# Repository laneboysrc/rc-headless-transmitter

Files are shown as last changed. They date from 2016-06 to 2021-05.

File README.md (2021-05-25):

# Smartphone / Web browser configurable RC transmitter

This project implements a 2.4 GHz RC transmitter using the NRF24L01+ wireless module and the STM32F103C8T6 micro-controller.

The term *headless* comes from the IT industry, where a headless system is one that does not provide a user interface itself, but is rather configured remotely. Within this project, *headless* means that the transmitter does not have a display or buttons for configuration. It relies on remote configuration through a web-browser running on a Smartphone, Tablet or computer.

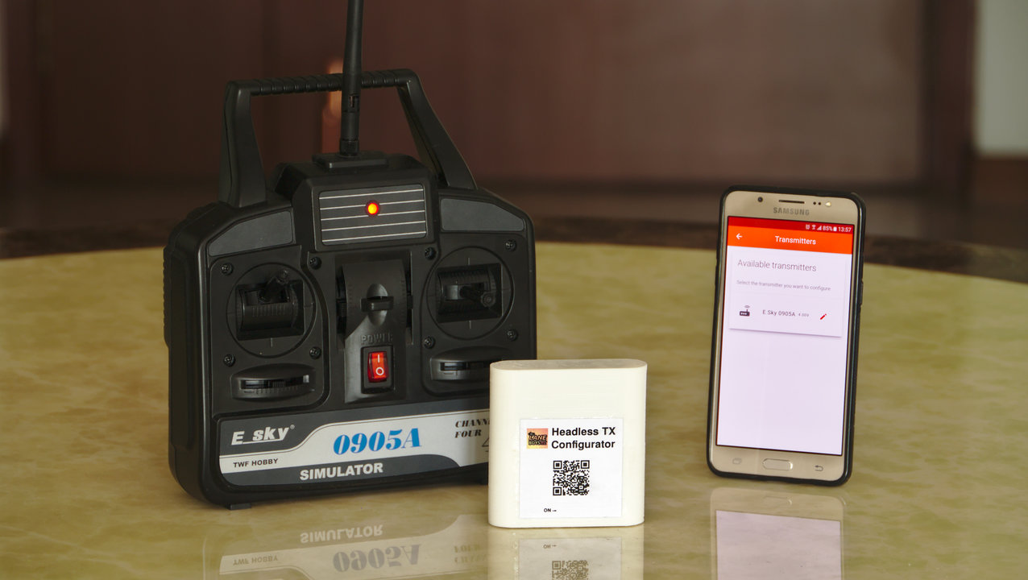
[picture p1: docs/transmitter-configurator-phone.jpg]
transmitter, configurator and web-app


The motivation for this project was to upgrade old AM/FM RC transmitter hardware, and to turn a cheap RC simulator into a fully operational transmitter that supports multiple models.

By keeping the user interface for configuration out of the transmitter, we don't need to perform complicated mechanical modifications to add a display and buttons. We only replace the old electronics with a modern 32 bit ARM micro-controller and a reliable 2.4 GHz transceiver wired on a prototyping board.

The transmitter is currently compatible with HobbyKing HKR3000 and HKR3100 receivers, as well as the [LANE Boys RC nrf24le01-rc](https://github.com/laneboysrc/nrf24l01-rc) DIY receivers. It runs off a 1S Li-Ion battery.

## How it works

The *headless transmitter* works like any low-end 2.4 GHz RC system on the market: power it on, and use it with the model you have it setup for.

However, unlike low-end transmitters, the *headless transmitter* supports advanced features like expo, mixing, failsafe and more.

In order to configure those features, you need to use a web-browser on your Smartphone, Tablet or computer.

To be able to connect your Smartphone to the transmitter, we need to translate between different radio protocols: The transmitter uses a proprietary RF protocol, while the Smartphone supports Wi-Fi. This translation takes place in a small, external box called *configurator*.

When you want to configure your *headless transmitter*, you turn the *configurator* on, connect your phone to the Wi-Fi access-point the *configurator* provides, and launch the configuration web-app to perform the configuration. When you are done, the changes are automatically saved in the transmitter and persist over power cycles.

The *configurator* is built from an **Orange Pi Zero**, with an extra RF module for the connection to the *headless transmitter*.

The Smartphone has a large amount of persistent memory. This allows us to store configurations for multiple models. When we want to reconfigure the transmitter for another model, we simply download the model configuration configuration into the *headless transmitter*. This only takes a few seconds.

The power consumption of the transmitter is low: A single 800 mAh Li-Ion battery keeps the transmitter running for approximately 15 hours. The *configurator* is only used rarely and can be powered from a suitable power bank.

## Cost

When sourcing the modules from China, a transmitter can be built for less than USD 10. The *configurator* hardware cost is less than USD 20. You only need one *configurator*, regardless of how many *headless transmitters* you have.

## Getting started

Please consult the [INSTALL.md](INSTALL.md) file for instructions.

The [docs/](docs) folder contains various documents explaining details for the architecture.

The *headless transmitters* hardware is described in the [transmitter/](transmitter/) folder.

The *configurator* is based on the Orange Pi Zero. Its hardware documentation resides in
[configurator/orangepizero/HARDWARE.md](configurator/orangepizero/HARDWARE.md).

The *web-app* can be accessed from [https://laneboysrc.github.io/rc-headless-transmitter](https://laneboysrc.github.io/rc-headless-transmitter)

## WORK IN PROGRESS

This project is not finished yet. Refer to the [TODO](TODO.md) list for items that we plan to implement in the future.

At the moment the project has only been tested on Android using Chrome and Firefox, and on PCs running Chrome or Firefox.

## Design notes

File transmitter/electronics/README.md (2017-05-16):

This folder contains the schematics and layout of the *headless transmitter* hardware.

[BOM.txt](BOM.txt) contains a list of all components.

The project is made using [KiCad](http://kicad-pcb.org/). For convenience the schematics are also available in [PDF format](stm32f1-nrf24l01-transmitter.pdf).

Note that the PCB designs are not actual circuit board designs, but rather meant to be built on a [Perfboard](https://en.wikipedia.org/wiki/Perfboard).

There are different variants that we adapted to suit different transmitters we modified.

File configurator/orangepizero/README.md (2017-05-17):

This folder contains files related to the Orange Pi Zero-based configurator bridge that allows to configure the headless transmitter via a Wi-Fi connected computer or Smartphone.

Refer to [INSTALL.md](INSTALL.md) of how to configure the Orange Pi Zero.

The [etc/](etc/) and [var/](var/) folders contains sample configuations as described in [INSTALL.md](INSTALL.md).

The [mechanics/](mechanics/) folder contains mechanical files to 3D-print a case for the Orange Pi Zero.

The [openocd/](openocd/) folder contains script and configuration files to flash the nRF51822 and STM32F103 from the Orange Pi Zero. Refer tp [openocd/README.md](openocd/README.md) for details.

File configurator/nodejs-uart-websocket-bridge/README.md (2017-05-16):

# UART to Websocket bridge protocol

This tool can be connected to a *headless transmitter* via the UART. It exposes the *headless transmitter* to a *configurator* using the WebSocket protocol.

This program is used on the Orange Pi Zero to bridge the nRF51822, which in turn bridges the UART to the *headless transmitter*, to the web-app.

Please refer to the [configurator](../../docs/configurator.md) documentation for more information.

## Build instructions

Install NodeJS [http://nodejs.org/](http://nodejs.org/)

Run `npm install` to fetch the required modules.

You can then run `npm start /dev/ttyS1`.

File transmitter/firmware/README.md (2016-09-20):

This directory contains the firmware that goes into the [*headless transmitter*](https://github.com/laneboysrc/rc-headless-transmitter).

It runs on the STM32F103C8T6 micro-controller.

The software makes used of [libopencm3](http://libopencm3.org/).

The firmware is built using a [GNU Make](https://www.gnu.org/software/make/) makefile. The compiler is [ARM GCC toolchain](https://launchpad.net/gcc-arm-embedded), version 5.2.1. [OpenOCD](http://openocd.org/) is used to program the firmware into the micro-controller.

In the [Makefile](Makefile), adjust the variable `GNU_INSTALL_ROOT` and `OPENOCD` to match your installation.

Run

    make

to build the firmware. When done, run

    make program

to flash the firmware into the micro-controller.

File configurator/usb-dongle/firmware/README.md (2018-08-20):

This directory contains the firmware that implements a WebUSB compatible dongle. The dongle can be used by the web-app when using a browser with WebUSB support (currently Chrome/Chromium only).

It runs on the STM32F103C8T6 micro-controller that controls the nrf51-nrf-uart-bridge.

The software makes used of [libopencm3](http://libopencm3.org/).

The firmware is built using a [GNU Make](https://www.gnu.org/software/make/) makefile. The compiler is [ARM GCC toolchain](https://launchpad.net/gcc-arm-embedded), version 5.2.1. [OpenOCD](http://openocd.org/) is used to program the firmware into the micro-controller.

In the [Makefile](Makefile), adjust the variable `GNU_INSTALL_ROOT` and `OPENOCD` to match your installation.

Run

    make

to build the firmware. When done, run

    make program

to flash the firmware into the micro-controller.

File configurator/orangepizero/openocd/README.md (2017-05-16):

If you don't have a SWD programmer to flash the nRF51822 or the STM32F103, you can use the Orange Pi Zero in conjuction with the Open OCD.

    git clone https://github.com/ntfreak/openocd
    sudo apt-get install libtool texinfo pkg-config

    cd openocd
    ./bootstrap
    ./configure --enable-sysfsgpio
    make
    sudo make install

This folder contains two configuration scripts and shell scripts to flash the nRF51822 or STM32F103C8T6. They use different GPIO ports on the Orange Pi Zero, which means the nRF51822 can stay connected when flashing the STM32F103.

The nRF51822 uses pins

    3 GPIO12        SWCLK
    5 GPIO11        SWDIO

the STM32F103 uses pins

    16 GPIO19       SWCLK
    18 GPIO18       SWDIO

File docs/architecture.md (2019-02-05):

# Headless TX  |  STM32F1 NRF24L01+ Headless Transmitter Architecture

## Model vs Transmitter hardware configuration

* Ideally we are able to drive the same car (airplane, boat ...) with different transmitter hardware, with the system automatically adapting to the transmitter hardware
* This implies that inputs are tagged (e.g. Aileron, Rudder, Elevator, Steering, Throttle, Gear, ST-Trim, ST-DR, TH-Hold ...) so that the mixer can read from the right values
* An input may have multiple tags (Steering, Rudder) but each tag must only be assigned once
* Inputs may have 0..100 on one transmitter, and -100..0..100 on another one, i.e. they may be with or without center point!
* If a mixer can not find its input, the input is considered value "0" (center position)
* The direction is normalized:
  - forward, more, right: positive values
  - backward, less, left: negative values

    Note: this is in line with the HobbyKing HK310. However, in the old 27MHz
    AM car transmitters the behavior is different
      - backward, right: positive values
      - forward, left: negative values

* So the "mixer" describes the vehicle, but the input section describes the transmitter
* The *configurator* can change mixer configuration as well as hardware configuration

* Trims have to be assignable to a specific input. Trims may be either a pair of push-buttons or a potentiometer, or be mechanical (i.e. not existent from a software point-of-view).

## Overall transmitter architecture

    +----------------+    +-----------------------------------+    +------------+   +--------+
    |                |    |                                   |    |            |   |        |
    |     INPUTS     |    |              MIXER                |    |  CHANNELS  |   |   RF   |
    |                |    |                                   |    |            |   | module |
    |                |    |   +---------------------------+   |    |  +-------+ |   |        |
    |  sticks,       |    |   |        Mixer unit         |   |    |  |  RF   | |   |        |
    |  pots,         |    |   +---------------------------+   |    |  |      +------->       |
    |  push-buttons  |    |   +---------------------------+   |    |  |       | |   |        |
    |  switches    +------->  |        Mixer unit         |  +------> +-------+ |   |        |
    |                |    |   +---------------------------+   |    |  +-------+ |   |        |
    |                |    |   +---------------------------+   |    |  |Virtual| |   |        |
    |                |    |   |                           |   |    |  |       | |   |        |
    |                |    |   +---------------------------+   |    |  |       | |   +--------+
    |                |    |                                   |    |  +-------+ |
    |                |    |                                   |    |            |
    +----------------+    |                                   |    +-----+------+
                          |                ...                |          |
                          |                                   |          |
                          |                                   |          |
                    +------>  +---------------------------+   |          |
                    |     |   |        Mixer unit         |   |          |
                    |     |   +---------------------------+   |          |
                    |     |                                   |          |
                    |     +-----------------------------------+          |
                    |                                                    |
                    |                                                    |
                    +----------------------------------------------------+

    (Diagram made with the awesome asciiflow.com)

## Inputs
To achieve maximum flexibility, the inputs (sticks, switches, pots etc) of the transmitter have been abstracted in three levels.

### PCB inputs
*PCB inputs* describe all available input ports on the circuit board of the transmitter, and their potential function. Since *PCB inputs* are determined by the hardware, they are a compile-time only configuration.

In software we reference them as *pcb_inputs*.

The STM32F103C8T6 based hardware using the AliExpress board has the following *PCB inputs*:
* 9 analog/digital inputs
    * Can be configured as analog or digital inputs
* 8 digital inputs

### Hardware inputs

Some, or all, *PCB inputs* are connected to control devices such as sticks, pots or switches in a particular transmitter. We refer to those as *Hardware inputs*. There is a 1:1 relationship between a *Hardware inputs* and a *PCB inputs*. A *Hardware input* narrows down the *PCB input* type to one of the following:

* Analog with center detent, spring-loaded auto-return to center: -100..0..100
* Analog with center detent: -100..0..100
* Analog without center detent: -100..100
* Analog without center detent, positive only: 0..100
* Switch on/off: Open / Vcc (pull-down)
* Switch 3-position:  GND / Open / Vcc
* Momentary: Open / Vcc (pull-down)

The analog type *Hardware inputs* can only be assigned to *PCB inputs* of type analog/digital.

For the analog inputs the *Hardware input* data structure holds the endpoint- (and where applicable center-point) calibration values.
*Hardware inputs* are usually setup once when configuring a newly built transmitter.

In software, we reference *Hardware input* as *config.tx.hardware_inputs*.

### Logical inputs
One or more *Hardware input* can be combined to form a *Logical input*, which can be referenced as user input for the mixer.

Like *Hardware inputs*, *Logical inputs* are configured once for each physical transmitter hardware and do not need to be changed when configuring models.

Every logical input can have up to 5 *labels* that indicate the potential function of the input. This way one transmitter can have a "Dual Rate" switch, while another one can have a "Dual Rate" potentiometer. The mixers in the model configuration use the *label* "Dual Rate" to retrieve the input values regardless of the type.

In software, we reference the *Logical inputs* as *config.tx.logical_inputs*.

There are several types of *logical inputs* available

* Analog
    * Can only have a single Analog type *Hardware input* assigned
* Momentary
    * Can only have a single Momentary type *Hardware input* assigned
* Switches
    * n-position switch
        * Can have a single Momentary type *Hardware input* assigned
            * Each press toggles to the next position
            * Can be configured to:
                * increment, loop
                * decrement, loop
                * saw-tooth
                * single-click increment, double-click decrement
            * Transmitter beeps the current number?
        * Can have a two Momentary type *Hardware input* assigned
            * up/down
        * n=2: can have a single on/off switch *Hardware input* assigned
        * n=3: can have a single 3-position switch *Hardware input* assigned
        * n=4..12 can have n on/off switches *Hardware input* assigned
            * In theory we could do with n-1 digital inputs, using the state when all inputs are open as first position. However, this may cause issues that the first position is triggered when switching between the other positions, as contacts may temporarily open.
            * Therefore it is better to use n inputs and treat "all inputs open" as well as "more than one input closed" as error condition.
    * BCD switch n=2..4
        * Must have n on/off switches *Hardware input* assigned
        * Output values are 0..(2^n-1)
* Trims
    * Can have two Momentary type *Hardware inputs* assigned (up/down)
    * Can have a single Analog type *Hardware input* assigned (with or without detent, but must not be *Analog without center detent, positive only* or *Analog with auto return to center*)

**Every *Switch* or *Trim* that uses a Momentary type *Hardware input* must remember their state across power cycles**

### Input API
The mixer can access the inputs by passing a *label* to one of the following input functions.
If no input with the label is configured, the value returned by any of the functions is '0'.

`INPUTS_get_value(label_t l)`
Returns the value for the input with the label *l* in the range of

    CHANNEL_100_PERCENT .. CHANNEL_CENTER .. CHANNEL_N100_PERCENT

`INPUTS_get_switch_value(label_t l)`
The  *switch value* for Momentary and Switch functions is 0..n, where n is the number of positions the switch has. The  *switch value* for analog inputs is 0 or 1, depending whether the analog input is -100..0 or 0..100.
The switch value is retrieved in mixer-units to check whether a mixer-unit is enabled or disabled.

`INPUTS_get_trim(label_t l)`
Returns the trim value for the input corresponding to the label.

## Mixer
The mixer is derived from the DeviationTx project, but modified. The mixer calculates signed values where 100% corresponds to the value 10000. Internally the mixer calculates with signed 32 bit resolution.

### Mixer unit
The mixer unit is derived from the DeviationTx project. Each mixer-unit performs a simple function:

    if (Switch) then
        Destination  op  f(Curve, OptionalInvert(Source)) * Scalar + Offset + OptionalInvert(Trim)
    endif

where:
  - Switch: a switch state that, if true, enables the mixer unit. If Switch is <None> then the mixer unit is always enabled.
  - Destination: The destination channel that receives the output of the mixer unit.
  - op: The operation to perform. Can be
    * = replace destination channel value with output of the mixer unit),
    * += add mixer unit output to current destination channel value
    * *= multiply mixer unit output, with `CHANNEL_100_PERCENT` being treated as 100%, with the current destination channel value
    * MAX (whichever is greater, the current output channel value or the output of the mixer)
    * MIN (whichever is smaller)
  - f(): One of the curve functions applied to the input source
  - OptionalInvert: Switch to invert the incoming Source
  - Source: The input source for the mixer unit. Can be
    - Phyiscal transmitter inputs (sticks, pots, switches, push-buttons)
    - Channels (output channels as sent to the receiver)
    - Virtual channels (10 available for intermediate results in chained mixer units)
  - Scaler: A scaling factor
  - Offset: An offset value to move the result up or down
  - Trim: If enabled then the trim value (range +/-100) is added to the mixer unit output, taking source channel inversion into account

Multiple mixer units can be configured to operate on the same destination. The order of which the mixer units are configured plays an important role of the final resulting channel value.

The mixer unit also receives a *tag* that is not used by the transmitter but provides information to the mixer UI in the *configurator*. Since high-level mixers in the UI may require more than one mixer-unit to implement, the UI can use the tags to identify the mixer-units that belong together and the corresponding high-level mixer function. This is currently not implemented.

### Output channel configuration
After all mixers have been processed, each output channel has a value that needs to be sent to the receiver over the air. Before passing the channel value to the radio protocol, a final set of operations are performed to tweak the corresponding servo outputs:

- Normal/Reverse
- End points -/+
- Sub-trim (applied after scale/endpoints; We want this independent of scale)
- Fail-safe value
- Limit +/ (just hard limits, checked last)
- Speed (0..250, speed of output change in *degrees per 100 ms*)

## Battery indication:

* LED lights up when powered
* LED blinks when battery is low
* Regular beep when battery is low, changing to a more alarming sound when the battery is nearly depleted
* PWM output to drive an analog meter, configurable to adjust full-scale value

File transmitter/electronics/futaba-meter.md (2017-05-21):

# Futaba FP-2F analog meter

R = 400 Ohm
Full scale: 450 mV /
Red to orange: 225 mV /

The needle moves until 480mV (needle at far right), which should be our design maximum.

So we need a voltage divider from 3.3V to 0.48V, with the bottom resistor being 400 Ohm

      3.3       0.48            3.3 * 400
    ------- = -------   =>      --------- - 400 = x   =>   x = 2350 ohm  ~ 2200 Ohm
    x + 400     400                0.48

If we use 2k2, we get a maximum voltage of 508 mV, which is plenty.

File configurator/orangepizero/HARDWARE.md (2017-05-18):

# Hardware parts
Orange Pi Zero (256 MB):
[https://www.aliexpress.com/store/product/New-Orange-Pi-Zero-H2-Quad-Core-Open-source-development-board-beyond-Raspberry-Pi/1553371_32760774493.html](https://www.aliexpress.com/store/product/New-Orange-Pi-Zero-H2-Quad-Core-Open-source-development-board-beyond-Raspberry-Pi/1553371_32760774493.html)

The CPU on the Orange Pi Zero runs very hot, even when idling. It is recommended that you obtain a suitable heat sink.

CORE51822 (B):
[https://www.aliexpress.com/wholesale?catId=0&initiative_id=SB_20170515221607&SearchText=core51822+b](https://www.aliexpress.com/wholesale?catId=0&initiative_id=SB_20170515221607&SearchText=core51822+b)

NOTE: other nRF51822 based modules may work as well, but have different pin-outs. You must ensure to match the pin names instead of the module pin numbers!

You need a Micro SD card. 4 GB is plenty, but nowadays cards start at 16 GB anyway.
Do get a good, reliable card! We have good experience with Sandisk Ultra 16 GB (SDSQUNC model, red and silver color).

# Connections

The CORE51822B modules gets connected to the Orange Pi Zero 26-pin header as follows:

    Orange Pi Zero                    CORE51822B
    (26 pin connector)

    1  3V3                            12 VCC
    3  GPIO12 (SWCLK)                 32 SWCLK
    5  GPIO11 (SWDIO)                 31 SWDIO
    6  GND                            11 GND
    8  UART1_TX                       25 P11 (`UART0_CONFIG_PSEL_RXD`)
    10 UART1_RX                       23 P09 (`UART0_CONFIG_PSEL_TXD`)

# Optional shut-down button

Unless you are using a "frozen file system" on the Orange Pi Zero, one should always shut the operating system down before removing power to avoid accidental corruption of the file system.

For this purpose the configurator can monitor a push-button on GPIO6 of the Orange Pi Zero. When the button is held for more than 2 seconds the Orange Pi Zero shuts down.

    Orange Pi Zero
    (26 pin connector)

    7  GPIO6                          power-off button

The power-off button switch to GND (Orange Pi Zero pin 6) and must have a 1..100k Ohm pull-up resistor to 3V3 (Orange Pi Zero pin 1).

                               +
                               | 3V3
                               |
                               |
                               |
                             +---+
                             |   |
                             |   | 1..100kOhm
                             |   | value not critical
                             |   |
                             +---+
                               |
                               +----------------+  GPIO6
                               |
                               |
                           X   +
                       +   XXX
                       +----+XX     push-button
                       +      XX
                               X
                               |
                               |
                               |
                               |
                               |    GND
                              +-+

# Optional OpenOCD SWD programming pins for the STM32F103C8T6 in the transmitter

If you don't have an ST-Link or similar programmer for the STM32F103 used in the transmitter, you can program it with the Orange Pi Zero. The following pins need to be connected.

    14 GND    -> STM32F1 GND
    16 GPIO19 -> STM32F1 SWCLK
    18 GPIO18 -> STM32F1 SWDIO

The [openocd/](openocd/) folder contains a shell script and configuration file to use those pins.

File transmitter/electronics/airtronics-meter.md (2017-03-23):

# Airtronics analog meter

R = 670 Ohm
Full scale: 400mV / 600uA
Orange to full: 200mV / 300uA
Red to orange: 140mV / 200uA

The needle moves until 500mV (needle at far right), which should be our design maximum.

So we need a voltage divider from 3.3V to 0.5V, with the bottom resistor being 670 Ohm

      3.3       0.5             3.3 * 670
    ------- = -------   =>      --------- - 670 = x   =>   x = 3752 ohm  ~ 3900 Ohm
    x + 670     670                0.5

If we use 3k9, we get a maximum voltage of 483 mV, which is plenty.

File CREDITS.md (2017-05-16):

This project would not have been possible without the LANE Boys beinging able to stand on the shoulders of giants:

### Deviation

http://deviationtx.com/

A replacement firmware designed primarily for the Walkera Devo series RC Transmitters. Great project to study RC transmitter architecture.

### ER9X

https://github.com/MikeBland/mbtx

er9x/ersky9x radio firmware. This is how it all started. Thanks!

### libopencm3

http://libopencm3.org/

Open Source ARM Cortex M microcontroller library. Light-weight, easy to use, not too much abstraction. Just works!

### KiCAD

http://kicad-pcb.org/

Make truely open Schematics and Circuit Boards with this easy to use software.

### Material Design Lite

https://getmdl.io/

MDL allowed us to get a reasonable modern UI with little skills required. No complicated tool chain, just JS and CSS required.

### Google fonts

https://fonts.google.com/specimen/Roboto
https://design.google.com/icons/

The icon font was especially helpful to get consistent looking icons. Super!

### sw-precache

https://github.com/GoogleChrome/sw-precache

Need to make your web-app work offline? Unbelievably easy with this brilliant project!

### spinkit

http://tobiasahlin.com/spinkit/

A nice and easy to use library of CSS spinners.

### Gnu GCC

https://launchpad.net/gcc-arm-embedded

Fantastic compiler. Any platform. Just works.

### OpenOCD

http://openocd.org/

Powerful debugger and programmer. Excellent out-of-the-box experience and soooo configurable.

### STM

http://www.st.com/

Excellent value for money micro-controllers. Their ST-Link debugger comes on inexpensive Nucleo boards and works great even for programming the Nordic MCU.

### Nordic

http://nordicsemi.com/

Great 2.4 GHz Radio, decent software stack, fair price. Thanks for opening up your SDK and documentation in the recent years!

### Armbian

https://www.armbian.com/

Makes cheap Orange Pi boards work!

### Node.js and npm

https://nodejs.org/en/
https://www.npmjs.com/

Normally we use Python for scripts and utilities. But since Node.js was needed for using Webpack anyway, we used it instead. Worked great thanks to the library support at npm.

### Webpack and "Developing with Webpack"

http://webpack.github.io/
http://survivejs.com/webpack/developing-with-webpack

Web front-end development has become surprisingly complicated -- tool-wise -- in the last years. Thanks due to the guide at survivejs we were able get Webpack do what we needed without having to spend a lot of time.

### JSHint, ESLint

http://jshint.com/
http://eslint.org/

Great to find mistakes in the editor before you see them in the console log of your browser.

### strftime for JavaScript

https://github.com/samsonjs/strftime

Pity that this functionality isn't in the Javascript Date library. Thanks for scratching an itch.

### Sortable

http://rubaxa.github.io/Sortable/

Brilliant library to enable interactive re-ordering of lists. Super-simple to use, yet powerful.

### PathJS

https://github.com/mtrpcic/pathjs/blob/master/path.js

Old-skool client-side routing library that allowed us to make a single page web-app. Surely considered outdated, but just right for our needs.

### Favicon Generator

http://realfavicongenerator.net/

Great on-line tool to make all the different flavors of icons needed to get a modern web-app integrated on various platforms.

### Mozilla Developer Network MDN

https://developer.mozilla.org/en-US/

The MDN was extremely helpful to brush up on the latest web technologies. The articles are concise and link to references.

### StackOverflow

http://stackoverflow.com/

Have a programming-related problem? This excellent community sure has it solved already.

### DuckDuckGo

https://duckduckgo.com/

Just like Google was in the beginning.

### Can I Use.com

http://caniuse.com/

Extremely useful website to decide which of the hot new web technologies can be actually used.

### OpenSCAD

http://www.openscad.org/

The Programmers Solid 3D CAD Modeller. What a pleasure to use!

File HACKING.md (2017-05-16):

This project uses different type of microcontrollers:
* [STM32F103](http://www.st.com/content/st_com/en/products/microcontrollers/stm32-32-bit-arm-cortex-mcus/stm32f1-series/stm32f103.html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)
* [Nordic nRF51822](https://www.nordicsemi.com/eng/Products/Bluetooth-low-energy/nRF51822)

On the software side, you need to be familiar with [Git](https://git-scm.com/), the [ARM GCC toolchain](https://launchpad.net/gcc-arm-embedded), [GNU Make](https://www.gnu.org/software/make/), [OpenOCD](http://openocd.org/) and the [ST-Link programmer](http://www.st.com/content/st_com/en/products/development-tools/hardware-development-tools/development-tool-hardware-for-mcus/debug-hardware-for-mcus/debug-hardware-f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).

If you are on Windows it may be easier to compile the software with [Git Bash](https://git-for-windows.github.io/) shell.

The web interface and associated dev tools are built in JavaScript using [Node.js](https://nodejs.org/), [Webpack](http://webpack.github.io/) and the [Material Design Lite framework](https://getmdl.io/).

**IMPORTANT**
This project makes use of Git submodules. Please clone it by running:

    git clone --recursive https://github.com/laneboysrc/rc-headless-transmitter.git

Alternatively, run the following commands in the project root:

    git submodule init
    git submodule update

---

# GH-PAGES

We can host the web-app via Github pages conveniently. Since it is served via HTTPS we can use ServiceWorker and other goodies.

## Setup

In the root of the project, execute

    git clone https://github.com/laneboysrc/rc-headless-transmitter.git --branch gh-pages --single-branch gh-pages

This creates a folder named `gh-pages` with the web-app source code, cloned from the current state of the rc-headless-transmitter's `gh-pages` branch. Note that the `gh-pages` is in `.gitignore` of the `master` branch, so it does not appear in the `master` branch.

When building the web-app (run `npm run build` in `configurator/web-app`), the files are automatically placed into the `gh-pages` folder.

To update the web-app on Github, go into the `gh-pages` folder, commit the changes, and run `git push`.

Source:
[http://stackoverflow.com/questions/1778088/how-to-clone-a-single-branch-in-git](http://stackoverflow.com/questions/1778088/how-to-clone-a-single-branch-in-git)

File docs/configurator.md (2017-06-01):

# Configurator

Since the *headless transmitter* does not have a user interface, we need an external device to configure it. We call this device or software *configurator*.

When connected to a *headless transmitter*, the *configurator* can provide the following functions:

* Live configuration of inputs, mixers, sub-trim values, end points, etc
* Live configuration of the transmitter hardware (inputs, their names and types, trims, invert)
* Live mixer configuration (expo, dual-rate, 4-wheel steering, elevons ...)
* Live output configuration (reversing, endpoints, sub-trim ...)
* Calibration function for analog inputs (sticks, pots)
* Live display of stick, pot, switch, push-button, trims and output channel data
* Show the battery state

The *configurator* can also provide other functionality:

* Maintain a database of models and transmitter configurations

The *configurator* functionality can be implemented in different ways:

* Custom device

    Dedicated embedded device with display and buttons. Similar to a programming box for an ESC.

* Web-app

    An application that runs in a Web browser

* Smartphone app

Using the a *web-app* as *configurator*, which works in any modern browser, is the most attractive option as it can be used on a wide range of devices: PC, Smartphone, Tablet.

Smartphones even allow web-apps to be installed as icon on the home screen and run full-screen. They can also pre-cache the whole web-app, so it can be even accessed when there is no Internet connection. This way we get an app-like user experience.

## Principle of operation

The *headless transmitter* performs its operation based on a configuration that is stored in its persistent memory (Flash memory of the micro-controller). The configuration determines which inputs provides what functions, and how the inputs are mixed to form output channels. Please refere to the [architecture documentation](architecture.md) for details.

The firmware is designed such that the configuration can be changed at run-time; the *headless transmitter* firmware applies the configuration dynamically.

The configuration comprises of settings that are *hardware specific*, and setting that are *model specific*. While the hardware and model specific settings are kept separate, they are stored in one area of consecutive memory.

The *headless transmitter* provides an API that allows an external device -- the *configurator* -- to change the configuration.

The API is very simple: Read parts of the configuration memory, write parts of the configuration memory, and copy from one memory area to another memory area within the configuration memory.

The advantage of this method is that the implementation in the *headless transmitter* is very simple. On the down-side, the *configurator* must know the precise memory layout of the all the elements within the configuration memory.

## Transports

The *configurator* must be able to connect to a *headless transmitter* in order to perform operations on the API provided by the *headless transmitter*.

The *headless transmitter* offers the following transports natively:

* nRF Enhanced Shockburst protocol

    The nRF protocol makes use of the nRF24L01 used to send data to the model. *configurator* data is sent in pauses when no model transmission is taking place.

* UART protocol

    The UART (serial port) protocol is available by connecting to the UART provided by the micro-controller. The UART protocol is currently not implemented on the *headless transmitter*, but used internally in the *nrF-to-WebSocket bridge* described below.

The design goal is to keep the protocol running over the different transports the same, so that the transports appear transparent to the *configurator*.

### Bridging

Unfortunately a *web-app* is not able to utilize any of the transports provided by the *headless transmitter* directly.

To be able to make a *Configurator web-app*, we need a bridging mechanism that goes between the *headless transmitter* and the *configurator* running in the web browser.

On the web browser side, we have **HTTP** and **WebSocket** protocols to our disposals.

Another potential transport would be **BLE**. The *Web Bluetooth* protocol allows web apps to connect to BLE devices. However, *Web Bluetooth* is relatively new and not mature yet.

From a physical implementation point-of-view, the bridge can be a separate box, or integrated into the *headless transmitter*.
We are currently using a separate box as bridge, which can be used for multiple *headless transmitter*. On the down-side, now we have to bring yet another (small) box along while playing with our RC toys.

### Bridge protocol considerations

Ideally the protocol that a *headless transmitter bridge* provides to the *configurator* is equivalent, or at least very similar, to the native transport protocols supported by the *headless transmitter*.

### WebSocket to nRF/UART bridge

The cheapest way to build a bridge with a HTTP/WebSocket interface is by using **ESP8266** modules. The older ESP8266 modules have only a UART interface and not a lot of memory, but newer versions provide access to an SPI port that would allow direct interfacing with a nRF24L01 module.

In order to relief the ESP8266 firmware from the real-time requirements of dealing with the nRF24L01 module, the current bridge implementation uses a nRF51822 module with integrated ARM micro-controller to perform the real-time nRF protocol, sending and receiving information over UART to the ESP8266.

Unfortunately the ESP8266 can not implement a HTTPS server using TLS encryption. TLS is required so that the web-app, which is required to be hosted via HTTPS to access off-line features like ServiceWorker, can access it via secure WebSocket.
We therefore abandoned the ESP8266 implementation. An old, HTTP-based, version can still be found in the project's commit history.

Luckily with the rise of single-board computers (SBC) like the Raspberry Pi, a more powerful alternative is at hand. We opted for the **Orange Pi Zero**. It costs only USD 7 plus shipping (256 MBytes RAM version, good enough for our purpose). It has built-in Wi-Fi that works just fine as Access Point.

On the **Orange Pi Zero** we can install **Armbian**, an **Ubuntu-based OS**, use **NGINX** as web-server serving HTTPS with a self-signed certificate, and run a **NodeJS** program to interface with the nRF51822 module over UART.

In order to minimize interference between Wi-Fi and the nRF protocol, we run Wi-Fi on Channel 11. the nRF protocol uses mostly the lower channels of the 2.4 GHz ISM band.

The *WebSocket bridge* can also be simulated using NodeJS. This allows development of the *web-app* without using actual hardware.

## Security considerations

While this device falls in the category of *Toy*, we still must consider potential security issues.

When the *configurator* connects via the UART directly, the *headless transmitter* can trust the *configurator* -- after all, physical access to the *headless transmitter* was obtained.

Things are different when the *configurator* connects via one of the wireless methods. In case of an open system, anyone with a wireless *configurator* could connect to our transmitter and ruin our day. This may not even be malicious: Other *headless transmitter* users may accidentally connect to our transmitter while trying to configure their own unit.

A simple 4-digit pass-phrase can prevent accidental configuration from happening.

Since the pass-phrase is stored as part of the transmitter configuration, our own *configurator* could automatically log into the transmitter as it can retrieve the pass-phrase from its local database. Others would not have the configuration of our transmitter in their database, so they would need to enter the pass-phrase.

Do note: a malicious user could sniff the pass-phrase while we connect to our transmitter, or obtain it from a sync'ed copy of our database. But then, a malicious user can also sniff our address and bind data and directly manipulate our model; or simply jam the 2.4 GHz band. We therefore consider the pass-phrase being sufficient.

Following tradition, the default pass-phrase of a virgin transmitter is the same as we use on our luggage: '1234'.

## Making the configurator an App-like experience

Web technology has come a long way in the recent years. Today we can make *web-apps* that have an almost native look-and-feel on Smartphones, yet work cross-platform because they are technically web pages. Web-apps can store data on the device persistently, they can be installed to -- and launched from -- the home screen just like a native app, and they can even operate off-line thanks to the awesome *service worker* technology.

*Note: the current configurator web-app has only be tested on Chrome and Firefox, on Android. It is likely that it requires debugging to run on other platforms. Furthermore, only Chrome currently supports off-line web-apps.*

This comes at a small price: in order to be able to utilize a *service worker*, a web-app has to be served from a secure (HTTPS) domain. This, in turn, implies that the *bridge* has to be running over HTTPS as well.

Serving the web-app over HTTPS is quite easy as [Github](https://github.com) kindly provides projects to serve web pages via HTTPS for free ([Github Pages](https://pages.github.com)).

Another compromise we have to make is the use of self-signed certificates on the *nRF-to-websocket* bridge, which trigger security warnings in all modern web browsers. The user will have to go through certain steps to allow this self-signed certificate before the *configurator web-app* can access it.

## nRF protocol details

The nRF protocol integrates with the RF protocol that is employed in the HobbyKing HK300, HK310 and 3XS transmitters. We refer to this protocol as *HK310 protocol* from now on.

### The *HK310 protocol*

The *HK310 protocol* has the following properties:

* The legacy nRF24 protocol (non Shockburst version) is used at 250 KBps
* The address is 5 bytes long and is unique for each model
* All packets sent by the transmitter have a payload length of 10 bytes
* One burst of transmission occurs every 5 ms
* A transmission burst comprises of:
    - Two identical stick (or failsafe) packets, with data for 3 channels
    - A bind packet, sent at low power with a fixed address on channel 81
* After each transmission burst, the the frequency is changed to the next in a list of 20 hop channels

One transmission burst takes about 1.2 ms.

    __MMMM_MMMM_BBBB________________________________MMMM_MMMM_BBBB_________

      <------------------- 5 ms ------------------->

    MMMM: Stick or Failsafe data, sent on the hop channel
    BBBB: Bind packet, sent on channel 81

One challenge in the *headless transmitter* was that, due the use of inexpensive nRF24+PA (power amplifier) module, we were unable to output at a really low RF power. Even at the lowest power setting the bind packets can be received from quite far away. In order to avoid interference with other RC transmitters, the *headless transmitter* therefore only outputs bind packets for the first 10 seconds after power on.

### Integrating with the *HK310 protocol*

We extend the transmission burst of the *HK310 protocol* with one more *configurator packet*. This implies that one *configurator packet* is sent every 5 ms.

    __MMMM_MMMM_BBBB_CCC____________________________MMMM_MMMM_BBBB_CCC_____

      <------------------- 5 ms ------------------->

    MMMM: Stick or Failsafe data, sent on the hop channel
    BBBB: Bind packet, sent on channel 81
    CCC: Configurator packet at 2 Mbps

The *configurator packet* use a different radio setup than the *HK310 protocol*:

* Enhanced Shockburst with auto-acknowledge (AA) enabled, with optional ACK payload
* 2 MBps data rate
* Variable payload length up to the maximum of 32 bytes
* 2-Byte CRC
* Lowest possible transmit power (at least on the *headless transmitter* side, which utilizes a RF amplifier)
* ARD is set to 500 us

The *headless transmitter* acts as the PTX (Primary role Transmitter, as defined in the nRF24 specification), the *configurator* acts as PRX (Primary role Receiver).

The *configurator* is able to send information to the headless transmitter as part of the Acknowledge procedure when receiving a packet from the *headless transmitter*.

From a protocol point-of-view, one could say that the *headless transmitter* is the master, and the *configurator* is the slave, with the master polling the slave in regular intervals.

### Overcoming reliability issues

Wireless protocols are inherent to interference and poor reception, resulting in lost packets.

To make it easier for users of the nRF protocol, the low-level implementation shall implement a two-byte packet buffer and inspect packet contents.

The nRF protocol is designed in such a way that every request by the *configurator* is answered by the *headless transmitter* in the next packet. For example, a `CFG_READ` packet is answered with `TX_REQUESTED_DATA`; `CFG_WRITE` is answered with `TX_WRITE_SUCCESSFUL`.

In case a transmission error occurs, the next successful packet received from the *headless transmitter* will not match the request sent, so the low-level implementation knows that something went wrong and can resend the packet.

A two packet buffer is required to achieve maximum throughput, as the nRF Shockburst protocol requires us to queue data before we can receive the answer to the previous request.

The above algorithm implies that packets may be executed out of order.

### nRF protocol states

The nRF Shockburst protocol is designed for one pair of PTX and PRX. Since there is a possibility that more than one *configurator* is in use at the same time, we must ensure that integrity is preserved. To achieve this, we only allow one *configurator* to connect to a *headless transmitter* at a given moment in time.

From a protocol view, we achieve this by differentiating between *NOT CONNECTED* and *CONNECTED* state.

### nRF protocol *NOT CONNECTED* state

This is the default state for both the *headless transmitter* and the *configurator*.

All communication in this state happens on the fixed nRF channel **79** with address **4C:42:72:63:78** (`LBrcx` in hex).

The *headless transmitter* sends a `TX_FREE_TO_CONNECT` packet whenever the transmission burst is transmitting on the first model hop channel. This means that `TX_FREE_TO_CONNECT` packets are sent every 100 ms (20 hop channels times 5 ms each).

Since there may be multiple *headless transmitter* on the air, the `TX_FREE_TO_CONNECT` packet contains the 8-byte UUID of the transmitter as well as a human-readable transmitter name so that we can differentiate between transmitters.

The *configurator* listens for `TX_FREE_TO_CONNECT` and shows the user a list of all transmitters in the neighborhood. When the user chooses a transmitter, the *configurator* replies with `CFG_REQUEST_TO_CONNECT` and changes its state to `CONNECTED`.
The `CFG_REQUEST_TO_CONNECT` packet contains the UUID of the transmitter to connect to, the pass-phrase, a unique 5-byte address and hop channel information.

When the *headless transmitter* receives a `CFG_REQUEST_TO_CONNECT` request with a matching UUID and pass-
phrase, it changes its state to `CONNECTED`.

The nRF24 PRX function itself does not provide a method to receive packets without acknowledging them. This would mean that if multiple *configurator* are present, each listening for `TX_FREE_TO_CONNECT` packets, every *configurator* will send ACK responses at the same time, causing issues.

To overcome this problem, the *headless transmitter* broadcasts the `TX_FREE_TO_CONNECT` packets with the `W_TX_PAYLOAD_NOACK` feature of the nRF24. This method transmits a packet without requesting the PRX to acknowledge it. All *configurator* can receive the `TX_FREE_TO_CONNECT` packet but no-one is acknowledging it.

In order to answer the `TX_FREE_TO_CONNECT` packet, immediately after the `TX_FREE_TO_CONNECT` was broadcast the *headless transmitter* sends yet another packet with a single byte payload, but using the lower 5 Bytes of the UUID as address. This packet requests an acknowledgement from a PRX and is unique for each transmitter.

This means that when a *configurator* sends a `CFG_REQUEST_TO_CONNECT` packet, it does so by configuring the address to the lower 5 Bytes of the UUID.

### nRF protocol *NOT CONNECTED* commands

Commands sent by the *headless transmitter* always start with `TX_`. Command sent by the *configurator* always start with `CFG_`.

All data is in little endian format, i.e. the least significant byte is transmitted first.

* `TX_FREE_TO_CONNECT`

    `0x30 uu uu uu uu uu uu uu uu uu tx tx tx tx tx tx tx tx tx tx tx tx tx tx tx tx b0 b1`

    uu:     Transmitter UUID 8 bytes
    tx:     Transmitter name 16 bytes (\0-terminated C-String [A-Z,a-z,0-9 ],
            padded with \0)
    b0, b1: Battery voltage in millivolts. Unsigned 16 bit integer.

    When sending this packet, the auto-acknowledge feature of the nRF24 is disabled. This is acheived by using the `W_TX_PAYLOAD_NOACK` nRF24 SPI command.

    Immediately after the packet was sent, another packet is sent, this time with the auto-acknowledge enabled (regular `W_TX_PAYLOAD` nRF SPI command). This command is sent on the address comprising of the lower 5 Bytes of the transmitter UUID. The payload is

    `0x30`

* `CFG_REQUEST_TO_CONNECT`

    `0x31 uu uu uu uu uu uu uu uu uu a0 a1 a2 a3 a4 p0 p1 oo sd`

    uu:     Transmitter UUID 8 bytes
    a0..4:  5 byte random nRF address to use during the connection
    p0..1:  unsigned 16-bit representation of the 4-digit pass-phrase
    oo, sd: offset and seed for a 7-bit Galois LFSR to calculate the hop channel sequence

    `oo` and `sd` are used to calculate the hop sequence for the configuration session.

    `sd` is the initial state of a [7-bit Galois LFSR](https://en.wikipedia.org/wiki/Linear-feedback_shift_register), `polynomial x^7 + x^6 + 1`. `sd` must be between 1 and 127.
    Offset `oo` is added after each LFSR round, with a modulo of 127.
    Values larger than 69 are skipped so that the resulting hop channels are between 1 and 69 only.

    The following pseudo-code shows how the 20 hop channels used during the *CONNECTED* state are calculated:

        oo = received_oo
        lfsr = received_sd

        function next
            do
                lsb = lfsr & 1;
                lfsr >>= 1;
                if (lsb) {
                    lfsr ^= 0x60;   // x^7 + x^6 + 1
                }
                channel = (lfsr + oo) % 127;
            while (channel > 69  &&  channel in hop_channels);
            // Note: this loop runs worst-case 7 times

            return channel
        end function next

        for i in 0..19
            hop_channel[i] = next()

### nRF protocol *CONNECTED* state

In *CONNECTED* state, the *headless transmitter* sends one packet every 5 ms on the address received in the `CFG_REQUEST_TO_CONNECT` packet, looping through the 20 hop channels derived as described in the previous section.

Note that the first packet after connection is sent on the first hop channel. The *configurator* knows when to expect the packet: ~5 ms after the `CFG_REQUEST_TO_CONNECT` was taken out of its TX buffer by the auto-acknowledge function.

Due to the use of the AA feature of the Shockburst protocol, every packet sent by the *headless transmitter* is acknowledged by the *configurator*, assuming the RF connection is stable and the hop sequence is synchronized.

If the *headless transmitter* does not receive any acknowledgment within a window of 600 ms, it enters the *NOT CONNECTED* state.

If the *configurator* does not receive any packet from from the *headless transmitter* within a window of 600 ms, it enters the *NOT CONNECTED* state. There may be two reasons why the *configurator* never received any packets:

- The `CFG_REQUEST_TO_CONNECT` message was lost or damaged during transmission.
- The pass-phrase was incorrect.

The *configurator* may want to prompt the user for a new pass-phrase in case it tried a pass-phrase automatically -- for example a pass-phrase stored in its database.

While connected, the *configurator* can issue requests to the *headless transmitter* by adding the appropriate command to the auto-acknowledge payload.

When the *headless transmitter* receives a packet acknowledgment without payload, or there was no acknowledgment for whatever reasons, the *headless transmitter* sends an `TX_INFO` command as next packet.

The protocol is designed in such a way that every request from the *configurator* (except `CFG_DISCONNECT`) causes the *headless transmitter* to send a packet that is **not** `TX_INFO` as the next packet. This way the *configurator* can know whether its request has been successfully received: if it is `TX_INFO`, something went wrong and the *configurator* must resend the request.

The *headless transmitter* does not resend packets. Info packets are repeated continuously, so no issue there. Missing responses to *configurator* requests are handled by the *configurator*.

When the *headless transmitter* receives a payload along with the packet acknowledgment, it processes the command and responds with an appropriate answer in the next packet (sent during the next transmission burst; i.e. approx 5 ms later).

### nRF protocol *CONNECTED* commands

Commands sent by the *headless transmitter* always start with `TX_`. Command sent by the *configurator* always start with `CFG_`.

All data is in little endian format, i.e. the least significant byte is transmitted first.

* `CFG_READ`

    `0x72 a0 a1 cn`

    Read a chunk of data from the configuration.

    a0, a1: Offset within the configuration to read, unsigned 16 bit integer
    cn:     Number of bytes to read. Must be between 1 and 29

    The *headless transmitter* provides the requested data in the next packet using the `TX_REQUESTED_DATA` command.

    In case the request lies outside of the configuration data, or count is invalid, the *headless transmitter* ignores the request.

* `CFG_WRITE`

    `0x77 a0 a1 dt ...`

    Write data to the configuration.

    a0, a1: Offset within the configuration to write, unsigned 16 bit integer
    dt:     1..29 bytes of data

    The *headless transmitter* responds with `TX_WRITE_SUCCESSFUL` in the next packet.

    In case the request lies outside of the configuration data, the *headless transmitter* ignores the request.

* `CFG_COPY`

    `0x63 s0 s1 d0 d1 c0 c1`

    Copy a block of data from offset `source` to offset `destination` within the configuration. This command is useful when rearranging, deleting or inserting mixer units. Note that source and destinations may overlap -- the implementation in the *headless transmitter* has to ensure correct behavior (hint: you can not use memcpy).

    s0, s1: Offset within the configuration to copy from, unsigned 16 bit integer
    d0, d1: Offset within the configuration to copy to, unsigned 16 bit integer
    c0, c1: Number of bytes to copy, unsigned 16 bit integer

    The *headless transmitter* responds with `TX_COPY_SUCCESSFUL` in the next packet.

    In case the request lies outside of the configuration data, the *headless transmitter* ignores the request.

* `CFG_DISCONNECT`

    `0x64`

    After receiving this request, the *headless transmitter* immediately enters *NOT CONNECTED* state.

    After this command has been taken out of the *configurator* TX buffer by the auto-acknowledge function, the *configurator* enters *NOT CONNECTED* state.
    Note that this implies that the *configurator* has to wait for the next successful packet received from the *headless transmitter*, which may take up to 600 ms (timeout) if the connection is poor. During this time the *configurator* is still assumed to be *CONNECTED* and must follow the hop sequence.

* `TX_INFO`

    `0x49 i0 i1 d0 d1 d2 d3 ...`

    Sent when there is no pending request from the *configurator*. Contains the current value of selected mixer inputs. See below for more information.

    i0, i1: Identifier for the mixer inputs. Corresponds to the enumeration called `live_t` in the firmware
    d0..3:  Current value of the input. Signed 32 bit integer.

    In total a single packet can contain info of up to 4 `live_t` values.

* `TX_REQUESTED_DATA`

    `0x52 a0 a1 dt ...`

    Sent in the next packet after receiving a `CFG_READ` request.

    a0, a1: Offset within the configuration as requested, unsigned 16 bit integer
    dt:     1..29 bytes of data starting at offset a0, a1

* `TX_WRITE_SUCCESSFUL`

    `0x57 a0 a1 cn`

    a0, a1: Offset within the configuration that was written, unsigned 16 bit integer
    cn:     Number of bytes written

    Sent in the next packet after receiving a `CFG_WRITE` request.

* `TX_COPY_SUCCESSFUL`

    `0x43 s0 s1 d0 d1 c0 c1`

    The parameters are identical to the values received in the `CFG_COPY` request.

    Sent in the next packet after receiving a `CFG_COPY` request.

## WebSocket protocol

The *WebSocket protocol* runs on **wss://192.168.4.1/ws** using TLS encryption.

The *WebSocket protocol* implements the same commands as described above.

One major difference is that the *WebSocket protocol* does not provide real-time transfer of data. As such, a *configurator* talking to a bridge using the *WebSocket protocol* can not rely that the next received packet is the answer to the previous sent command, as it is with the *nRF protocol*.

Since the command structure is designed in such a way that every command has a definite response, the *configurator* has to wait until the appropriate answer arrives before it can send the next command.

The down-side of this approach is that this significantly reduces the achievable through-put, as the *configurator* would have to wait for the answer to the previous request before it can send the next request. Especially on mobile devices this is an issue, as they seem to queue data and transmit infrequently to preserve power.

To overcome this issue, a bridge can implement a packet buffer. A bridge implementing such a buffer sends the following message to a *configurator* immediately upon a WebSocket connection is established:

* `WS_MAX_PACKETS_IN_TRANSIT`

    `0x42 nn`

    nn: maximum number of buffered requests

By default, the *configurator* assumes that the buffer has only a size of 1 packet. Only after receiving the above command it can send multiple packets to the bridge.

The WebSocket protocol is a reliable protocol, as it builds on TCP/IP. As such the implementer does not have to be concerned with wireless issues described in the *nRF protocol*.

WebSocket supports payloads in text format and binary format (BLOB). For the configurator we are using text format, where the binary data is Hex encoded (e.g. a value of 0xa2 is sent as string "A2").
This is done as it turned out that the FileReader object in the Chrome browser, which is required to obtain data from BLOBs in JavaScript, is very slow and caused performance issues.

## UART protocol

The UART runs at 115200 BAUD. Because the UART is a serial line without framing, we need to use a packet framing protocol.

We have chosen for the SLIP protocol, defined in
[RFC 1055](https://tools.ietf.org/html/rfc1055).

The commands are exactly the same as for the *nRF protocol*.

Like the *WebSocket protocol*, the *UART protocol* does not provide real-time transfer of data as underlying implementations usually have a buffer between the serial port and the application. As such the same algorithms as described for the *WebSocket protocol* apply.

The *UART protocol* is considered reliable and therefore does not require special handling for lost or corrupted information.

## APPENDIX: nRF protocol bandwidth estimation

The read/write payload is up to 29 bytes.

The size of the configuration in the *headless transmitter* is 4620 bytes. The model configuration uses 2892 bytes.
(Note: this may have changed after writing this document. Refer to the firmware for the actual number)

Reading the configuration:

    1 packet every 5 ms -> 200 packets per second
    1 read packet == 29 bytes
    4620 bytes to read

    => 160 packets to transfer the whole configuration
    => 800 ms under ideal conditions
    => 5800 bytes per second, 46400 kBps

Writing the configuration:

    1 packet every 5 ms -> 200 packets per second
    1 write packet == 28 bytes
    4620 bytes to write

    => 165 packets to transfer the whole configuration
    => 825 ms under ideal conditions
    => 5600 bytes per second, 44800 kBps

Loading a new model:

    1 packet every 5 ms -> 200 packets per second
    1 write packet == 28 bytes
    2892 bytes to write

    => 104 packets to transfer the whole configuration
    => 520 ms under ideal conditions
    => 5600 bytes per second, 44800 kBps

## APPENDIX: Discussion of *configurator* implementations

There is a multitude of available options of how we could implement the *configurator*:

* Custom device, UART protocol
    - PRO: Stand-alone device; Can be powered from the transmitter; Single device
    - CON: High development effort; Wired connection to the Tx; Potentially limited UI; Medium cost

* Custom device, nRF protocol
    - PRO: Stand-alone device; Wireless; Single device
    - CON: High development effort; Potentially limited UI; Medium cost

* Smartphone app, WebSocket to UART bridge
    - PRO: Great user experience; Low cost
    - CON: High development effort; Wired connection

* Smartphone app, WebSocket to nRF bridge
    - PRO: Great user experience; Wireless; Low cost
    - CON: High development effort

* Smartphone app, BLE to UART bridge
    - PRO: Great user experience; Low cost; Use existing BLE to UART bridge
    - CON: High development effort; Wired connection

* Smartphone app, BLE to nRF bridge
    - PRO: Great user experience; Wireless
    - CON: High development effort; Custom BLE to nRF bridge

* Smartphone app, Bluetooth SPP to UART bridge
    - PRO: Great user experience; Low cost; Use existing SPP module
    - CON: High development effort; Wired connection; High power consumption?

* Web-app, WebSocket to UART bridge
    - PRO: Good user experience; Reasonable development effort; Low cost
    - CON: Wired

* Web-app, WebSocket to nRF bridge
    - PRO: Good user experience; Reasonable development effort; Wireless; Low cost
    - CON:

* Web-app, BLE to UART bridge
    - PRO: Good user experience; Reasonable development effort; Low cost
    - CON: Web Bluetooth not mature yet; Wired

* Web-app, BLE to nRF bridge
    - PRO: Good user experience; Reasonable development effort; Wireless; Low cost
    - CON: Web Bluetooth not mature yet; Custom BLE to nRF bridge

* Chrome app, UART protocol
    - PRO: Good user experience; Reasonable development effort; Low cost
    - CON: Chrome browser on PC only; Wired;

In addition to the list above, we can also consider building any of the web-app options as *Chrome app*. This may be as simple as adding a manifest file.

Some options were not considered:

* Smartphone app, Bluetooth SPP to nRF bridge

    The advantage of Bluetooth SPP is that off-the-shelf modules can be used. By bridging SPP to nRF custom hardware must be built, and for that other options are more attractive.

* Chrome app, UART to nRF bridge

    The main advantage of the Chrome app would be that it offers native serial port support. However, the UART to nRF bridge is non-standard and requires users to build one. This effort would be better directed to one of the *web-app* options, which are more universal. As stated above, the *web-app* may also be packaged as *Chrome app*. Further more, recently Google announced that they will deprecate *Chrome apps*.

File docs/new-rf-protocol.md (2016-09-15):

## RF protocol for more than 3 channels

The HK310 protocol can only support up to 3 channels. Since we now have the
possibility to build our own transmitter and receiver, we can change the
protocol to support more channels. We still want to use the nRF based RF
solution, since it is robust, cheap and we know it well.

## HK300 / HK310 / X3S RF protocol

* 20 hop channels
* 5 byte address
* 3 servo channels
* Stick data sent every 5 ms
* Hop frequency changed every 5 ms
* Failsafe sent

## Requirements of the new protocol

* Based on HK300 protocol
* At least 8 channels
* signed 12 bit, corresponding to 476..1500..2523 us (500 ns resolution)
    - 8 channels, signed 12 bits (0 corresponds to 1500 us servo output == center)
        - So a packet would be 12 Bytes of data, plus one frame identifier
    - More channels can be added by introducing multiple frames. The higher channels could be sent at a
    slower update rate

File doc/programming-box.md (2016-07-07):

# Programming box UI

- *Not connected* (default)
    - *Main screen*:
        - Large connect button
        - Drawer:
            - Models
                - Show *Model list*
            - Transmitters
                - Show *Transmitter list*

    - *Model list*:
        - List of cards, one for each model
            - If card is selected: Show *Model details*
                - *Model details*:
                    - View where the user can edit the following elements:
                        - Name
                        - Mixers and limits; If selected: Show *Mixer*
                            - *Mixer*:
                                - Show mixer units in sequence, their input and output channels
                                    - Select mixer unit: Show *Mixer unit*:
                                        - *Mixer unit*:
                                            - Source (button -> *single selection page*)
                                            - Invert source (on/off switch)
                                            - Destination (button -> *single selection page*)
                                            - Curve (*custom element* -> *curve editing page*)
                                            - Switch (*custom element* -> *page to edit label, comparison, value*)
                                            - Operation (button -> *single selection page*)
                                            - Apply trim (on/off switch)
                                    - Select output channel: Show *Limits*:
                                        - *Limits*:
                                            - EP left (slider)
                                            - EP right (slider)
                                            - Subtrim (slider)
                                            - Limit left (slider)
                                            - Limit right (slider)
                                            - Failsafe (slider)
                                            - Speed (slider)
                                            - Invert (on/off switch)
                                - Back: Show *Model details*
                                - Context menu: Add mixer unit
                                - **FIXME need a way to delete mixer units**
                                    - Swipe out?
                                    - Swipe onto trashbin icon that appears while dragging?
                                    - Context menu while in *Mixer unit*?
                                - **FIXME need a way to re-arrange mixer units**
                                    - Drag-and-drop?
                        - RF Protocol; If selected: Show *RF protocol details*
                            - *RF protocol details*:
                                - RF protocol editing: depends on protocol! Adress, Hop channels
                                - Back: Show *Model details*
                    - Back: Show *Model list*
                    - Context menu: Delete model
        - Back: Show Main screen
        - Context menu: Add model

    - *Transmitter list*
        - List of cards, one for each transmitter
            - If card is selected: Show *Transmitter details*
                - *Transmitter details*:
                    - Tabs: *Hardware inputs*, *Logical inputs*, *Name*
                        - *Hardware inputs*:
                            - List of cards, one for each hardware input
                                - Unused hardware inputs are shown such
                                - Select pcb input (determines possible types!) (button -> *single selection page*)
                                - Select type (button -> *single selection page*)
                                - **FIXME**: how to do calibration?
                        - *Logical inputs*:
                            - List of cards, one for each logical input
                                - Unused logical inputs are hidden; last entry is "add new logical input"
                                - Select type (and subtype if type is momentary) (button -> *single selection page*)
                                - Select number of switch positions if type is switch (slider)
                                - Select or Add/Remove Hardware inputs, depending on type (button -> *multiple selection page*)
                                - Add/Remove labels (button -> *multiple selection page*)
                    - Back: Show *Transmitter list*
                    - Context menu: Delete transmitter
        - Back: Show *Main screen*

- *Connected*
    - Header:
        - Show transmitter name and colored dot with connection state
        - Back: Disconnect; need a prompt?
        - Context menu:
            - Change model
                * Show same view as *Model list* but different behaviour
            - Configure transmitter
                - Show *Transmitter details*
            - Disconnect?
    - Same view as *Model details*
        - Show live bars of the various channels/mixers/outputs

**FIXME: show TX battery state**
**FIXME: slider from MDL are not what we need: no 0 point marker, do not go dim when set to the left**

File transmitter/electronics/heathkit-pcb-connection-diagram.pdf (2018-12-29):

CSN
SCK

MISO

MOSI
IRQ

3V3
GND

nRF24L01+ PA

GND
Tx
Rx
DM
DP
5V
GND

UART USB

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
THR-trim
RUD-trim

SW1
AUX3
AUX2
AUX1
THR

Vsw

Buzzer

BAT-

BAT+

Vsw
Vbat

# POT2 POT1 STICK Trainer Switch Power Switch Battery Buzzer

GND

M+

Meter VIOL
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
VIOL

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
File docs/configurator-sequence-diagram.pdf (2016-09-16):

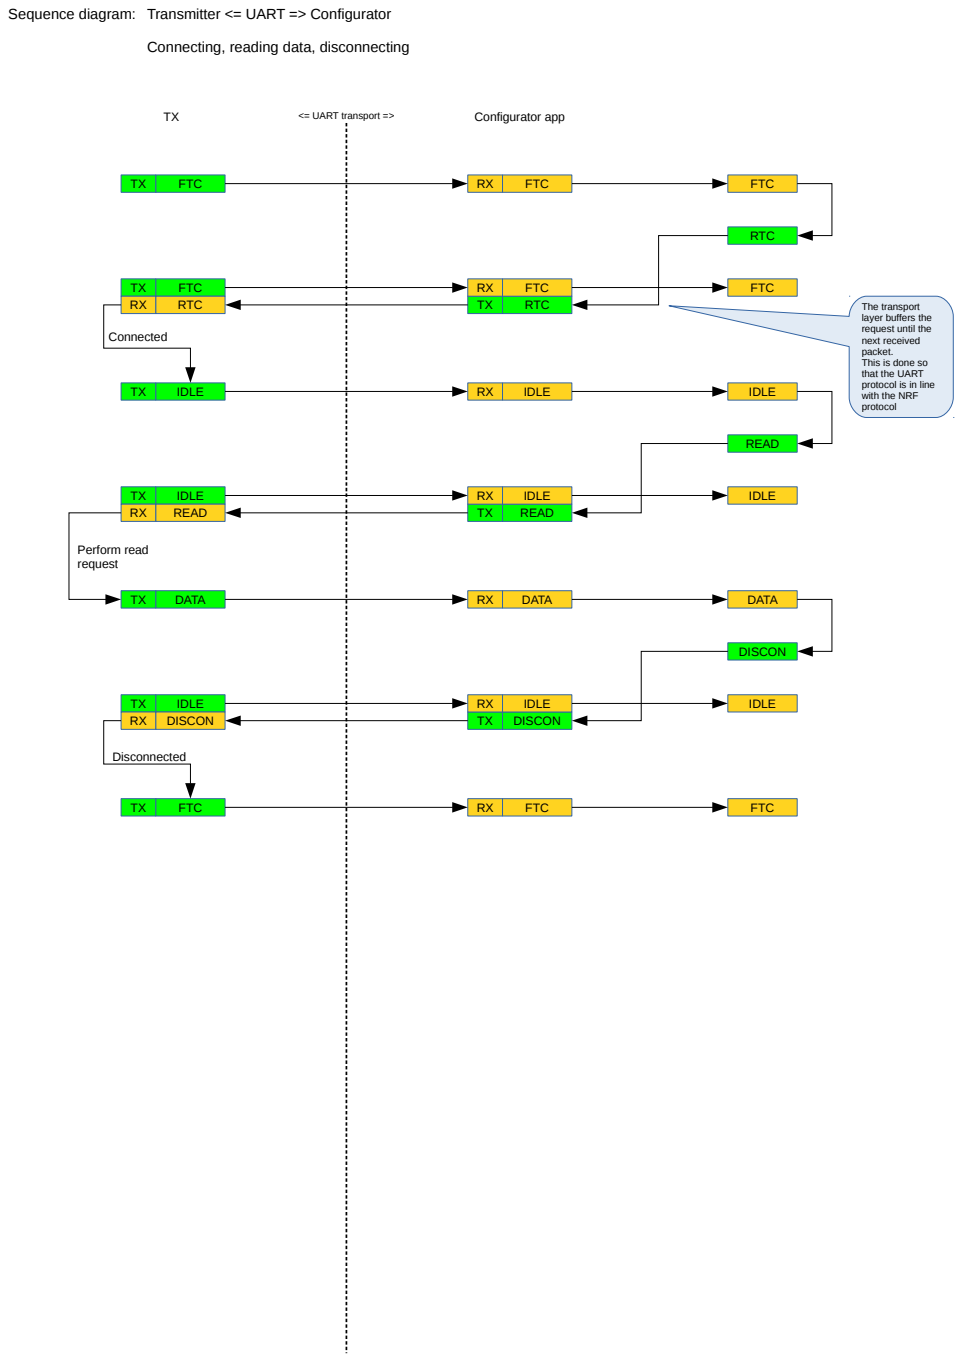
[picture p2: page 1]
FTC; Configurator app; <= UART transport =>; FTC RTC; RTC; IDLE; Connected; IDLE READ; READ; DATA; Perform read request; DISCON; IDLE DISCON; Disconnected

Sequence diagram: Transmitter <= UART => Configurator

Connecting, reading data, disconnecting

The transport
layer buffers the
request until the
next received
packet.
This is done so
that the UART
protocol is in line
with the NRF
protocol

### Sequence diagram: Transmitter <= NRF => Configurator

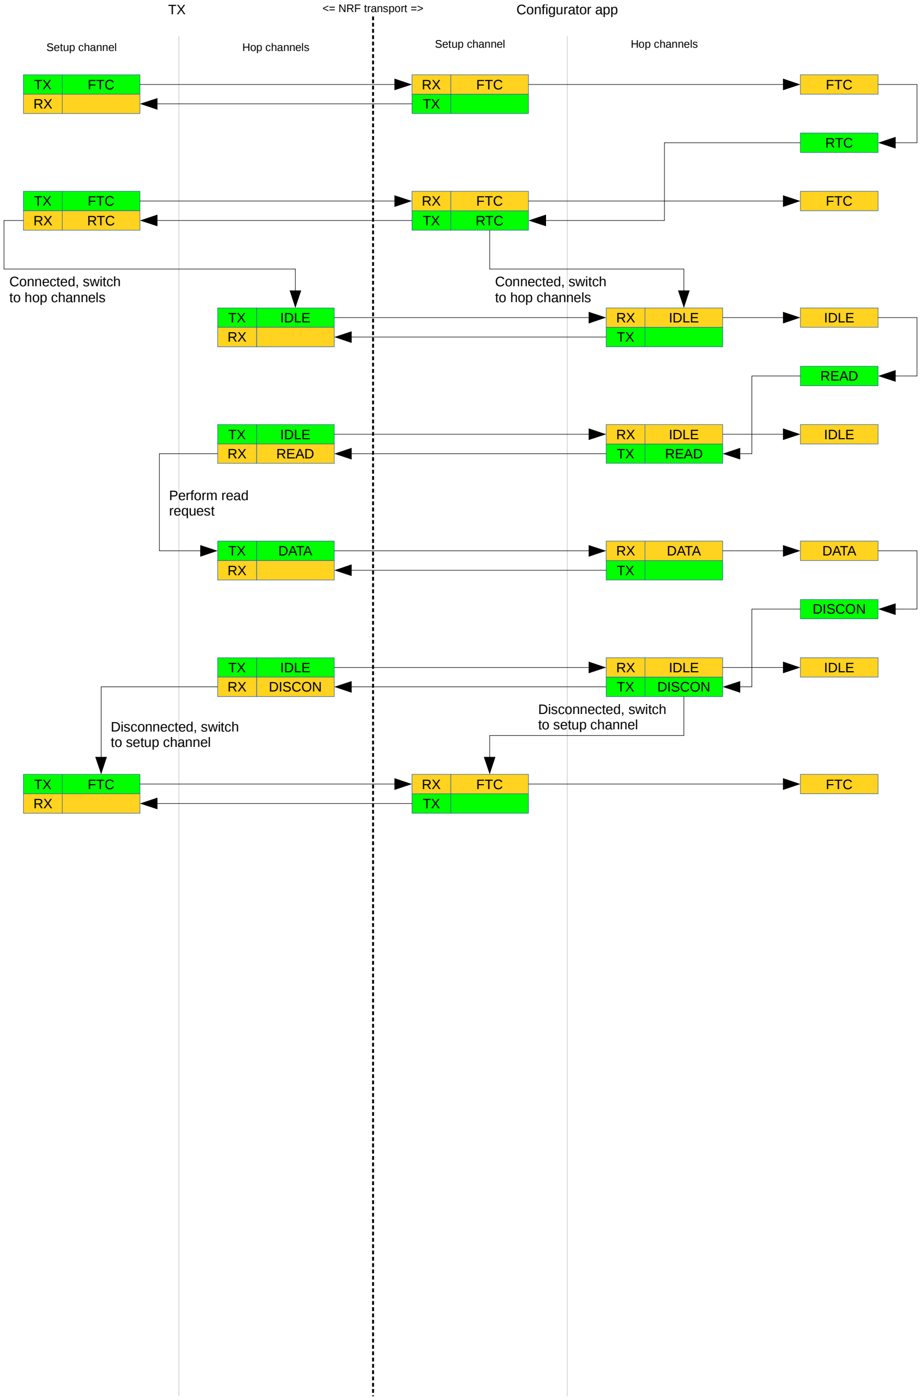
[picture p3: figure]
FTC; Configurator app; Hop channels; Setup channel; <= NRF transport =>; FTC RTC; RTC; IDLE; Connected, switch to hop channels; IDLE READ; READ; DATA; Perform read request; DISCON; IDLE DISCON; Disconnected, switch to setup channel
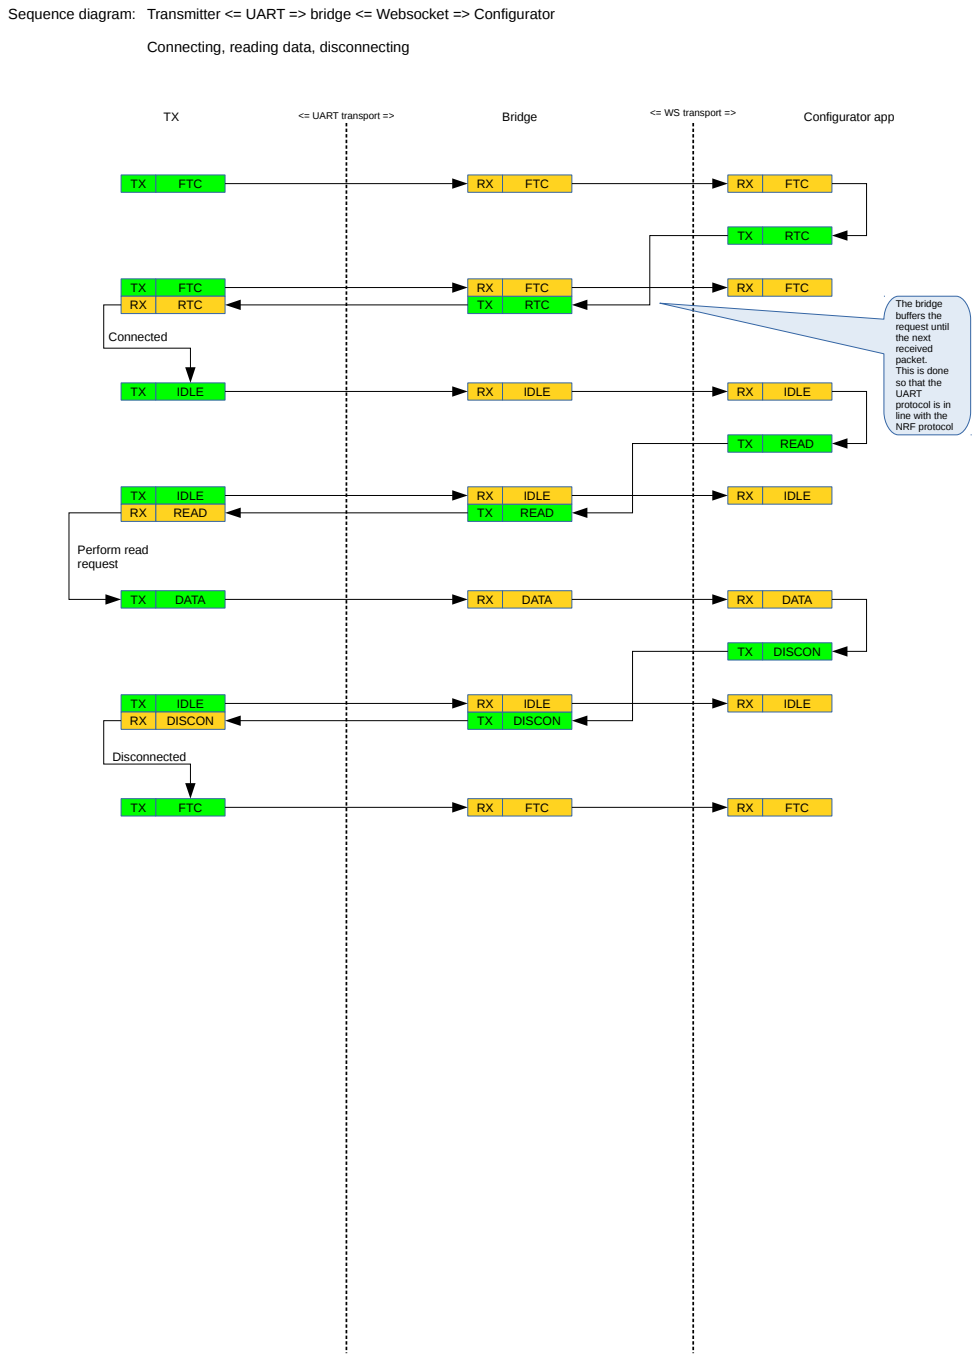
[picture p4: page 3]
FTC; Bridge; Configurator app; <= UART transport =>; <= WS transport =>; FTC RTC; RTC; IDLE; Connected; IDLE READ; READ; DATA; Perform read request; DISCON; IDLE DISCON; Disconnected

Sequence diagram: Transmitter <= UART => bridge <= Websocket => Configurator

The bridge
buffers the
request until
the next
received
packet.
This is done
so that the
UART
protocol is in
line with the
NRF protocol

### Sequence diagram: Transmitter <= NRF => bridge <= Websocket => Configurator

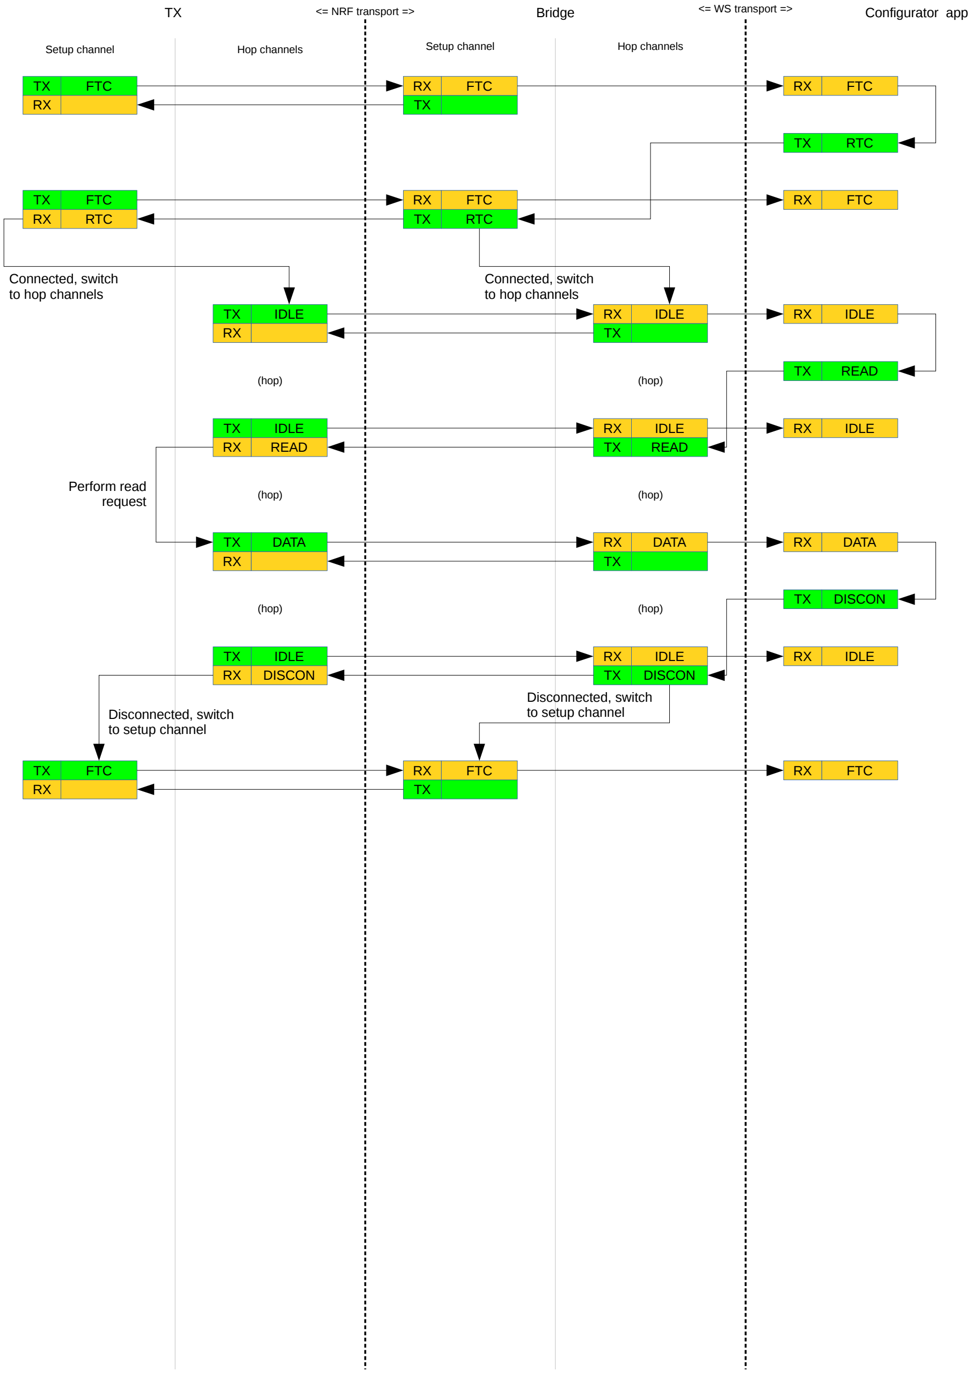
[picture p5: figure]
FTC; Bridge; Configurator app; Hop channels; Setup channel; <= NRF transport =>; <= WS transport =>; FTC RTC; RTC; IDLE; Connected, switch to hop channels; IDLE READ; READ; DATA; Perform read request; DISCON; IDLE DISCON; Disconnected, switch to setup channel; (hop)

### Sequence diagram: Transmitter <= NRF => bridge <= Websocket => Configurator

### Multiple transmitters present, Connecting to a particular transmitter, disconnecting

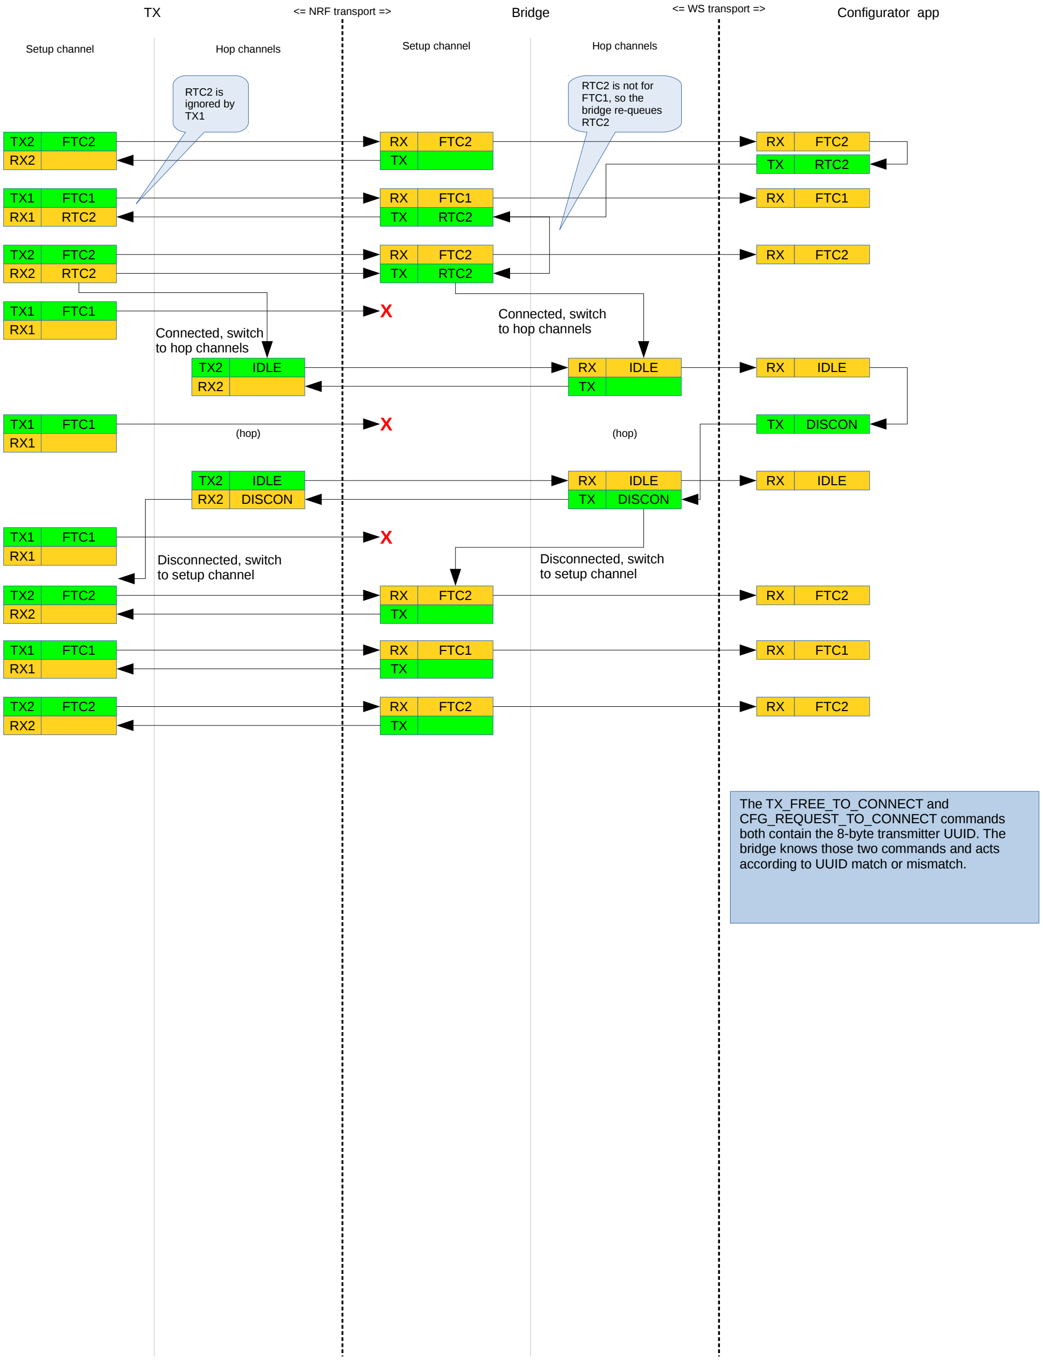
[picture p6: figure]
FTC1; Bridge; Configurator app; Hop channels; Setup channel; <= NRF transport =>; <= WS transport =>; FTC1 RTC2; RTC2; IDLE; DISCON; IDLE DISCON; FTC2; Disconnected, switch to setup channel; (hop); FTC2 RTC2; Connected, switch to hop channels; RTC2 is not for FTC1, so the bridge re-queues RTC2; RTC2 is ignored by TX1; The TX_FREE_TO_CONNECT and CFG_REQUEST_TO_CONNECT commands; according to UUID match or mismatch.

both contain the 8-byte transmitter UUID. The bridge knows those two commands and acts

### Sequence diagram: Transmitter <= UART => Configurator; connection already established

### Errors while reading 5 blocks of data

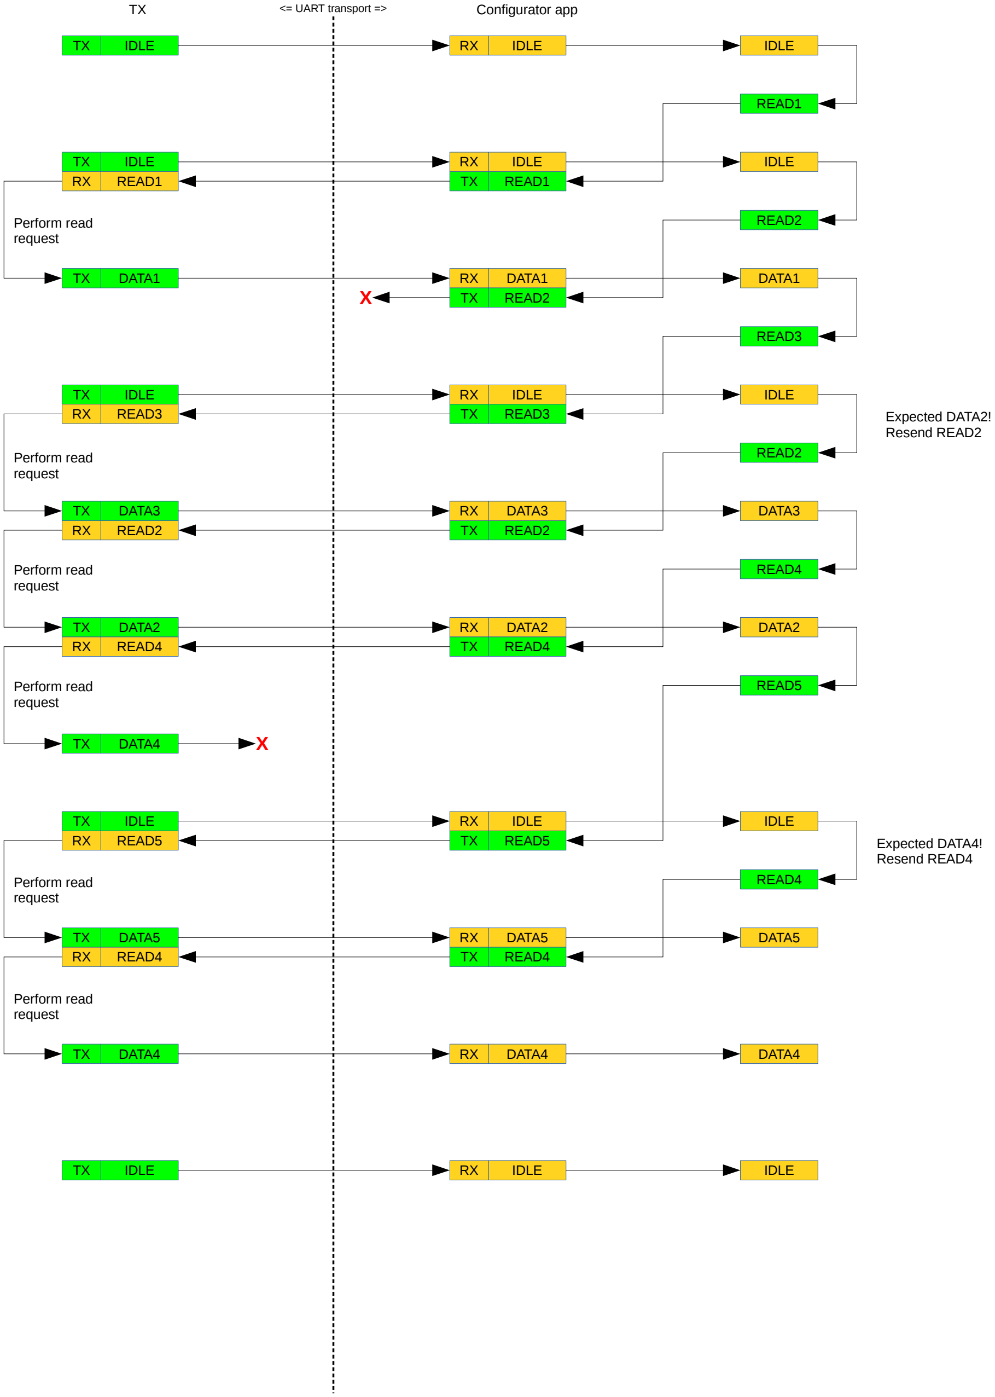
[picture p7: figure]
Configurator app; <= UART transport =>; IDLE; IDLE READ1; READ1; DATA1; Perform read request; READ2; READ3; DATA3; READ2 Perform read request; DATA2; READ4; READ5; Perform read; request; DATA4; DATA5; Expected DATA2! Resend READ2; Expected DATA4! Resend READ4

### Sequence diagram: Transmitter <= NRF => Configurator; connection already established

### Errors while reading 5 blocks of data

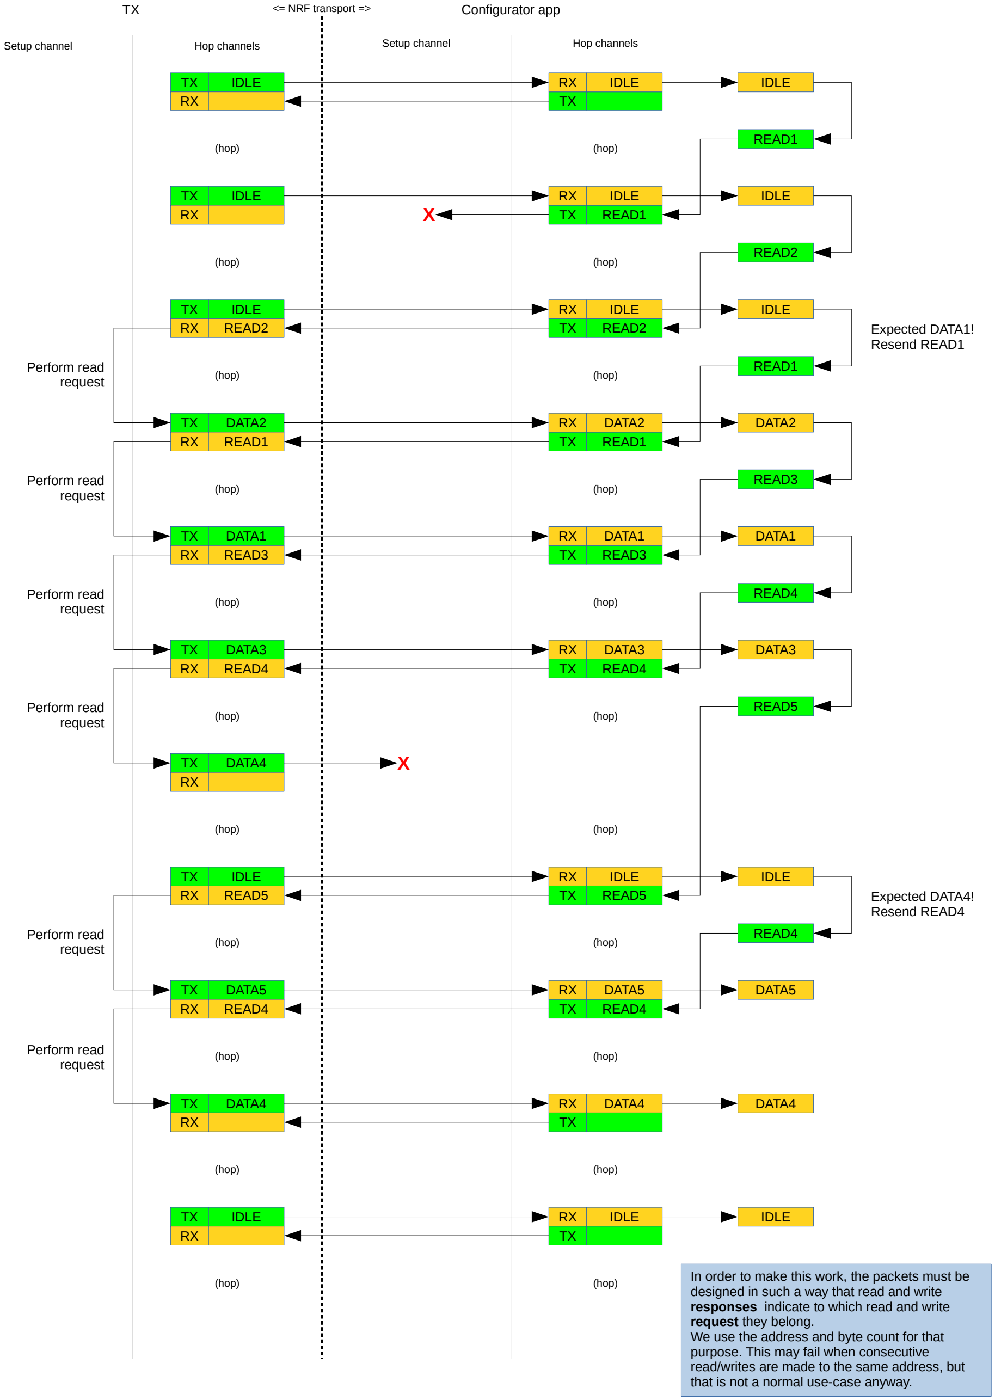
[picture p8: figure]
Configurator app; Hop channels; Setup channel; <= NRF transport =>; IDLE; READ1; IDLE READ2; READ2; DATA2 READ1; DATA2; Expected DATA1! Resend READ1; READ3; DATA1 READ3; DATA1; READ4; DATA3 READ4; DATA3; READ5; DATA4; IDLE READ5; DATA5 READ4; DATA5; Expected DATA4! Resend READ4; (hop); Perform read request; request they belong.; purpose. This may fail when consecutive; that is not a normal use-case anyway.

In order to make this work, the packets must be designed in such a way that read and write responses indicate to which read and write

We use the address and byte count for that

read/writes are made to the same address, but

Sequence diagram: Transmitter <= NRF => bridge <= Websocket => Configurator; connection already established

### Errors on the Websocket transport while reading 5 blocks of data

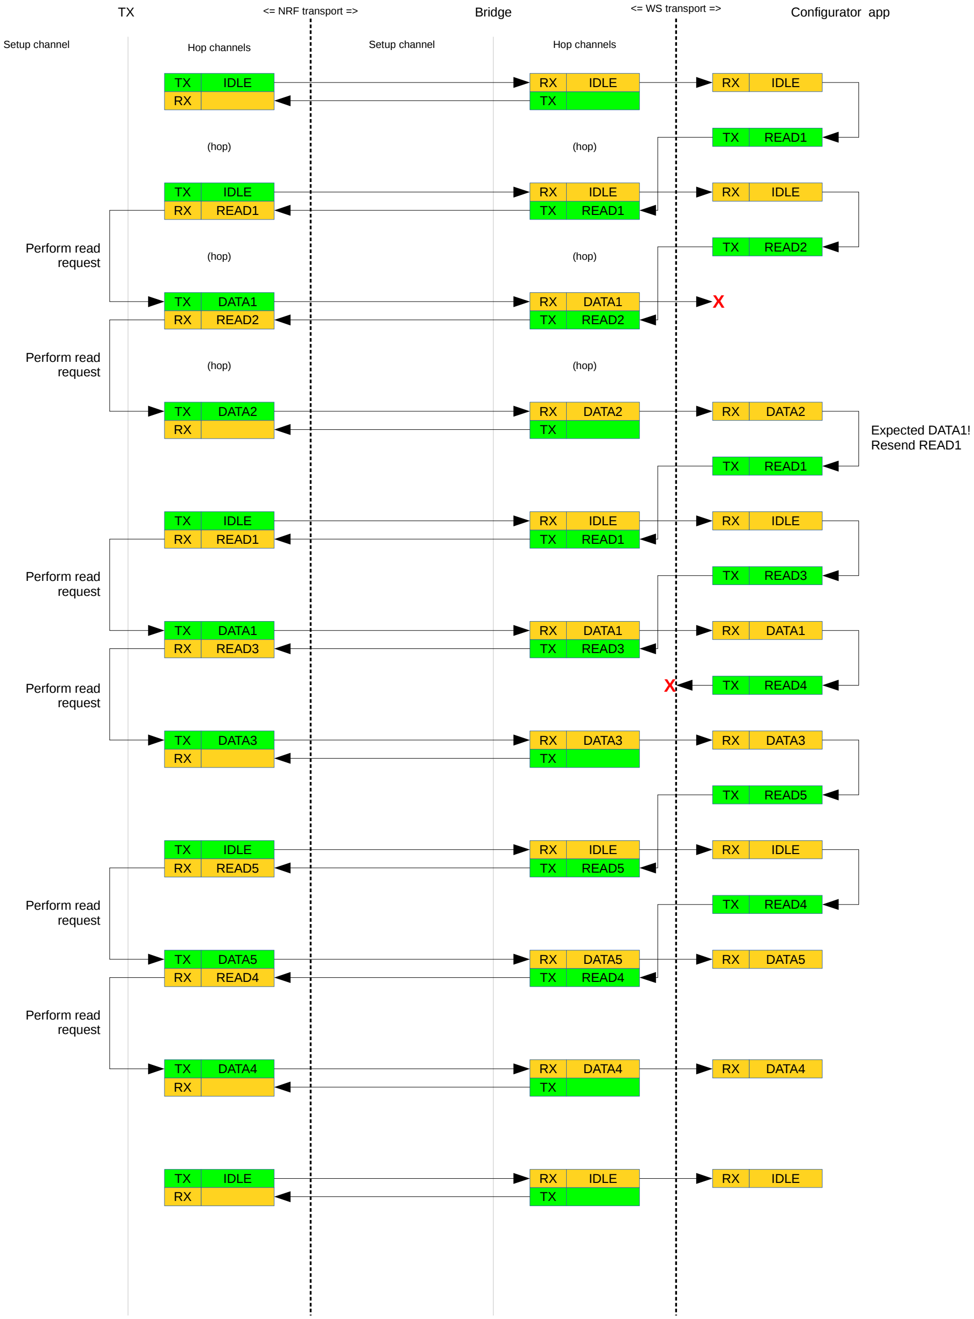
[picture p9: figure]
Bridge; Configurator app; Hop channels; Setup channel; <= NRF transport =>; <= WS transport =>; IDLE; IDLE READ1; READ1; DATA1 READ2; READ2; DATA1; Perform read request; DATA2; (hop); DATA1 READ3; READ3; READ4; DATA3; READ5; IDLE READ5; DATA5 READ4; DATA5; DATA4; Expected DATA1! Resend READ1

Sequence diagram: Transmitter <= NRF => bridge <= Websocket => Configurator; connection already established

### Delay in receiving Websocket packets while reading 5 blocks of data

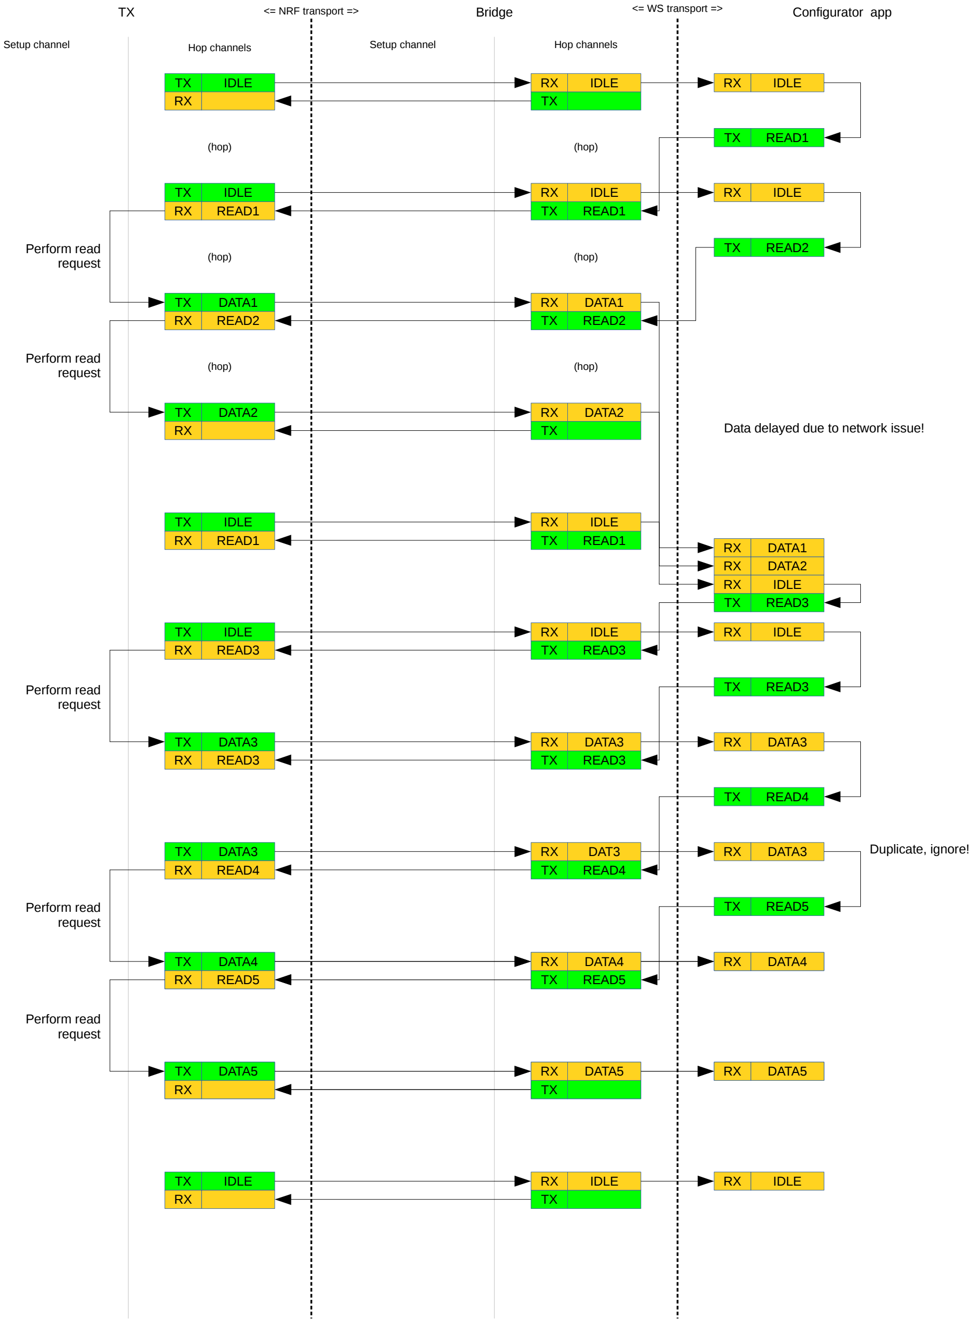
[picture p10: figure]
Bridge; Configurator app; Hop channels; Setup channel; <= NRF transport =>; <= WS transport =>; IDLE; IDLE READ1; READ1; DATA1 READ2; READ2; DATA1; Perform read request; DATA2; (hop); IDLE READ3; READ3; DATA3 READ3; DATA3; DATA3 READ4; READ4; DAT3; DATA4 READ5; READ5; DATA4; Duplicate, ignore!; DATA5; Data delayed due to network issue!

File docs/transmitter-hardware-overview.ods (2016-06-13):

 | HK-310 | X3S | Simulator | Jomac | Futaba FP-2F
T | Trigger | Trigger | Stick | Trigger+ | Trigger
R/ST | Wheel | Wheel | Stick | Wheel | Wheel
A |  |  | Stick
E |  |  | Stick
T-trim | PB 2x | SW 2x | (mechanical) |  | (mechanical)
R-trim/ST-trim | PB 2x | SW 2x | (mechanical) | Pot | (mechanical)
A-trim |  |  | (mechanical)
E-trim |  |  | (mechanical)
R-DR/ST-DR | PB
TH-hold | PB
CH3 | SW
T-DR

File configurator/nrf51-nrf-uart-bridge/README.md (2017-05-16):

This directory contains the firmware that goes into the *configurator* of the [*headless transmitter*](https://github.com/laneboysrc/rc-headless-transmitter).

It runs on the Nordic nRF51822 RF micro-controller.

You need to download the [nRF5 SDK version 11.0](https://www.nordicsemi.com/eng/Products/Bluetooth-low-energy/nRF5-SDK) from Nordic. The SDK must reside in the `firmware/nrf51_sdk/` folder.
*Note:* It is important that you use the exact version mentioned above as newer versions have ab incompatible API.

The firmware is built using a [GNU Make](https://www.gnu.org/software/make/) makefile. The compiler is [ARM GCC toolchain](https://launchpad.net/gcc-arm-embedded), version 5.2.1. [OpenOCD](http://openocd.org/) is used to program the firmware into the micro-controller. You can use the ST-Link v2 to program the nRF51822.

Run

    make

to build the firmware. When done, run

    make program

to flash the firmware into the micro-controller.

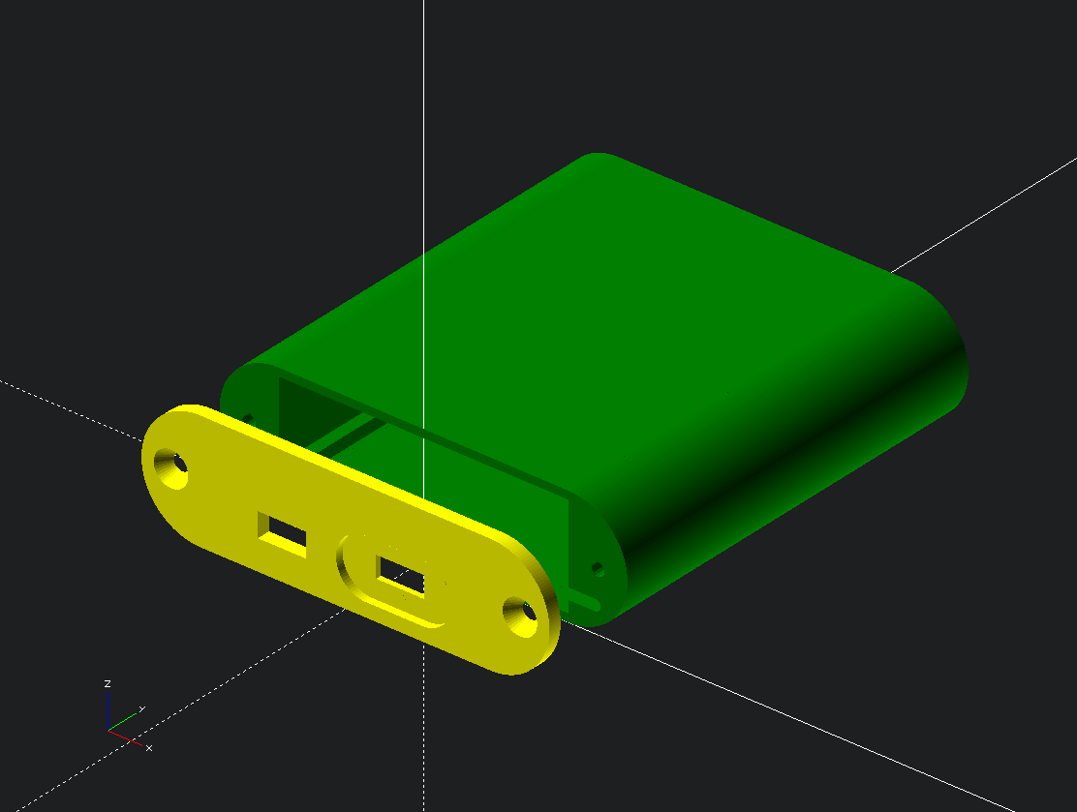
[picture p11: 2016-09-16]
transmitter/mechanics/esp8266-nrf51-configurator-case.png

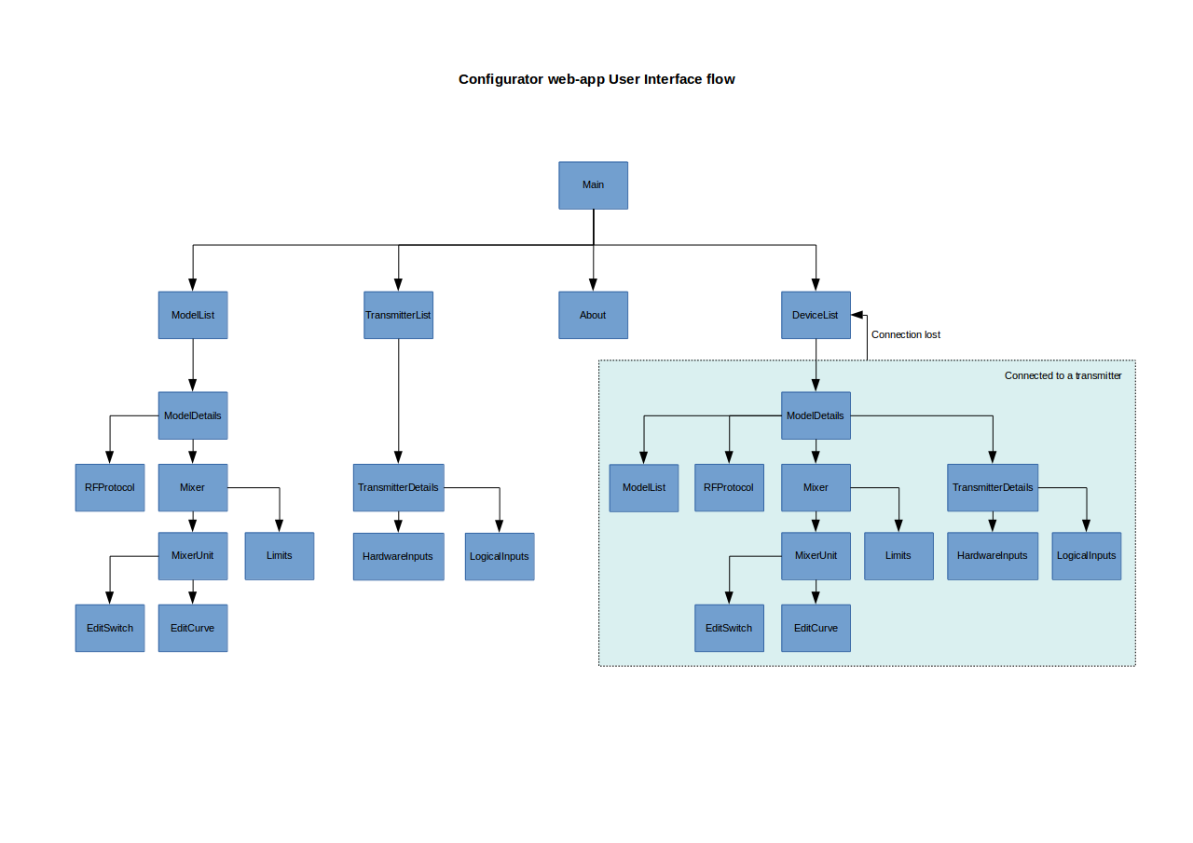
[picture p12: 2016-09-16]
docs/configurator-ui-flow.png

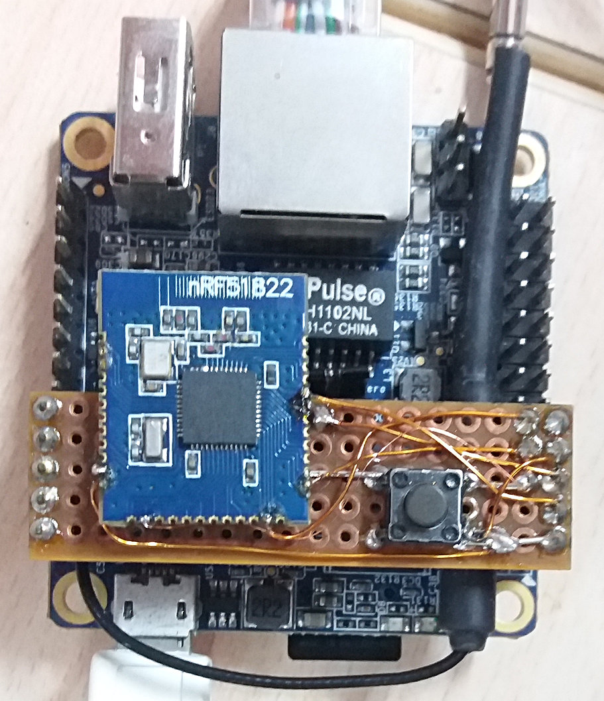
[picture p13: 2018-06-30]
configurator/orangepizero/configurator-pcb1.jpg

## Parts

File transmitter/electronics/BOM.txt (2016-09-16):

BT1        BATTERY   Li-Ion 3.7V 800mAh
C1         1u
C2         100nF
K1         CONN_3    0.1" pin header
K2         CONN_3    0.1" pin header
K3         CONN_3    0.1" pin header
K4         CONN_3    0.1" pin header
K5         CONN_3    0.1" pin header
K6         CONN_3    0.1" pin header
K7         CONN_3    0.1" pin header
K8         CONN_3    0.1" pin header
K9         CONN_3    0.1" pin header
K10        CONN_3    0.1" pin header
K11        CONN_3    0.1" pin header
P1         Charge    0.1" pin header
P2         LED       0.1" pin header
P3         CONN_2    0.1" pin header
P4         CONN_2    0.1" pin header
P5         CONN_4    0.1" pin header
Q1         BC548
R1         1k
R2         22k
R3         33k
R4         1k
SP1        Passive Piezo buzzer         https://www.aliexpress.com/item/Black-Plastic-14-x-7mm-2-Pins-Passive-Piezo-Buzzer-AC1-3V-Piezo-Transducer-with-Flying/32723376720.html
SW1        ON/OFF switch
U1         LIPO_CHARGER_+_PROTECTION    https://www.aliexpress.com/item/New-2Pcs-lot-5V-1A-Micro-USB-18650-Lithium-Battery-Charging-Board-Charger-Module-Protection-Dual/32230225249.html
U2         STM32F103C8T6_DEV_BOARD      https://www.aliexpress.com/item/1pcs-STM32F103C8T6-ARM-STM32-Minimum-System-Development-Board-Module-For-arduino/32478120209.html
U3         NRF24L01P                    https://www.aliexpress.com/item/1100-Meter-Long-Distance-NRF24L01-PA-LNA-NRF24L01P-Wireless-Transceiver-Communication-Module-with-antenna-DC-3/32597272885.html

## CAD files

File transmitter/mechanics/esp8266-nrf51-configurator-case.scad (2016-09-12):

eps = 0.05;
eps2 = 2 * eps;
$fa = 1;
$fs = 0.5;


// PCB dimensions
pcb_board = [64, 74.5, 1.6];
pcb_top = [51, 69, 14.5];
pcb_bottom = [51, 55, 2];
usb = [8, 6, 3];
usb_pos = [pcb_board.x - 19 - usb.x, -1.2, 1];    // Position from left-front of the PCB
switch = [8, 6, 3.5];
switch_pos = [16.2, -2, 0.5];

pcb_offset_z = 2;

// Case
inner = [62, pcb_board.y+0.5, 19];
outer = [65, inner.y+1.5, 22];

// Lid
lid_dim = [outer.x, 2.5, outer.z];


//##############################################################
// Design
//translate([0, 0.25, pcb_board.z+pcb_bottom.z+pcb_offset_z])
//    color("brown")  
//        pcb();

translate([0, 0, 0])
//    color("green", 0.5) 
        case();

translate([0, -2.5, 0])
//    color("yellow", 0.5) 
        lid();


//##############################################################
// For printing
//rotate([-90, 0, 0])
//    translate([0, -outer.y, 0])
//        case();

//rotate([-90, 0, 0])
//    translate([0, -lid_dim.y, 0])
//        lid();


//##############################################################
module cube_x(dim) 
{
    translate([-dim.x/2, 0, 0])
        cube(dim);
}    

//##############################################################
module rounded_box(dim) 
{
    cube_x(dim - [dim.z/2, 0, 0]);
    
    translate([-(dim.x/2-dim.z/4), 0, dim.z/2])
        rotate([-90, 0, 0])
            cylinder(d=dim.z, h=dim.y);

    translate([(dim.x/2-dim.z/4), 0, dim.z/2])
        rotate([-90, 0, 0])
            cylinder(d=dim.z, h=dim.y);
}    

//##############################################################
module pcb() 
{
    cube_x(pcb_top);
    translate([0, 0, -pcb_board.z])
        cube_x(pcb_board);
    translate([0, 0, -pcb_bottom.z-pcb_board.z])
        cube_x(pcb_bottom);
    
    translate(usb_pos - [pcb_board.x/2, 0, 0])
        cube(usb);

    translate(switch_pos - [pcb_board.x/2, 0, 0])
        cube(switch);
}

//##############################################################
module case()
{
    // Outer case with constant wall thickness
    translate([0, 0, outer.z/2]) {
        difference() {
            translate([0, 0, -outer.z/2])
                rounded_box(outer);

            translate([0, -eps, -inner.z/2])
                rounded_box(inner + [0, eps, 0]);
        }
    }
        
    // PCB guides
    intersection() {
        difference() {
            union() {
                translate([-32, 0, 0]) 
                    cube_x([10, inner.y, outer.z]);

                translate([32, 0, 0]) 
                    cube_x([10, inner.y, outer.z]);
            }

            // Slot for the PCB
            translate([0, -eps, 3.75]) 
                rounded_box([pcb_board.x+1, inner.y+eps, pcb_board.z+0.5]);

            // Screw holes for M3x12
            translate([-outer.x/2, -eps, outer.z/2])
                rotate([-90, 0, 0])
                    cylinder(d=2.5, h=15);
            
            translate([outer.x/2, -eps, outer.z/2])
                rotate([-90, 0, 0])
                    cylinder(d=2.5, h=15);
        }
        rounded_box(outer);
    }
}

//##############################################################
module lid()
{
    difference() {
        rounded_box(lid_dim);

        translate([lid_dim.x/2, -eps, lid_dim.z/2])
            rotate([-90, 0, 0])
                cylinder(d1=6.5, d2=3, h=lid_dim.y+eps2);

        translate([-lid_dim.x/2, -eps, lid_dim.z/2])
            rotate([-90, 0, 0])
                cylinder(d1=6.5, d2=3, h=lid_dim.y+eps2);

        translate([-pcb_board.x/2, 0, pcb_board.z+pcb_bottom.z+pcb_offset_z]) {
            translate(usb_pos - [0.5, 0, 0.5])
                cube(usb + [1, 1, 1]);

            translate([usb_pos.x+4, -eps, usb_pos.z-4])
                rounded_box([usb.x+8, 1.5, usb.z+8]);
            
            translate(switch_pos - [0.5, 0, 0.5])
                cube(switch + [1, 1, 1]);
        }
    
     }
}

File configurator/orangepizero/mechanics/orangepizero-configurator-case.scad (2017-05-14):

// Case for the Orange Pi Zero based configurator
//
// Note that 0/0 (x/y) is the center of the lower left mounting
// hole of the PCB, 


$fn = 50;
eps = 0.05;
eps2 = 2 * eps;
tol = 0.3;
tol2 = 2 * tol;

bottom_t = 0.9;
top_t = 0.9;
wall_t = 1.5;

pcb_dim = [48, 46, 1.6];
pcb_r = 3;

gap_around_pcb = 4;
solder_clearance = 3;

// Dimension of the RJ45 connector part that is sticking out of the PCB
rj45_dim = [16, 16.4, 13.2];
rj45_pos = [-3, 12, bottom_t+solder_clearance+pcb_dim.z];
rj45_top = rj45_pos.z + rj45_dim.z;

micro_usb_connector_dim = [10, 12, 10];
micro_usb_dim = [4, 8, 3];
micro_usb_pos = [39, 3, rj45_pos.z];
micro_usb_top = bottom_t+solder_clearance+4.5;

button_pos = [34, 30, 0];


// Calculated values

gap2 = 2 * gap_around_pcb;
pcb_z = bottom_t + solder_clearance;

wall_t2 = 2 * wall_t;
wall_h = pcb_z + 20;

inside_dim = [pcb_dim.x+gap2, pcb_dim.y+gap2, wall_h-bottom_t+eps];
inside_r = pcb_r + gap_around_pcb;

outside_dim = [inside_dim.x+wall_t2, inside_dim.y+wall_t2, wall_h];
outside_r = inside_r + wall_t;

lid_dim = [outside_dim.x, outside_dim.y, top_t];
lid_r = outside_r;




//==============================================================
case();
//%translate([0, 0, pcb_z]) pcb();

//rotate([180, 0, 0])
lid();

//==============================================================
module case() {
    difference() {
        union() {
            difference() {
                // Outside shape. 
                translate([0, 0, 0])
                    rounded_cube(outside_dim, outside_r);

                // Inside shape
                translate([0, 0, bottom_t])
                    rounded_cube(inside_dim, inside_r);
            }

            // PCB mounts
            translate([0, 0, bottom_t])
                pcb_mounts();
            
            // Guide for RJ45
            translate([-pcb_r-gap_around_pcb-eps, rj45_pos.y-1-tol/2, 0])
                cube([gap_around_pcb-0.5, rj45_dim.y+tol+2, rj45_top]);

            // Guide for Micro-USB plug
            translate([pcb_dim.x-gap_around_pcb+2, 7-2-micro_usb_connector_dim.y/2, 0])
                cube(micro_usb_connector_dim + [-6, 4, 3]);
        }

        // RJ45 connector cut-out
        translate(rj45_pos - [7, tol/2, 0])
            cube(rj45_dim + [5, tol, tol]);
        
        // LED cut-out
        led_apature_z = bottom_t + solder_clearance + pcb_dim.z;
        translate([pcb_dim.x-pcb_r+gap_around_pcb, 30, led_apature_z]) 
            led_apature_right(h=wall_t);
        
        // Micro-USB connector cut-out
        usb_z = bottom_t + solder_clearance + 2 - micro_usb_connector_dim.z / 2;
        translate([pcb_dim.x-pcb_r, 7-micro_usb_connector_dim.y/2, usb_z]) 
            cube(micro_usb_connector_dim);
   }
}

//==============================================================
module lid() {
    w = 2 * (inside_r - tol);
    z = rj45_top + tol;
    h = wall_h - z;
    
    wall_dim = [inside_dim.x-tol, inside_dim.y-tol, h];
    wall_r = inside_r-tol;
    
    difference() {
        union() {
            // Top-most cover
            translate([0, 0, wall_h])
                rounded_cube(lid_dim, lid_r);
            
            // Rim that closes the lid
            translate([0, 0, z]) {
                difference() {
                    rounded_cube(wall_dim, wall_r);
                    translate([0, 0, -eps])
                        rounded_cube(wall_dim-[wall_t2, wall_t2, -eps2], wall_r-wall_t);
                }
            }
            
            // Hold-down for the RJ45
            translate([-inside_r+tol, rj45_pos.y, z])
                cube([rj45_dim.x, rj45_dim.y, h]);

            // Hold-down for the micro-USB connector
            translate([micro_usb_pos.x, micro_usb_pos.y, micro_usb_top])
                cube([micro_usb_dim.x, micro_usb_dim.y, wall_h-micro_usb_top]);
        }
        
        // Button activator cut-out
        translate(button_pos + [0, 0, wall_t2]) {
            difference() {
                d = 10;
                cylinder(d=d, h=wall_h);
                translate([0, 0, -eps]) cylinder(d=d-3, h=wall_h+eps2);
                translate([0, -d/6, -eps]) cube([d, d/3, wall_h+eps2]);
            }
        }
    }
}

//==============================================================
module pcb() {
    difference() {
        color("DarkGreen") rounded_cube(pcb_dim, pcb_r);
        pcb_mounts();
    }
}

//==============================================================
module pcb_mounts(d=2, h=3, d_wide=2.8, eps=eps) {
    d1 = d_wide ? d_wide : d; 
    d_socket = 5;
    h_socket = solder_clearance - tol;
    pos = [pcb_dim.x-2*pcb_r, pcb_dim.y-2*pcb_r];
    
    for (p = [[0, 0, 0], [pos.x, 0, 0], [0, pos.y, 0], [pos.x, pos.y, 0]]) {
        translate(p) {
            cylinder(d=d_socket, h=h_socket);
            translate([0, 0, h_socket]) cylinder(d1=d1, d2=d, h=h);
        }
    }
    
}

//==============================================================
module rounded_cube(dim, r=3) {
    d = 2 * r;

    minkowski() {
        cube(dim - [d, d, eps], false);
        cylinder(r=r, h=eps);
    }
}

//==============================================================
module led_apature_top(h=3) {
    w = 2.5; 
    l = 5;
    hull() {
        translate([-w/2, (l-w)/2, -eps]) 
            cylinder(d=w, h=h+eps2);
        translate([-w/2, -(l-w)/2, -eps]) 
            cylinder(d=w, h=h+eps2);
    }
}

//==============================================================
module led_apature_right(h=3) {
    rotate([0, 90, 0])
        led_apature_top(h=h);
}

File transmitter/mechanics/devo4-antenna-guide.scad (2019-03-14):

eps = 0.05;
eps2 = 2 * eps;
epsz = [0, 0, -eps];

$fn = 50;

d_ring = 16;
d_outer = 20;
h = 9;
h_rim = 2;
z_rim = 2;

d_screw = 6;
screw_y = 6;

d_antenna = 10;
d_antenna_recess = 10;
h_antenna = 3;


difference() {
    union() {
        cylinder(d=d_ring, h=h);
        translate([0, 0, z_rim]) cylinder(d1=d_ring, d2=d_outer, h=1.5);
        translate([0, 0, z_rim+1.5]) cylinder(d=d_outer, h=h_rim-1.5);
    }
    
    translate(epsz) cylinder(d=d_antenna, h=h+eps2);
    translate(epsz) cylinder(d=d_antenna_recess, h=h-h_antenna+eps);

    translate([0, 0, screw_y-(d_screw/2)]) rotate([90, 0, 0]) cylinder(d=d_screw, h=d_outer+eps2, center=true);
    cube([d_screw, d_outer+eps, d_screw+(screw_y-(d_screw/2))/2], center=true);
    
    translate([d_ring/2, -d_outer/2, -eps]) cube([d_outer, d_outer, h+eps2]);
    mirror([1, 0, 0] )translate([d_ring/2, -d_outer/2, -eps]) cube([d_outer, d_outer, h+eps2]);
    
}

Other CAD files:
transmitter/mechanics/devo4-switch-mount.scad
transmitter/mechanics/graupner-e8-antenna-guide.scad
transmitter/mechanics/graupner-e8-push-button-mount.scad
transmitter/mechanics/graupner-e8-switch-plate.scad
transmitter/mechanics/graupner-e8-usb-mount.scad

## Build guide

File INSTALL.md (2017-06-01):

# You can do it!

Don't be discouraged: One can learn *anything* with the help of the Internet today. It is only up to *you* to invest the time.

**A day where you learn something new is a good day.**

---

# How to get up and running

This project requires **basic** skills in electronics, soldering and Linux (Raspberry Pi level, e.g. using ssh, networking, running commands, editing files). While the electronics are based on off-the-shelf modules, everything needs to be wired correctly on a prototyping board and installed in the transmitter.

The *headless transmitter* comprises of an inexpensive ["Blue pill" board](https://www.aliexpress.com/item/1pcs-STM32F103C8T6-ARM-STM32-Minimum-System-Development-Board-Module-For-arduino/32478120209.html) with an STM32F103 micro-controller. It drives a nRF24L01+ module with integrated power amplifier. A single cell Li-Ion battery, protected and charged by another cheap module, is used as power source. There is no need to make a PCB, everything fits easily on a prototyping board.
Please refer to [transmitter/electronics/BOM.txt](transmitter/electronics/BOM.txt) for a full list of components required.

The *configurator* is built with an [Orange Pi Zero](https://www.aliexpress.com/store/product/New-Orange-Pi-Zero-H2-Quad-Core-Open-source-development-board-beyond-Raspberry-Pi/1553371_32760774493.html) and a CORE51822B module. The 256 MByte version of the Orange Pi Zero is enough for our simple application. It is powered by a suitable power bank or other 5V supply.
Please refer to [configurator/orangepizero/HARDWARE.md](configurator/orangepizero/HARDWARE.md) for a full list of components required.

Follow the instructions in [configurator/orangepizero/INSTALL.md](configurator/orangepizero/INSTALL.md) to install and configure the Armbian Linux distribution and required software on the Orange Pi Zero.

The firmware for the micro-controllers comes pre-compiled in the [bin/](bin/) folder of the project, no need to install development tools and compile it yourself. You can use the Orange Pi Zero to flash it. Refer to [configurator/orangepizero/openocd/README.md](configurator/orangepizero/openocd/README.md) for instructions.

# First time use

Power up the *headless transmitter*. You should hear a short beep and the LED should be on. The transmitter is now operational, with a simple default configuration.

Turn on the *configurator* and wait until it has booted (green LED turns solid).

On your PC or Smartphone, open [https://laneboysrc.github.io/rc-headless-transmitter](https://laneboysrc.github.io/rc-headless-transmitter) in the web browser.

Now connect Wi-Fi to the SSID of the *configurator*, which is "LANE Boys RC". Use the passphrase you have configured when building the *configurator* (default is "12345678", but you hopefully changed that while building your own *configurator* ...).

After pressing the `Connect` button on the web-app, the list of transmitters should show `Unconfigured Tx`. Click on the `Edit` icon next to the name. The transmitter should beep and after a few seconds the web-app will show the settings of the transmitter. You can now proceed with configuring it.

After connecting to a transmitter for the first time, you should give it a unique name and assign a new RF protocol address and hop sequence.

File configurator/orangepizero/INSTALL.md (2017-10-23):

# Install Armbian

Download Armbian for the Orange Pi Zero from [https://www.armbian.com/orange-pi-zero/](https://www.armbian.com/orange-pi-zero/). Use the stable release `Armbian_5.25_Orangepizero_Ubuntu_xenial_default_3.4.113`. [Etcher](https://etcher.io) is a great too to flash the image onto a Micro-SD card.

# Basic configuration

Connect the Orange Pi Zero via an Ethernet cable (RJ45) to your router and power it up. After about 45 seconds the OS has booted (green LED becomes solid).

Connect to the Orange Pi Zero via ssh:

    ssh root@orangepizero

If your router does not resolve local hostnames then check its IP client table to find the IP address of the Orange Pi Zero and use that (e.g. `ssh root@192.168.1.103`).

The default password is `1234`. Follow the on-screen instructions to change the password and create a new user. After the installation returns to the command prompt, enter `reboot` to restart.

Login with your newly created username and password:

    ssh your-username@orangepizero
(or)

    ssh your-username@192.168.x.x

Set time zone with

    sudo dpkg-reconfigure tzdata

To allow running commands as superuser without password, run

    sudo visudo -f /etc/sudoers.d/your-username
and enter

    your-username ALL=(ALL) NOPASSWD:ALL

Update the operating system and reboot:

    sudo apt-get update
    sudo apt-get -y dist-upgrade
    sudo reboot

# Download the rc-headless-transmitter files

    git clone https://github.com/laneboysrc/rc-headless-transmitter.git

Note that the directory `~/rc-headless-transmitter/configurator/orangepizero/etc/` contains samples of most of the configuration files that need to be created. Feel free to copy them instead of editing them by hand.

For example, if the instructions say "`sudo nano /etc/apt/apt.conf.d/90no-auto-upgrades` and add `<content>`", then you can use the skeleton file instead:

    sudo cp ~/rc-headless-transmitter/configurator/orangepizero/etc/apt/apt.conf.d/90no-auto-upgrades /etc/apt/apt.conf.d/90no-auto-upgrades

# Disable automatic updates

The configurator is running without Internet connection most of the time. We can save a bit of power and startup time if we disable automatic updates, which will fail anyway due to lack of Internet access.

Create file /etc/apt/apt.conf.d/90no-auto-upgrades

    sudo nano /etc/apt/apt.conf.d/90no-auto-upgrades
and add

    APT::Periodic::Update-Package-Lists "0";
    APT::Periodic::Unattended-Upgrade "0";

# Enable GPIO access without root
Create file /etc/udev/rules.d/99-gpio.rules

    sudo nano /etc/udev/rules.d/99-gpio.rules
and add

    SUBSYSTEM=="gpio", ACTION=="add", PROGRAM="/bin/sh -c 'chown -R root:gpio /sys/class/gpio && chmod -R g+w /sys/class/gpio'"
    SUBSYSTEM=="gpio", ACTION=="add", PROGRAM="/bin/sh -c 'chown -R root:gpio /sys/devices/virtual/gpio && chmod -R g+w /sys/devices/virtual/gpio'"
    SUBSYSTEM=="gpio", ACTION=="add", PROGRAM="/bin/sh -c 'chown -R root:gpio /sys/devices/platform/sunxi-pinctrl/gpio && chmod -R g+w /sys/devices/platform/sunxi-pinctrl/gpio'"

Then run

    sudo groupadd --system gpio
    sudo usermod -a -G gpio your-username

# Network configuration
Create file: /etc/network/interfaces.hostapd-configurator

    sudo nano /etc/network/interfaces.hostapd-configurator
and add

    allow-hotplug wlan0
    iface wlan0 inet static
        address 192.168.4.1
        netmask 255.255.255.0

This configures the wireless access point we are setting up to use a static IP address of `192.168.4.1`. **Do not change this address, the configurator web-app uses this exact address to find your bridge!**

Create a symlink to the new file:

    cd /etc/network
    sudo rm interfaces
    sudo ln -s interfaces.hostapd-configurator interfaces

Change the hostname:

    sudo sh -c 'echo "configurator" > /etc/hostname'

Edit /etc/hosts:

    sudo nano /etc/hosts

  * Remove all `orangepizero` references
  * Add line `192.168.4.1 configurator`

**IMPORTANT: after the next reboot you have to use the new hostname `configurator` to login, rather than 'orangepizero'. E.g. `ssh your-username@configurator`**

# hostapd configuration
`hostapd` turns the Orange Pi Zero into wireless access point.

Create file /etc/hostapd.configurator.conf

    sudo nano /etc/hostapd.configurator.conf
and add

    wpa_passphrase=12345678
    ssid=LANE Boys RC
    channel=11
    interface=wlan0
    driver=nl80211
    utf8_ssid=1
    wpa=2
    wpa_key_mgmt=WPA-PSK
    wpa_pairwise=CCMP
    auth_algs=1
    hw_mode=g
    ieee80211n=1
    max_num_sta=5
    wmm_enabled=1
    macaddr_acl=0
Consider changing the Wi-Fi password in line 1!

Edit the existing file /etc/default/hostapd

    sudo nano /etc/default/hostapd
and add

    DAEMON_CONF="/etc/hostapd.configurator.conf"

# dnsmasq
`dnsmasq` provides a DHCP server, i.e. it issues IP addresses to the clients that connect to the Orange Pi Zero Wi-Fi.

Install the software:

    sudo apt-get install dnsmasq

Edit file /etc/dnsmasq.conf:

    sudo nano /etc/dnsmasq.conf
and remove the comment (`#` character) from the line

    #conf-dir=/etc/dnsmasq.d,.bak

Create /etc/dnsmasq.d/configurator

    sudo nano /etc/dnsmasq.d/configurator
and add

    interface=wlan0      # Use interface wlan0
    listen-address=192.168.4.1 # Explicitly specify the address to listen on
    bind-interfaces      # Bind to the interface to make sure we aren't sending things elsewhere
    server=8.8.8.8       # Forward DNS requests to Google DNS
    domain-needed        # Don't forward short names
    bogus-priv           # Never forward addresses in the non-routed address spaces.
    dhcp-range=192.168.4.50,192.168.4.150,12h # Assign IP addresses between 192.168.4.50 and 192.168.4.150 with a 12 hour lease time

# IP forwarding
IP forwarding enables the Orange Pi Zero to act as a wireless router.

Edit /etc/sysctl.conf

    sudo nano /etc/sysctl.conf
and remove the comment (`#` character) from lines

    #net.ipv4.ip_forward=1
    #net.ipv6.conf.all.forwarding=1

Enable NAT using iptables:

    sudo apt-get install iptables
    sudo iptables -t nat -A POSTROUTING -o eth0 -j MASQUERADE
    sudo iptables -A FORWARD -i wlan0 -j ACCEPT
    sudo apt-get install iptables-persistent

*Tip: if you modify the IP table rules in the future, use `sudo dpkg-reconfigure iptables-persistent` to save the changes.*

# Install nginx
The NGINX web server is used to provide secure WebSocket services to the configurator.

    sudo apt-get install -y nginx-light openssl ssl-cert
    sudo make-ssl-cert generate-default-snakeoil --force-overwrite
    sudo log2ram write
log2ram is important as otherwise the nginx directory in `/var/log/` is not retained and nginx fails on the next reboot!

Create file /etc/nginx/sites-available/configurator

    sudo nano /etc/nginx/sites-available/configurator
and add

    map $http_upgrade $connection_upgrade {
        default upgrade;
        '' close;
    }

    server {
        listen 80 default_server;
        server_name _;
        return 301 https://$host$request_uri;
    }

    server {
        listen 443 ssl;
        server_name configurator;
        ssl on;
        include snippets/snakeoil.conf;

        root /var/www/html;
        index index.configurator.html index.html index.htm index.nginx-debian.html;
        location / {
            try_files $uri $uri/ =404;
        }

        location /ws {
            proxy_pass http://localhost:9706;
            proxy_http_version 1.1;
            proxy_set_header Upgrade $http_upgrade;
            proxy_set_header Connection $connection_upgrade;
        }
    }

    server {
        listen 9707 ssl;
        ssl on;
        include snippets/snakeoil.conf;

        location / {
            proxy_pass http://localhost:9706;
            proxy_http_version 1.1;
            proxy_set_header Upgrade $http_upgrade;
            proxy_set_header Connection $connection_upgrade;
        }
    }

Use the new configuration by running

    sudo rm /etc/nginx/sites-enabled/default
    sudo ln -s /etc/nginx/sites-available/configurator /etc/nginx/sites-enabled/configurator

Copy the file stored in `configuator/orangepizero/var/www/html/index.configurator.html` fo the project to `/var/www/html/index.configurator.html`

    sudo cp ~/rc-headless-transmitter/configurator/orangepizero/var/www/html/index.configurator.html /var/www/html/index.configurator.html
This file gets shown when you browse to `https://192.168.4.1/` and allows users to allow a security exception of the self-signed certificate used in the configurator.

# Install node-js
The configurator bridge software is written in JavaScript and requires NodeJS as runtime.

To install, run

    curl -sL https://deb.nodesource.com/setup_6.x | sudo -E bash -
    sudo apt-get install nodejs

# Run the UART-websocket bridge
We are using `pm2` to start our application during the boot process.

Install and run

    sudo npm install -g pm2
    pm2 startup
Execute the command as instructed by `pm2 startup`.

Install the dependencies for the bridge and start it:

    cd ~/rc-headless-transmitter/configurator/nodejs-uart-websocket-bridge/
    npm install
    pm2 start --name="bridge" npm -- start /dev/ttyS1
    pm2 save

# Final setup
Reboot the Orange Pi Zero:

    sudo reboot

Verify that the bridge software is running:

    pm2 ls

Connect the Wi-Fi of your computer or Smartphone to the SSID `LANE Boys RC`. Use the password you configured in `/etc/hostapd.configurator.conf` earlier.

Open Chrome or Firefox and browse to [https://192.168.4.1](https://192.168.4.1). The browser should show a security error message since we are using a self-signed cerficiate. Add a permanent exception to allow this certificate. You should now see a web page with a success message, showing the LANE Boys RC logo.

Change the Wi-Fi connection back to your normal Internet connection and browse to [https://laneboysrc.github.io/rc-headless-transmitter](https://laneboysrc.github.io/rc-headless-transmitter). Once loaded, you can use the "Install to home screen" feature in your browsers menu to create a desktop icon on your Smartphone for easy future access.

With the web-app still open in the web browser, connect Wi-Fi to the *configurator* bridge (SSID `LANE Boys RC`), then press the `Connect` button. You should briefly see `Connecting to the bridge ...` followed by `Scanning for transmitters ...`. Turn on your *headless transmitter* and it should appear as `Unconfigured Tx` in the list.

Congratulations, you've made it! **Have fun with RC!**

---

## Optional software and configuration

Above instructions are sufficient for a fully functional configurator bridge. Here are a few more optional items you can do to improve the installation.

### Power button
In order to prevent corruption of the micro-SD card when cutting the power, it is advise to propery shut down the Orange Pi Zero before removing the supply.

To be able to do so, the project comes with a small script that monitors a simple tact switch on GPIO6 of the Orange Pi Zero. Holding the button for more than 2 seconds invokes a clean shutdown of the Orange Pi Zero.

Please refer to [HARDWARE.md](HARDWARE.md) how to connect the push-button.

**IMPORTANT:** do not install the software below unless you have connected a pull-up resistor to GPIO6, as it can shut down your Orange Pi Zero if the IO port is left floating!

    cd ~/rc-headless-transmitter/configurator/orangepizero
    pm2 start --name="power-button" shutdown-on-button-press.py
    pm2 save

### Freeze the fs
To protect the SD card from accidental writes it is possible to mount the file system read-only. All temporary files will be written to a RAM disk and discarded when the Orange Pi Zero is powered off.

    sudo apt-get install overlayroot
    sudo sh -c "echo 'overlayroot="tmpfs"' >> /etc/overlayroot.local.conf"
    sudo reboot

In order to make changes to the file system again, for example to update the Armbian operating system or install a new version of the RC Headless Transmitter software, run:

    sudo overlayroot-chroot nano /etc/overlayroot.local.conf

and comment out the `overlayroot="tmpfs"` line; then reboot.
After performing your changes you can remove the comment from `/etc/overlayroot.local.conf` and reboot to re-instate the read-only file system.

### openocd to flash the nRF51822 and STM32F103C8T6
If you don't have a SWD programmer to flash the nRF51822 or the STM32F103, you can use the Orange Pi Zero in conjuction with the `openocd`.

Refer to [openocd/README.md](openocd/README.md) on how to install, configure and use `openocd`.

### Conserve power
For our usage we don't need the graphics card and USB capabilities of the Orange Pi Zero, so we can disable them to save power:

    sudo h3consumption -g off -u off

### Configure the red LED to show disk access

Create file /etc/init.d/red-led

    sudo nano /etc/init.d/red-led

and add

    #!/bin/sh
    if [ true != "$INIT_D_SCRIPT_SOURCED" ] ; then
        set "$0" "$@"; INIT_D_SCRIPT_SOURCED=true . /lib/init/init-d-script
    fi
    ### BEGIN INIT INFO
    # Provides:          red-led
    # Required-Start:    $udev
    # Required-Stop:
    # Default-Start:     2 3 4 5
    # Default-Stop:
    # Short-Description: Configure the red LED to show SD card access
    ### END INIT INFO

    DESC="Red LED shows disk access"
    DAEMON=/bin/sh

    do_start() {
        /bin/sh -c 'echo mmc0 > /sys/class/leds/red_led/trigger'
    }

Create the required symlinks by running

    sudo chmod +x /etc/init.d/red-led
    sudo update-rc.d red-led defaults

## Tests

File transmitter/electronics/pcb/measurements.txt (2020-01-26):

Graupner Varioprop E8

                  s2

   s1

                  s3

x: 80+
y: 48
s2/s3 to edge: 24
s2.y - s3.y: 39
s1.x - s2/s3.x: 60

Esky

s1      T            s2                 s3

                     s4                 s5

x: 104+
y: 41
s1.y/s2.y/s3.y to edge: 3
s3.x/s5.x to edge: 9
s1.x - s2.x: 40
s2.x - s3.x: 55
s2.y - s4.y: 28
t.x= 12
t.y = 3
t.y2 = 12
t.x(right) - s2.x = 18

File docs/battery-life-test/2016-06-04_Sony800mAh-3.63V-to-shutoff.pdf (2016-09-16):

0.51

1.52

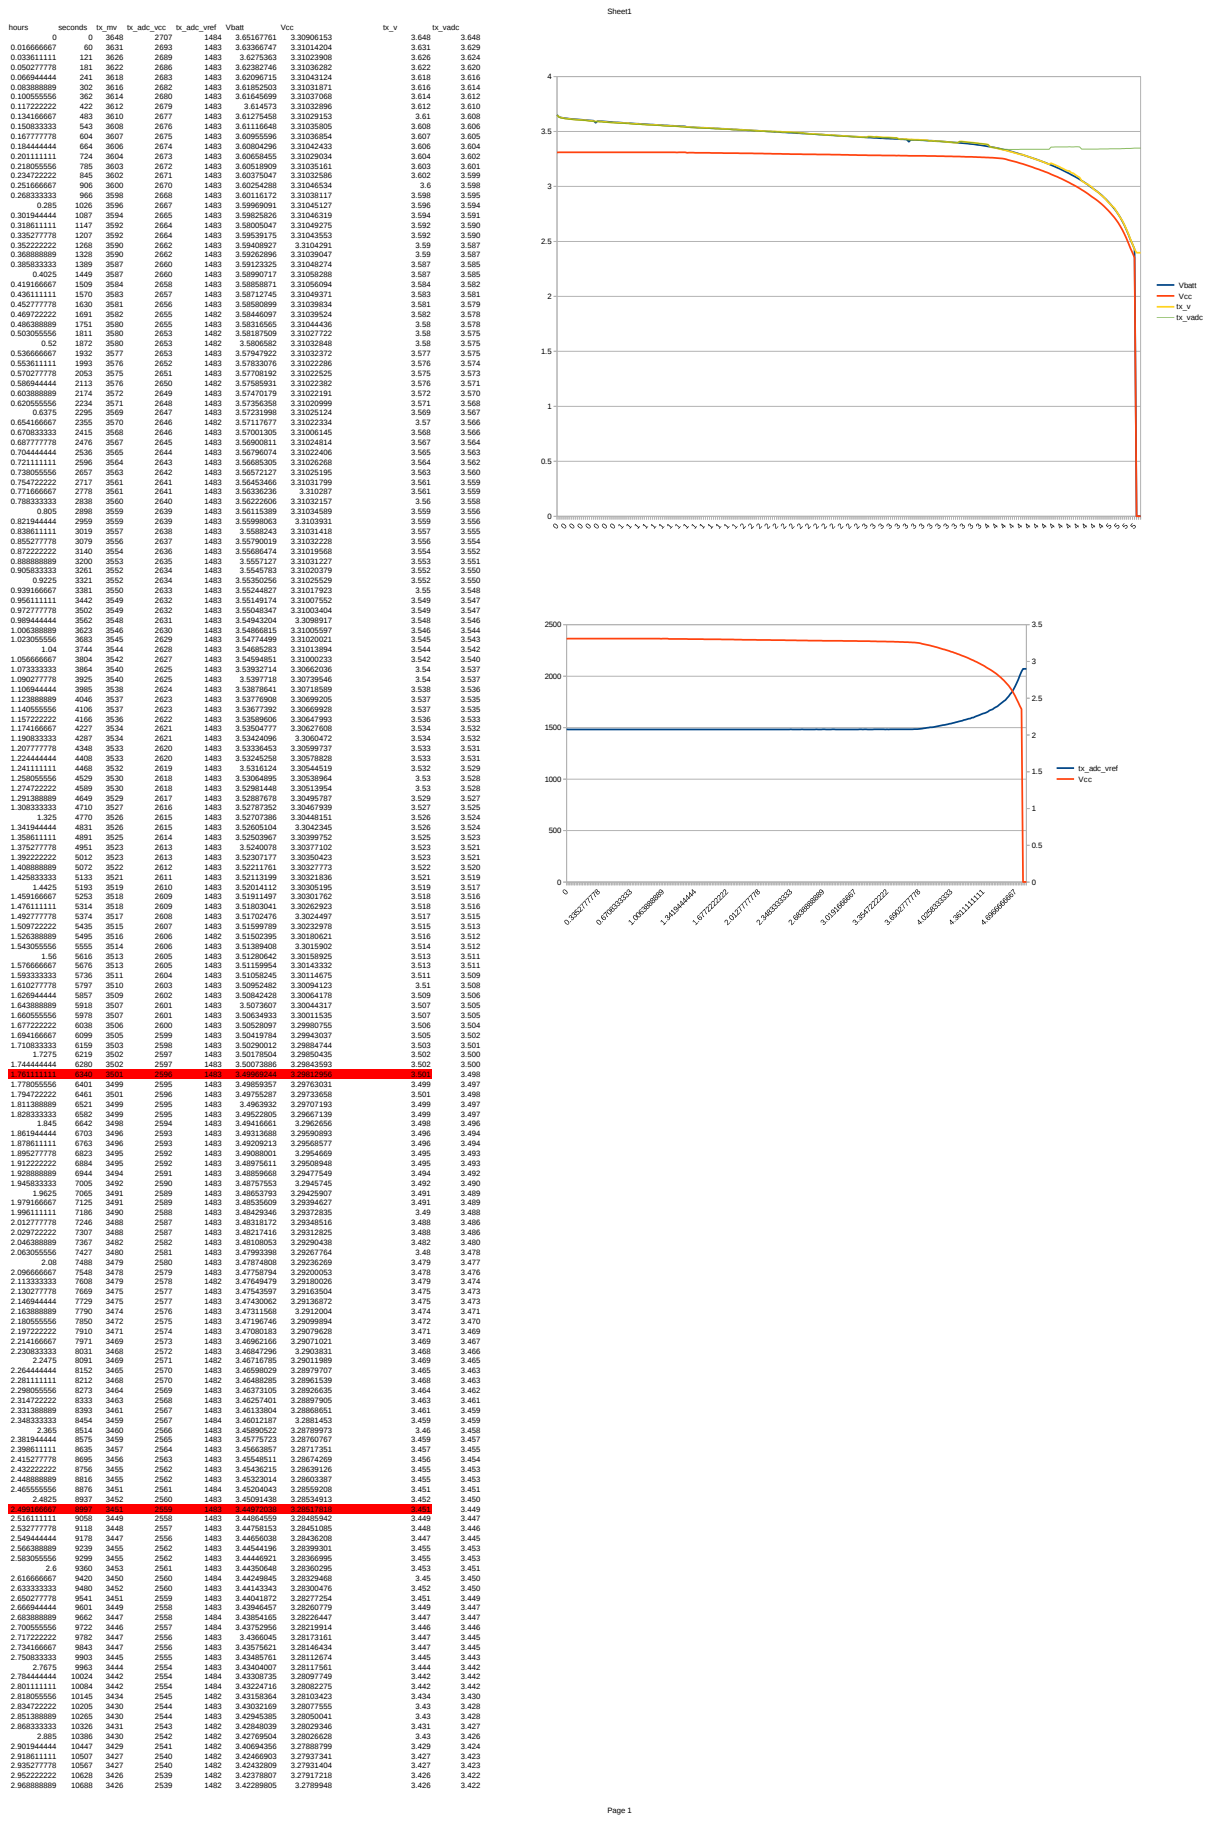
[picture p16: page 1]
Sheet1; Page; hours; seconds tx_mv tx_adc_vcc tx_adc_vref Vbatt; Vcc; tx_vadc 0; Vbatt Vcc tx_v tx_vadc; tx_adc_vref Vcc

Sheet1

2.985555556 | 10748 | 3425 | 2538 | 1482 | 3.42180324 | 3.27871871 | 3.425 | 3.420
3.0025 | 10809 | 3423 | 2537 | 1482 | 3.42113352 | 3.27876639 | 3.423 | 3.419
3.019166667 | 10869 | 3422 | 2536 | 1482 | 3.41997886 | 3.27838039 | 3.422 | 3.418
3.036111111 | 10930 | 3422 | 2536 | 1482 | 3.4187746 | 3.27792239 | 3.422 | 3.418
3.052777778 | 10990 | 3421 | 2535 | 1482 | 3.41771054 | 3.27759027 | 3.421 | 3.416
3.069444444 | 11050 | 3415 | 2534 | 1484 | 3.41673756 | 3.2773509 | 3.415 | 3.415
3.086388889 | 11111 | 3415 | 2534 | 1484 | 3.41555119 | 3.27681446 | 3.415 | 3.415
3.103055556 | 11171 | 3416 | 2533 | 1483 | 3.41455126 | 3.27704644 | 3.416 | 3.414
3.12 | 11232 | 3412 | 2532 | 1484 | 3.41332078 | 3.27666163 | 3.412 | 3.412
3.136666667 | 11292 | 3411 | 2531 | 1484 | 3.41206646 | 3.27625942 | 3.411 | 3.411
3.153333333 | 11352 | 3412 | 2530 | 1483 | 3.41108298 | 3.27614927 | 3.412 | 3.409
3.170277778 | 11413 | 3410 | 2529 | 1483 | 3.41004992 | 3.27580571 | 3.41 | 3.408
3.186944444 | 11473 | 3409 | 2528 | 1483 | 3.40840244 | 3.27514243 | 3.409 | 3.407
3.203888889 | 11534 | 3407 | 2527 | 1483 | 3.40710807 | 3.27478242 | 3.407 | 3.405
3.220555556 | 11594 | 3404 | 2526 | 1484 | 3.40572739 | 3.27423954 | 3.404 | 3.404
3.237222222 | 11654 | 3402 | 2525 | 1484 | 3.40439653 | 3.27385712 | 3.402 | 3.403
3.254166667 | 11715 | 3402 | 2525 | 1484 | 3.40299582 | 3.27334642 | 3.402 | 3.403
3.270833333 | 11775 | 3400 | 2523 | 1484 | 3.40147448 | 3.27286291 | 3.4 | 3.400
3.2875 | 11835 | 3398 | 2522 | 1484 | 3.40009141 | 3.27254105 | 3.398 | 3.399
3.304444444 | 11896 | 3397 | 2521 | 1484 | 3.39826727 | 3.27216792 | 3.397 | 3.397
3.321111111 | 11956 | 3409 | 2530 | 1484 | 3.39663839 | 3.2717483 | 3.409 | 3.409
3.338055556 | 12017 | 3410 | 2529 | 1483 | 3.39495659 | 3.27114058 | 3.41 | 3.408
3.354722222 | 12077 | 3407 | 2528 | 1484 | 3.39321589 | 3.27064109 | 3.407 | 3.407
3.371388889 | 12137 | 3406 | 2526 | 1483 | 3.39144087 | 3.27024102 | 3.406 | 3.404
3.388333333 | 12198 | 3402 | 2525 | 1484 | 3.38947177 | 3.26976275 | 3.402 | 3.403
3.405 | 12258 | 3401 | 2524 | 1484 | 3.38755965 | 3.26939154 | 3.401 | 3.401
3.421944444 | 12319 | 3400 | 2523 | 1484 | 3.38551331 | 3.26884413 | 3.4 | 3.400
3.438611111 | 12379 | 3397 | 2521 | 1484 | 3.38333464 | 3.26818895 | 3.397 | 3.397
3.455277778 | 12439 | 3394 | 2519 | 1484 | 3.38103032 | 3.26759934 | 3.394 | 3.395
3.472222222 | 12500 | 3393 | 2518 | 1484 | 3.37860847 | 3.26704383 | 3.393 | 3.393
3.488888889 | 12560 | 3390 | 2516 | 1484 | 3.37614489 | 3.26626229 | 3.39 | 3.391
3.505833333 | 12621 | 3388 | 2514 | 1484 | 3.37328744 | 3.26553059 | 3.388 | 3.388
3.5225 | 12681 | 3386 | 2513 | 1484 | 3.37060499 | 3.26478171 | 3.386 | 3.387
3.539166667 | 12741 | 3384 | 2511 | 1484 | 3.36764121 | 3.26400495 | 3.384 | 3.384
3.556111111 | 12802 | 3381 | 2509 | 1484 | 3.36465311 | 3.26317835 | 3.381 | 3.381
3.572777778 | 12862 | 3359 | 2493 | 1484 | 3.36135936 | 3.26240063 | 3.359 | 3.360
3.589444444 | 12922 | 3355 | 2490 | 1484 | 3.35800266 | 3.26148462 | 3.355 | 3.356
3.606388889 | 12983 | 3353 | 2488 | 1484 | 3.35439801 | 3.26020956 | 3.353 | 3.353
3.623055556 | 13043 | 3349 | 2485 | 1484 | 3.3506422 | 3.25888586 | 3.349 | 3.349
3.64 | 13104 | 3344 | 2483 | 1485 | 3.34674144 | 3.25744987 | 3.344 | 3.346
3.656666667 | 13164 | 3340 | 2480 | 1485 | 3.34261823 | 3.25590801 | 3.34 | 3.342
3.673333333 | 13224 | 3336 | 2477 | 1485 | 3.33841205 | 3.25409842 | 3.336 | 3.338
3.690277778 | 13285 | 3331 | 2477 | 1487 | 3.33388805 | 3.25062752 | 3.331 | 3.338
3.706944444 | 13345 | 3327 | 2477 | 1489 | 3.32929826 | 3.24623942 | 3.327 | 3.338
3.723888889 | 13406 | 3321 | 2476 | 1491 | 3.32467794 | 3.24113965 | 3.321 | 3.337
3.740555556 | 13466 | 3316 | 2476 | 1493 | 3.31980801 | 3.23658276 | 3.316 | 3.337
3.757222222 | 13526 | 3312 | 2476 | 1495 | 3.31483626 | 3.23180938 | 3.312 | 3.337
3.774166667 | 13587 | 3305 | 2476 | 1498 | 3.30957103 | 3.22676349 | 3.305 | 3.337
3.790833333 | 13647 | 3301 | 2476 | 1500 | 3.30432034 | 3.22164869 | 3.301 | 3.337
3.8075 | 13707 | 3294 | 2476 | 1503 | 3.2987361 | 3.21618271 | 3.294 | 3.337
3.824444444 | 13768 | 3293 | 2477 | 1504 | 3.293185 | 3.21062469 | 3.293 | 3.338
3.841111111 | 13828 | 3289 | 2477 | 1506 | 3.2874887 | 3.20500469 | 3.289 | 3.338
3.858055556 | 13889 | 3282 | 2477 | 1509 | 3.28183055 | 3.19928479 | 3.282 | 3.338
3.874722222 | 13949 | 3276 | 2477 | 1512 | 3.27588964 | 3.19331956 | 3.276 | 3.338
3.891388889 | 14009 | 3269 | 2477 | 1515 | 3.26993227 | 3.18729424 | 3.269 | 3.338
3.908333333 | 14070 | 3263 | 2477 | 1518 | 3.26371956 | 3.1809516 | 3.263 | 3.338
3.925 | 14130 | 3257 | 2477 | 1521 | 3.25752378 | 3.17464209 | 3.257 | 3.338
3.941944444 | 14191 | 3250 | 2477 | 1524 | 3.25112557 | 3.16775846 | 3.25 | 3.338
3.958611111 | 14251 | 3244 | 2477 | 1527 | 3.24449682 | 3.16173506 | 3.244 | 3.338
3.975277778 | 14311 | 3237 | 2477 | 1530 | 3.23780203 | 3.15491033 | 3.237 | 3.338
3.992222222 | 14372 | 3231 | 2477 | 1533 | 3.23100758 | 3.14797616 | 3.231 | 3.338
4.008888889 | 14432 | 3223 | 2477 | 1537 | 3.22403979 | 3.14105034 | 3.223 | 3.338
4.025833333 | 14493 | 3216 | 2477 | 1540 | 3.21689534 | 3.13369751 | 3.216 | 3.338
4.0425 | 14553 | 3208 | 2477 | 1544 | 3.21042728 | 3.12716794 | 3.208 | 3.338
4.059166667 | 14613 | 3202 | 2477 | 1547 | 3.2024076 | 3.11918664 | 3.202 | 3.338
4.076111111 | 14674 | 3211 | 2492 | 1552 | 3.19458055 | 3.11136079 | 3.211 | 3.358
4.092777778 | 14734 | 3203 | 2492 | 1556 | 3.1867373 | 3.10360718 | 3.203 | 3.358
4.109444444 | 14794 | 3196 | 2493 | 1560 | 3.17891097 | 3.0957458 | 3.196 | 3.360
4.126388889 | 14855 | 3187 | 2493 | 1564 | 3.17052436 | 3.08749247 | 3.187 | 3.360
4.143055556 | 14915 | 3179 | 2493 | 1568 | 3.16180658 | 3.07865286 | 3.179 | 3.360
4.16 | 14976 | 3169 | 2493 | 1573 | 3.15303254 | 3.07023525 | 3.169 | 3.360
4.176666667 | 15036 | 3161 | 2493 | 1577 | 3.14415908 | 3.06123972 | 3.161 | 3.360
4.193333333 | 15096 | 3151 | 2493 | 1582 | 3.13507867 | 3.05233526 | 3.151 | 3.360
4.210277778 | 15157 | 3143 | 2493 | 1586 | 3.125875 | 3.04306459 | 3.143 | 3.360
4.226944444 | 15217 | 3141 | 2494 | 1588 | 3.11635399 | 3.03352547 | 3.141 | 3.361
4.243888889 | 15278 | 3124 | 2493 | 1596 | 3.10651398 | 3.02381325 | 3.124 | 3.360
4.260555556 | 15338 | 3120 | 2493 | 1598 | 3.09634924 | 3.01375055 | 3.12 | 3.360
4.277222222 | 15398 | 3105 | 2494 | 1606 | 3.08595777 | 3.00329876 | 3.105 | 3.361
4.294166667 | 15459 | 3092 | 2494 | 1613 | 3.07539964 | 2.99281883 | 3.092 | 3.361
4.310833333 | 15519 | 3081 | 2493 | 1618 | 3.06436944 | 2.98198605 | 3.081 | 3.360
4.327777778 | 15580 | 3051 | 2478 | 1624 | 3.05312943 | 2.97075081 | 3.051 | 3.339
4.344444444 | 15640 | 3040 | 2478 | 1630 | 3.04170012 | 2.9594543 | 3.04 | 3.339
4.361111111 | 15700 | 3027 | 2478 | 1637 | 3.02986002 | 2.94780636 | 3.027 | 3.339
4.378055556 | 15761 | 3020 | 2478 | 1641 | 3.01760364 | 2.93536115 | 3.02 | 3.339
4.394722222 | 15821 | 3007 | 2478 | 1648 | 3.00290108 | 2.92081785 | 3.007 | 3.339
4.411666667 | 15882 | 2994 | 2478 | 1655 | 2.98989272 | 2.90789127 | 2.994 | 3.339
4.428333333 | 15942 | 2974 | 2478 | 1666 | 2.97678328 | 2.89504099 | 2.974 | 3.339
4.445 | 16002 | 2960 | 2478 | 1674 | 2.96295834 | 2.8815093 | 2.96 | 3.339
4.461944444 | 16063 | 2951 | 2478 | 1679 | 2.9489994 | 2.86780429 | 2.951 | 3.339
4.478611111 | 16123 | 2930 | 2479 | 1692 | 2.93368578 | 2.85266924 | 2.93 | 3.341
4.495277778 | 16183 | 2916 | 2479 | 1700 | 2.9175427 | 2.83706188 | 2.916 | 3.341
4.512222222 | 16244 | 2902 | 2479 | 1708 | 2.90058136 | 2.82031274 | 2.902 | 3.341
4.528888889 | 16304 | 2880 | 2479 | 1721 | 2.88273954 | 2.80201936 | 2.88 | 3.341
4.545833333 | 16365 | 2859 | 2479 | 1734 | 2.86377478 | 2.7833693 | 2.859 | 3.341
4.5625 | 16425 | 2842 | 2480 | 1745 | 2.84375286 | 2.76359725 | 2.842 | 3.342
4.579166667 | 16485 | 2822 | 2481 | 1758 | 2.82235432 | 2.7423799 | 2.822 | 3.343
4.596111111 | 16546 | 2806 | 2481 | 1768 | 2.79946232 | 2.71974206 | 2.806 | 3.343
4.612777778 | 16606 | 2776 | 2481 | 1787 | 2.77482033 | 2.69538569 | 2.776 | 3.343
4.629722222 | 16667 | 2749 | 2481 | 1805 | 2.74784684 | 2.66858792 | 2.749 | 3.343
4.646388889 | 16727 | 2717 | 2481 | 1826 | 2.71805406 | 2.63895464 | 2.717 | 3.343
4.663055556 | 16787 | 2691 | 2482 | 1844 | 2.68517566 | 2.60629439 | 2.691 | 3.345
4.68 | 16848 | 2653 | 2482 | 1871 | 2.64880204 | 2.5701189 | 2.653 | 3.345
4.696666667 | 16908 | 2612 | 2483 | 1901 | 2.60859227 | 2.53013253 | 2.612 | 3.346
4.713333333 | 16968 | 2570 | 2483 | 1932 | 2.5647223 | 2.48650599 | 2.57 | 3.346
4.730277778 | 17029 | 2523 | 2483 | 1968 | 2.51862979 | 2.44064093 | 2.523 | 3.346
4.746944444 | 17089 | 2475 | 2484 | 2007 | 2.4731617 | 2.3955009 | 2.475 | 3.347
4.763888889 | 17150 | 2430 | 2485 | 2045 | 2.4301548 | 2.35273194 | 2.43 | 3.349
4.780555556 | 17210 | 2398 | 2485 | 2072 0.000782838 0.0006976252 | 2.398 | 3.349
4.797222222 | 17270 | 2398 | 2485 | 2072 0.0007157115 0.0006429742 | 2.398 | 3.349
4.814166667 | 17331 | 2398 | 2485 | 2072 0.0007129203 0.0006421718 | 2.398 | 3.349

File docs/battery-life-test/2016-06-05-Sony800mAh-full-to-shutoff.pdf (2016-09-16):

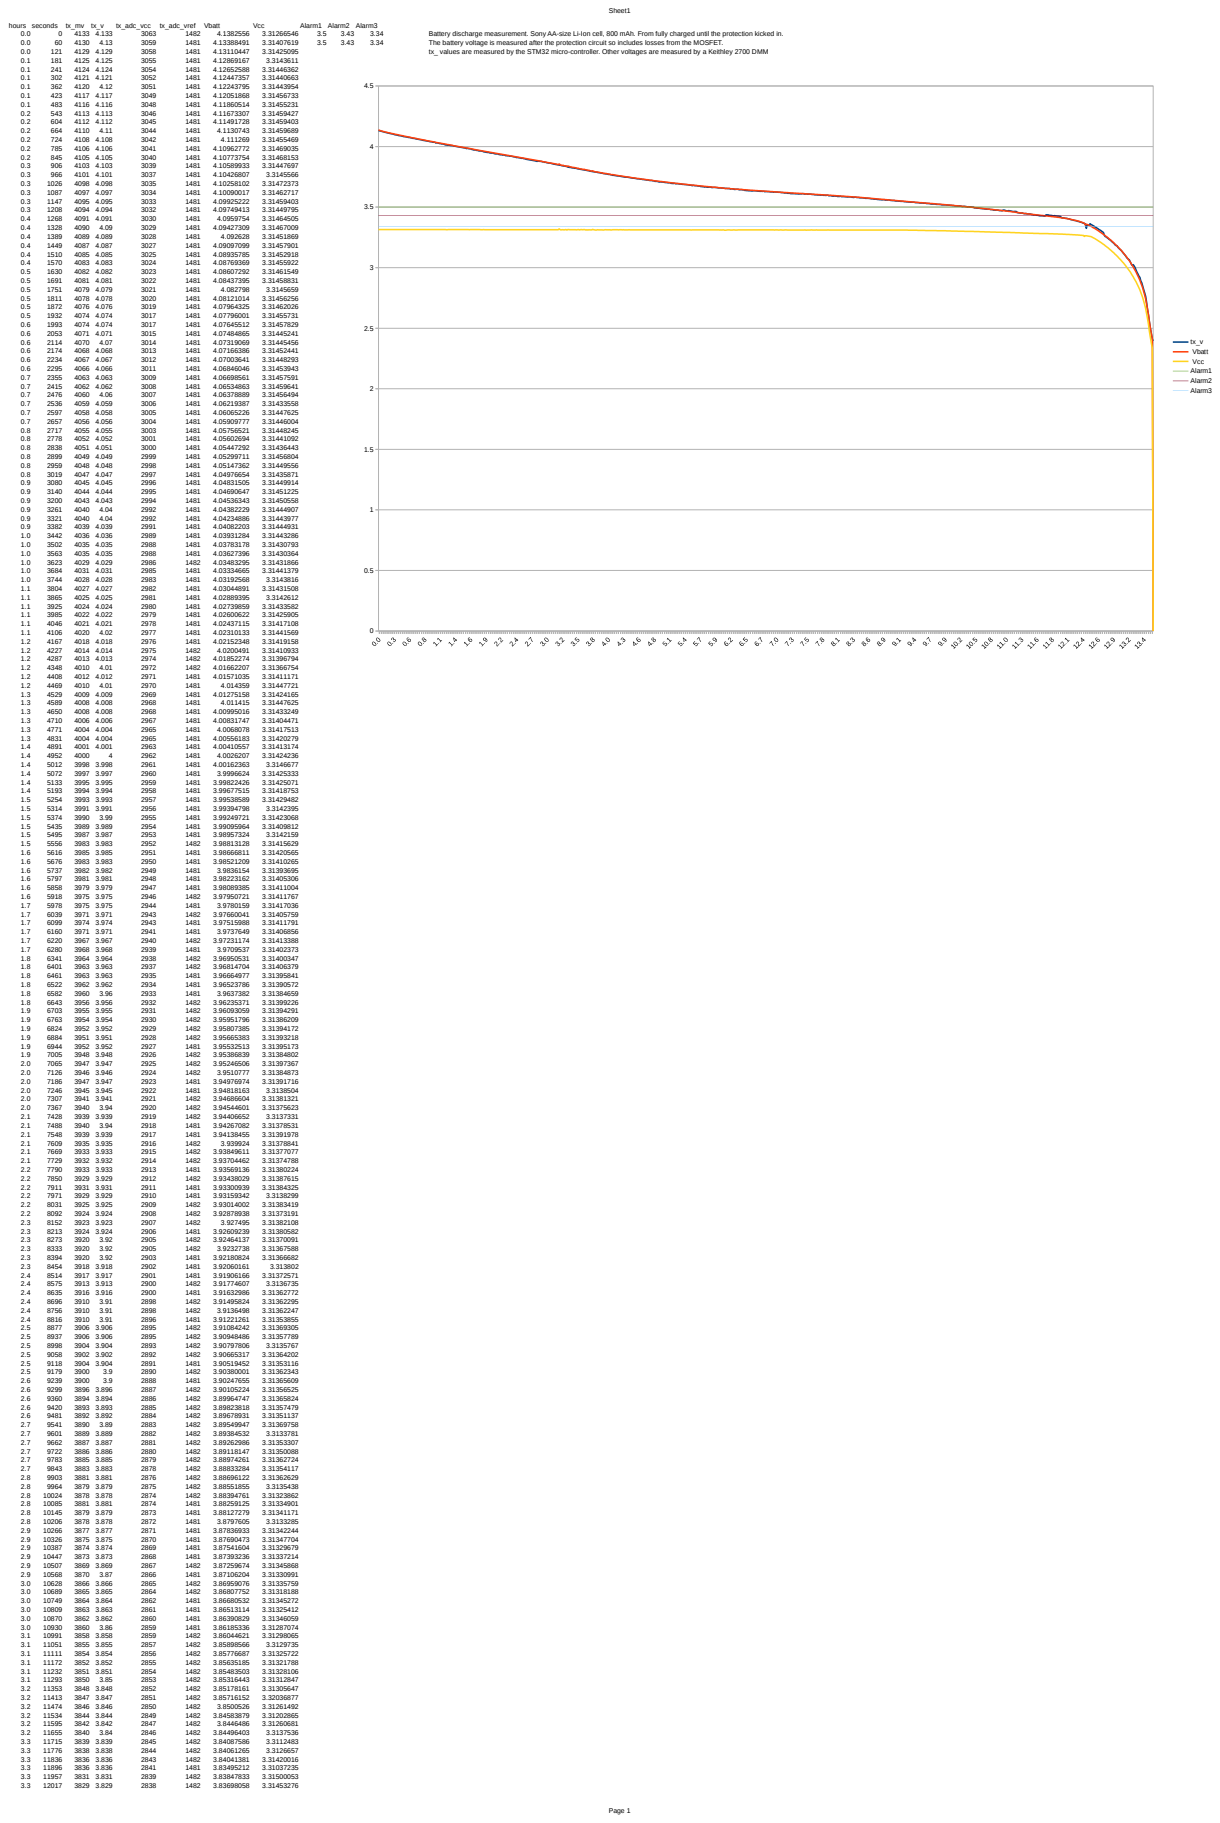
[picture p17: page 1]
Sheet1; hours seconds tx_mv tx_v; tx_adc_vcc tx_adc_vref Vbatt; Vcc; Alarm1 Alarm2 Alarm3; Battery discharge measurement. Sony AA-size Li-Ion cell, 800 mAh. From fully charged until the protection kicked in.; The battery voltage is measured after the protection circuit so includes losses from the MOSFET.; tx_ values are measured by the STM32 micro-controller. Other voltages are measured by a Keithley 2700 DMM; tx_v Vbatt Vcc Alarm1 Alarm2 Alarm3

Page

3.4 | 12078 | 3828 3.828 | 2837 | 1482 | 3.83339643 | 3.31297493
3.4 | 12138 | 3827 3.827 | 2836 | 1482 | 3.83178043 | 3.31310415
3.4 | 12198 | 3825 3.825 | 2835 | 1482 | 3.83079267 | 3.31373954
3.4 | 12259 | 3824 3.824 | 2834 | 1482 | 3.82793665 | 3.31271029
3.4 | 12319 | 3823 3.823 | 2833 | 1482 | 3.82745266 | 3.31330276
3.4 | 12379 | 3821 3.821 | 2832 | 1482 | 3.8257525 | 3.31310248
3.5 | 12440 | 3820 | 3.82 | 2831 | 1482 | 3.82420588 | 3.31331396
3.5 | 12500 | 3819 3.819 | 2830 | 1482 | 3.82191086 | 3.31241918
3.5 | 12561 | 3816 3.816 | 2828 | 1482 | 3.82083488 | 3.31302357
3.5 | 12621 | 3815 3.815 | 2827 | 1482 | 3.82059455 | 3.31413245
3.5 | 12681 | 3813 3.813 | 2826 | 1482 | 3.81694031 | 3.31198454
3.5 | 12742 | 3812 3.812 | 2825 | 1482 | 3.81568623 | 3.31288743
3.6 | 12802 | 3811 3.811 | 2824 | 1482 | 3.81577158 | 3.31414819
3.6 | 12862 | 3809 3.809 | 2823 | 1482 | 3.81247354 | 3.31306791
3.6 | 12923 | 3808 3.808 | 2822 | 1482 | 3.81104803 | 3.31268239
3.6 | 12983 | 3807 3.807 | 2821 | 1482 | 3.81168985 | 3.31421804
3.6 | 13044 | 3805 3.805 | 2820 | 1482 | 3.8093698 | 3.313766
3.6 | 13104 | 3804 3.804 | 2819 | 1482 | 3.80652785 | 3.31103206
3.7 | 13164 | 3802 3.802 | 2818 | 1482 | 3.80618191 | 3.312675
3.7 | 13225 | 3801 3.801 | 2817 | 1482 | 3.80197453 | 3.31051803
3.7 | 13285 | 3800 | 3.8 | 2816 | 1482 | 3.80362034 | 3.31389809
3.7 | 13346 | 3797 3.797 | 2814 | 1482 | 3.80064821 | 3.31218839
3.7 | 13406 | 3796 3.796 | 2813 | 1482 | 3.79827619 | 3.31203556
3.7 | 13466 | 3794 3.794 | 2812 | 1482 | 3.7975893 | 3.31193042
3.8 | 13527 | 3793 3.793 | 2811 | 1482 | 3.80019736 | 3.31530333
3.8 | 13587 | 3792 3.792 | 2810 | 1482 | 3.79621601 | 3.31369472
3.8 | 13647 | 3790 | 3.79 | 2809 | 1482 | 3.79350591 | 3.31251836
3.8 | 13708 | 3789 3.789 | 2808 | 1482 | 3.79032159 | 3.31087685
3.8 | 13768 | 3788 3.788 | 2807 | 1482 | 3.78946376 | 3.3111167
3.8 | 13829 | 3786 3.786 | 2806 | 1482 | 3.79047251 | 3.31361985
3.9 | 13889 | 3785 3.785 | 2805 | 1482 | 3.78779459 | 3.31219101
3.9 | 13949 | 3784 3.784 | 2804 | 1482 | 3.78629589 | 3.3123467
3.9 | 14010 | 3782 3.782 | 2803 | 1482 | 3.7841053 | 3.31135917
3.9 | 14070 | 3781 3.781 | 2802 | 1482 | 3.78376651 | 3.312433
3.9 | 14131 | 3780 | 3.78 | 2801 | 1482 | 3.78261638 | 3.31184149
3.9 | 14191 | 3778 3.778 | 2800 | 1482 | 3.77765894 | 3.31048298
4.0 | 14251 | 3777 3.777 | 2799 | 1482 | 3.77942348 | 3.31240773
4.0 | 14312 | 3775 3.775 | 2798 | 1482 | 3.77802539 | 3.31266952
4.0 | 14372 | 3774 3.774 | 2797 | 1482 | 3.77723479 | 3.31308103
4.0 | 14432 | 3773 3.773 | 2796 | 1482 | 3.77463818 | 3.31171966
4.0 | 14493 | 3771 3.771 | 2795 | 1482 | 3.77489901 | 3.31365037
4.0 | 14553 | 3770 | 3.77 | 2794 | 1482 | 3.77148175 | 3.31172323
4.1 | 14614 | 3769 3.769 | 2793 | 1482 | 3.77150679 | 3.31280279
4.1 | 14674 | 3766 3.766 | 2791 | 1482 | 3.76736379 | 3.30984163
4.1 | 14734 | 3765 3.765 | 2790 | 1482
4.1 | 14795 | 3763 3.763 | 2789 | 1482 | 3.76774764 | 3.3125937
4.1 | 14855 | 3762 3.762 | 2788 | 1482 | 3.76634455 | 3.31263924
4.1 | 14916 | 3761 3.761 | 2787 | 1482 | 3.76507521 | 3.31264544
4.2 | 14976 | 3759 3.759 | 2786 | 1482 | 3.76390409 | 3.31262732
4.2 | 15036 | 3758 3.758 | 2785 | 1482 | 3.76264858 | 3.31264734
4.2 | 15097 | 3757 3.757 | 2784 | 1482 | 3.7612884 | 3.31258798
4.2 | 15157 | 3757 3.757 | 2784 | 1482 | 3.76004791 | 3.31244826
4.2 | 15217 | 3755 3.755 | 2783 | 1482 | 3.75891256 | 3.31258583
4.2 | 15278 | 3754 3.754 | 2782 | 1482 | 3.75761104 | 3.31255603
4.3 | 15338 | 3753 3.753 | 2781 | 1482 | 3.75633907 | 3.3125329
4.3 | 15399 | 3751 3.751 | 2780 | 1482 | 3.75521684 | 3.31250691
4.3 | 15459 | 3750 | 3.75 | 2779 | 1482 | 3.754076 | 3.31259227
4.3 | 15519 | 3748 3.748 | 2778 | 1482 | 3.75220013 | 3.31201577
4.3 | 15580 | 3747 3.747 | 2777 | 1482 | 3.7515564 | 3.31246758
4.3 | 15640 | 3747 3.747 | 2777 | 1482 | 3.75022864 | 3.31158829
4.4 | 15701 | 3747 3.747 | 2777 | 1482
4.4 | 15761 | 3746 3.746 | 2776 | 1482 | 3.74799943 | 3.31246042
4.4 | 15821 | 3744 3.744 | 2775 | 1482 | 3.74689126 | 3.31254983
4.4 | 15882 | 3743 3.743 | 2774 | 1482 | 3.74582887 | 3.31243753
4.4 | 15942 | 3742 3.742 | 2773 | 1482 | 3.7445693 | 3.31232071
4.4 | 16002 | 3740 | 3.74 | 2772 | 1482 | 3.74337411 | 3.31237221
4.5 | 16063 | 3739 3.739 | 2771 | 1482 | 3.74228692 | 3.31243181
4.5 | 16123 | 3739 3.739 | 2771 | 1482 | 3.7411859 | 3.31245279
4.5 | 16184 | 3738 3.738 | 2770 | 1482 | 3.73999786 | 3.31236124
4.5 | 16244 | 3736 3.736 | 2769 | 1482 | 3.73883009 | 3.31231594
4.5 | 16304 | 3735 3.735 | 2768 | 1482 | 3.73780251 | 3.31238437
4.5 | 16365 | 3734 3.734 | 2767 | 1482 | 3.73670959 | 3.3123374
4.6 | 16425 | 3734 3.734 | 2767 | 1482 | 3.73551059 | 3.31223536
4.6 | 16486 | 3732 3.732 | 2766 | 1482 | 3.73444653 | 3.31226778
4.6 | 16546 | 3731 3.731 | 2765 | 1482 | 3.73340774 | 3.31210303
4.6 | 16606 | 3730 | 3.73 | 2764 | 1482 | 3.73229957 | 3.31216288
4.6 | 16667 | 3728 3.728 | 2763 | 1482 | 3.73107576 | 3.31208086
4.6 | 16727 | 3728 3.728 | 2763 | 1482 | 3.7300303 | 3.31213045
4.7 | 16788 | 3727 3.727 | 2762 | 1482 | 3.72901678 | 3.31216097
4.7 | 16848 | 3726 3.726 | 2761 | 1482 | 3.72774315 | 3.31210494
4.7 | 16908 | 3724 3.724 | 2760 | 1482 | 3.72688532 | 3.31223607
4.7 | 16969 | 3723 3.723 | 2759 | 1482 | 3.72586036 | 3.31222248
4.7 | 17029 | 3723 3.723 | 2759 | 1482 | 3.72472882 | 3.31210399
4.7 | 17089 | 3721 3.721 | 2758 | 1482 | 3.72376275 | 3.31207085
4.8 | 17150 | 3720 | 3.72 | 2757 | 1482 | 3.72250962 | 3.31195259
4.8 | 17210 | 3720 | 3.72 | 2757 | 1482 | 3.72159719 | 3.31202888
4.8 | 17271 | 3719 3.719 | 2756 | 1482 | 3.72066808 | 3.31220222
4.8 | 17331 | 3717 3.717 | 2755 | 1482 | 3.71966529 | 3.31210709
4.8 | 17391 | 3717 3.717 | 2755 | 1482 | 3.71869302 | 3.31204557
4.8 | 17452 | 3713 3.713 | 2752 | 1482 | 3.71738529 | 3.31189561
4.9 | 17512 | 3713 3.713 | 2752 | 1482 | 3.71646976 | 3.3120091
4.9 | 17572 | 3712 3.712 | 2751 | 1482 | 3.71535301 | 3.31180263
4.9 | 17633 | 3711 3.711 | 2750 | 1482 | 3.71447682 | 3.31209803
4.9 | 17693 | 3709 3.709 | 2749 | 1482 | 3.71363878 | 3.31209111
4.9 | 17754 | 3707 3.707 | 2749 | 1483 | 3.71247554 | 3.31196213
4.9 | 17814 | 3708 3.708 | 2748 | 1482 | 3.71139073 | 3.3116374
5.0 | 17874 | 3707 3.707 | 2747 | 1482 | 3.71059489 | 3.31206989
5.0 | 17935 | 3707 3.707 | 2747 | 1482 | 3.70962524 | 3.31201816
5.0 | 17995 | 3705 3.705 | 2746 | 1482 | 3.70863628 | 3.31190419
5.0 | 18056 | 3704 3.704 | 2745 | 1482 | 3.70765972 | 3.31183314
5.0 | 18116 | 3703 3.703 | 2744 | 1482 | 3.70647407 | 3.31125093
5.0 | 18176 | 3703 3.703 | 2744 | 1482 | 3.70592499 | 3.31186748
5.1 | 18237 | 3701 3.701 | 2743 | 1482 | 3.70492053 | 3.31180811
5.1 | 18297 | 3700 | 3.7 | 2742 | 1482 | 3.70393872 | 3.31194711
5.1 | 18358 | 3701 3.701 | 2743 | 1482 | 3.70310807 | 3.31190825
5.1 | 18418 | 3700 | 3.7 | 2742 | 1482 | 3.70210457 | 3.31172156
5.1 | 18478 | 3696 3.696 | 2741 | 1483 | 3.70086837 | 3.31180859
5.1 | 18539 | 3696 3.696 | 2741 | 1483 | 3.70031667 | 3.31205368
5.2 | 18599 | 3695 3.695 | 2740 | 1483 | 3.69939208 | 3.31198549
5.2 | 18659 | 3696 3.696 | 2739 | 1482 | 3.6985743 | 3.3120482
5.2 | 18720 | 3696 3.696 | 2739 | 1482 | 3.69758964 | 3.3119452
5.2 | 18780 | 3692 3.692 | 2738 | 1483 | 3.69660997 | 3.31189394
5.2 | 18841 | 3695 3.695 | 2738 | 1482 | 3.6956234 | 3.31183052
5.3 | 18901 | 3693 3.693 | 2737 | 1482 | 3.69483924 | 3.31184626
5.3 | 18961 | 3692 3.692 | 2736 | 1482 | 3.69401765 | 3.31192398
5.3 | 19022 | 3690 | 3.69 | 2735 | 1482 | 3.69308066 | 3.311764
5.3 | 19082 | 3690 | 3.69 | 2735 | 1482 | 3.6921134 | 3.3118453
5.3 | 19143 | 3689 3.689 | 2734 | 1482 | 3.69121814 | 3.31185126
5.3 | 19203 | 3688 3.688 | 2733 | 1482 | 3.69034338 | 3.31172562
5.4 | 19263 | 3688 3.688 | 2733 | 1482 | 3.68960667 | 3.31183648
5.4 | 19324 | 3686 3.686 | 2732 | 1482 | 3.68868732 | 3.31181598
5.4 | 19384 | 3686 3.686 | 2732 | 1482 | 3.68769002 | 3.31181598
5.4 | 19445 | 3685 3.685 | 2731 | 1482 | 3.68688655 | 3.3117094
5.4 | 19505 | 3685 3.685 | 2731 | 1482 | 3.68617845 | 3.31189728
5.4 | 19565 | 3684 3.684 | 2730 | 1482 | 3.68535566 | 3.31183577
5.5 | 19626 | 3682 3.682 | 2729 | 1482 | 3.68440747 | 3.31188178
5.5 | 19686 | 3680 | 3.68 | 2729 | 1483 | 3.68344903 | 3.31159186
5.5 | 19746 | 3681 3.681 | 2728 | 1482 | 3.68189073 | 3.3108952
5.5 | 19807 | 3677 3.677 | 2727 | 1483 | 3.68183708 | 3.3115871
5.5 | 19867 | 3680 | 3.68 | 2727 | 1482 | 3.68100142 | 3.31156993
5.5 | 19928 | 3678 3.678 | 2726 | 1482 | 3.68022919 | 3.31166172
5.6 | 19988 | 3676 3.676 | 2726 | 1483 | 3.67947125 | 3.31161022
5.6 | 20048 | 3677 3.677 | 2725 | 1482 | 3.67870784 | 3.31182289
5.6 | 20109 | 3677 3.677 | 2725 | 1482 | 3.67783785 | 3.31177068
5.6 | 20169 | 3674 3.674 | 2723 | 1482 | 3.67711306 | 3.31171417
5.6 | 20230 | 3673 3.673 | 2722 | 1482 | 3.67633033 | 3.31172609
5.6 | 20290 | 3673 3.673 | 2722 | 1482 | 3.67537117 | 3.31161404
5.7 | 20350 | 3669 3.669 | 2721 | 1483 | 3.67475796 | 3.31152177
5.7 | 20411 | 3669 3.669 | 2721 | 1483 | 3.67389655 | 3.31144166
5.7 | 20471 | 3668 3.668 | 2720 | 1483 | 3.67312455 | 3.31171012
5.7 | 20531 | 3668 3.668 | 2720 | 1483 | 3.67243981 | 3.31163716
5.7 | 20592 | 3666 3.666 | 2719 | 1483 | 3.6713984 | 3.31145835
5.7 | 20652 | 3668 3.668 | 2718 | 1482 | 3.67079949 | 3.31147408
5.8 | 20713 | 3665 3.665 | 2718 | 1483 | 3.66996837 | 3.31157064
5.8 | 20773 | 3664 3.664 | 2717 | 1483 | 3.66923976 | 3.31141567
5.8 | 20833 | 3664 3.664 | 2717 | 1483 | 3.66846132 | 3.31146646
5.8 | 20894 | 3665 3.665 | 2716 | 1482 | 3.66789651 | 3.31148338
5.8 | 20954 | 3665 3.665 | 2716 | 1482 | 3.66697454 | 3.31142139
5.8 | 21015 | 3663 3.663 | 2715 | 1482 | 3.6664598 | 3.31154084
5.9 | 21075 | 3661 3.661 | 2715 | 1483 | 3.66571832 | 3.31159043
5.9 | 21135 | 3663 3.663 | 2715 | 1482 | 3.66454935 | 3.31128716
5.9 | 21196 | 3662 3.662 | 2714 | 1482 | 3.66420746 | 3.31148124
5.9 | 21256 | 3662 3.662 | 2714 | 1482 | 3.66360354 | 3.31143713
5.9 | 21317 | 3661 3.661 | 2713 | 1482 | 3.66269135 | 3.31141162
5.9 | 21377 | 3661 3.661 | 2713 | 1482 | 3.66200519 | 3.31146049
6.0 | 21437 | 3659 3.659 | 2712 | 1482 | 3.66122222 | 3.31125784
6.0 | 21498 | 3659 3.659 | 2712 | 1482 | 3.66048002 | 3.31134748
6.0 | 21558 | 3658 3.658 | 2711 | 1482 | 3.65943837 | 3.31108141
6.0 | 21618 | 3658 3.658 | 2711 | 1482 | 3.65935969 | 3.31170607
6.0 | 21679 | 3657 3.657 | 2710 | 1482 | 3.65840816 | 3.31123376
6.0 | 21739 | 3657 3.657 | 2710 | 1482 | 3.657619 | 3.31137562
6.1 | 21800 | 3655 3.655 | 2709 | 1482 | 3.65721178 | 3.3115201
6.1 | 21860 | 3655 3.655 | 2709 | 1482 | 3.65466642 | 3.30953121
6.1 | 21920 | 3654 3.654 | 2708 | 1482 | 3.65263557 | 3.30845308
6.1 | 21981 | 3654 3.654 | 2708 | 1482 | 3.65483761 | 3.31082129
6.1 | 22041 | 3653 3.653 | 2707 | 1482 | 3.65456438 | 3.31127882
6.1 | 22102 | 3653 3.653 | 2707 | 1482 | 3.65471053 | 3.31229758
6.2 | 22162 | 3653 3.653 | 2707 | 1482 | 3.6543076 | 3.31193924
6.2 | 22222 | 3649 3.649 | 2706 | 1483 | 3.65112185 | 3.310184
6.2 | 22283 | 3651 3.651 | 2706 | 1482 | 3.65126991 | 3.31068087
6.2 | 22343 | 3650 | 3.65 | 2705 | 1482 | 3.65039492 | 3.31053066
6.2 | 22403 | 3650 | 3.65 | 2705 | 1482 | 3.65063977 | 3.31128931
6.2 | 22464 | 3646 3.646 | 2704 | 1483 | 3.64992428 | 3.3112483
6.3 | 22524 | 3646 3.646 | 2704 | 1483 | 3.64843321 | 3.31048131
6.3 | 22585 | 3647 3.647 | 2703 | 1482 | 3.64784431 | 3.3104291
6.3 | 22645 | 3647 3.647 | 2703 | 1482 | 3.64782429 | 3.3110745
6.3 | 22705 | 3647 3.647 | 2703 | 1482 | 3.64768124 | 3.31158113
6.3 | 22766 | 3643 3.643 | 2702 | 1483 | 3.64697266 | 3.31147623
6.3 | 22826 | 3643 3.643 | 2702 | 1483 | 3.64648128 | 3.31148767
6.4 | 22887 | 3645 3.645 | 2701 | 1482 | 3.64593649 | 3.31149793
6.4 | 22947 | 3643 3.643 | 2700 | 1482 | 3.64533615 | 3.31150293
6.4 | 23007 | 3642 3.642 | 2699 | 1482 | 3.64445138 | 3.31138754
6.4 | 23068 | 3642 3.642 | 2699 | 1482 | 3.64382911 | 3.31146455
6.4 | 23128 | 3638 3.638 | 2698 | 1483 | 3.64332223 | 3.31131101
6.4 | 23188 | 3638 3.638 | 2698 | 1483 | 3.64253497 | 3.31127739
6.5 | 23249 | 3637 3.637 | 2697 | 1483 | 3.64198065 | 3.31126475
6.5 | 23309 | 3637 3.637 | 2697 | 1483 | 3.64149427 | 3.31133652
6.5 | 23370 | 3635 3.635 | 2696 | 1483 | 3.64087558 | 3.3112855
6.5 | 23430 | 3635 3.635 | 2696 | 1483 | 3.64042211 | 3.31132746
6.5 | 23490 | 3635 3.635 | 2696 | 1483 | 3.63974929 | 3.31127405
6.5 | 23551 | 3634 3.634 | 2695 | 1483 | 3.6391499 | 3.31139827
6.6 | 23611 | 3634 3.634 | 2695 | 1483 | 3.63861108 | 3.31135583
6.6 | 23671 | 3635 3.635 | 2694 | 1482 | 3.63830519 | 3.31162405
6.6 | 23732 | 3635 3.635 | 2694 | 1482 | 3.63754964 | 3.31152105
6.6 | 23792 | 3635 3.635 | 2694 | 1482 | 3.63691616 | 3.31148577
6.6 | 23853 | 3633 3.633 | 2694 | 1483 | 3.63635898 | 3.31132126
6.6 | 23913 | 3633 3.633 | 2694 | 1483 | 3.63589096 | 3.31130624
6.7 | 23973 | 3631 3.631 | 2693 | 1483 | 3.63530636 | 3.31132817
6.7 | 24034 | 3634 3.634 | 2693 | 1482 | 3.63465762 | 3.31128192
6.7 | 24094 | 3630 | 3.63 | 2692 | 1483 | 3.63417053 | 3.31143522
6.7 | 24155 | 3632 3.632 | 2692 | 1482 | 3.63374472 | 3.31144047
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

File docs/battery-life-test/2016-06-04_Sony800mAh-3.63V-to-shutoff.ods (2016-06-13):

hours | seconds | tx_mv | tx_adc_vcc | tx_adc_vref | Vbatt | Vcc | tx_v | tx_vadc
0 | 0 | 3648 | 2707 | 1484 | 3.65167761 | 3.30906153 | 3.648 | 3.648
0.0166666667 | 60 | 3631 | 2693 | 1483 | 3.63366747 | 3.31014204 | 3.631 | 3.629
0.0336111111 | 121 | 3626 | 2689 | 1483 | 3.6275363 | 3.31023908 | 3.626 | 3.624
0.0502777778 | 181 | 3622 | 2686 | 1483 | 3.62382746 | 3.31036282 | 3.622 | 3.620
0.0669444444 | 241 | 3618 | 2683 | 1483 | 3.62096715 | 3.31043124 | 3.618 | 3.616
0.0838888889 | 302 | 3616 | 2682 | 1483 | 3.61852503 | 3.31031871 | 3.616 | 3.614
0.1005555556 | 362 | 3614 | 2680 | 1483 | 3.61645699 | 3.31037068 | 3.614 | 3.612
0.1172222222 | 422 | 3612 | 2679 | 1483 | 3.614573 | 3.31032896 | 3.612 | 3.610
0.1341666667 | 483 | 3610 | 2677 | 1483 | 3.61275458 | 3.31029153 | 3.61 | 3.608
0.1508333333 | 543 | 3608 | 2676 | 1483 | 3.61116648 | 3.31035805 | 3.608 | 3.606
0.1677777778 | 604 | 3607 | 2675 | 1483 | 3.60955596 | 3.31036854 | 3.607 | 3.605
0.1844444444 | 664 | 3606 | 2674 | 1483 | 3.60804296 | 3.31042433 | 3.606 | 3.604
0.2011111111 | 724 | 3604 | 2673 | 1483 | 3.60658455 | 3.31029034 | 3.604 | 3.602
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

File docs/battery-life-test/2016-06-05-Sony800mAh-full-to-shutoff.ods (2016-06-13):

hours | seconds | tx_mv | tx_v | tx_adc_vcc | tx_adc_vref | Vbatt | Vcc | Alarm1 | Alarm2 | Alarm3
0.0 | 0 | 4133 | 4.133 | 3063 | 1482 | 4.1382556 | 3.31266546 | 3.5 | 3.43 | 3.34 | Battery discharge measurement. Sony AA-size Li-Ion cell, 800 mAh. From fully charged until the protection kicked in.
0.0 | 60 | 4130 | 4.13 | 3059 | 1481 | 4.13388491 | 3.31407619 | 3.5 | 3.43 | 3.34 | The battery voltage is measured after the protection circuit so includes losses from the MOSFET.
0.0 | 121 | 4129 | 4.129 | 3058 | 1481 | 4.13110447 | 3.31425095 |  |  |  | tx_ values are measured by the STM32 micro-controller. Other voltages are measured by a Keithley 2700 DMM
0.1 | 181 | 4125 | 4.125 | 3055 | 1481 | 4.12869167 | 3.3143611
0.1 | 241 | 4124 | 4.124 | 3054 | 1481 | 4.12652588 | 3.31446362
0.1 | 302 | 4121 | 4.121 | 3052 | 1481 | 4.12447357 | 3.31440663
0.1 | 362 | 4120 | 4.12 | 3051 | 1481 | 4.12243795 | 3.31443954
0.1 | 423 | 4117 | 4.117 | 3049 | 1481 | 4.12051868 | 3.31456733
0.1 | 483 | 4116 | 4.116 | 3048 | 1481 | 4.11860514 | 3.31455231
0.2 | 543 | 4113 | 4.113 | 3046 | 1481 | 4.11673307 | 3.31459427
0.2 | 604 | 4112 | 4.112 | 3045 | 1481 | 4.11491728 | 3.31459403
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

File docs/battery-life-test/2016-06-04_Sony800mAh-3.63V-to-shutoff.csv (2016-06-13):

seconds | tx_mv | tx_adc_vcc | tx_adc_vref | Vbatt | Vcc
0 | 3648 | 2707 | 1484 | 3.65167761 | 3.30906153
60 | 3631 | 2693 | 1483 | 3.63366747 | 3.31014204
121 | 3626 | 2689 | 1483 | 3.6275363 | 3.31023908
181 | 3622 | 2686 | 1483 | 3.62382746 | 3.31036282
241 | 3618 | 2683 | 1483 | 3.62096715 | 3.31043124
302 | 3616 | 2682 | 1483 | 3.61852503 | 3.31031871
362 | 3614 | 2680 | 1483 | 3.61645699 | 3.31037068
422 | 3612 | 2679 | 1483 | 3.614573 | 3.31032896
483 | 3610 | 2677 | 1483 | 3.61275458 | 3.31029153
543 | 3608 | 2676 | 1483 | 3.61116648 | 3.31035805
604 | 3607 | 2675 | 1483 | 3.60955596 | 3.31036854
664 | 3606 | 2674 | 1483 | 3.60804296 | 3.31042433
724 | 3604 | 2673 | 1483 | 3.60658455 | 3.31029034
785 | 3603 | 2672 | 1483 | 3.60518909 | 3.31035161
845 | 3602 | 2671 | 1483 | 3.60375047 | 3.31032586
906 | 3600 | 2670 | 1483 | 3.60254288 | 3.31046534
966 | 3598 | 2668 | 1483 | 3.60116172 | 3.31038117
1026 | 3596 | 2667 | 1483 | 3.59969091 | 3.31045127
1087 | 3594 | 2665 | 1483 | 3.59825826 | 3.31046319
1147 | 3592 | 2664 | 1483 | 3.58005047 | 3.31049275
1207 | 3592 | 2664 | 1483 | 3.59539175 | 3.31043553
1268 | 3590 | 2662 | 1483 | 3.59408927 | 3.3104291
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

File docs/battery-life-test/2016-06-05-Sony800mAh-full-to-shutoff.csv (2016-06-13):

seconds | tx_mv | tx_adc_vcc | tx_adc_vref | Vbatt | Vcc
0 | 4133 | 3063 | 1482 | 4.1382556 | 3.31266546
60 | 4130 | 3059 | 1481 | 4.13388491 | 3.31407619
121 | 4129 | 3058 | 1481 | 4.13110447 | 3.31425095
181 | 4125 | 3055 | 1481 | 4.12869167 | 3.3143611
241 | 4124 | 3054 | 1481 | 4.12652588 | 3.31446362
302 | 4121 | 3052 | 1481 | 4.12447357 | 3.31440663
362 | 4120 | 3051 | 1481 | 4.12243795 | 3.31443954
423 | 4117 | 3049 | 1481 | 4.12051868 | 3.31456733
483 | 4116 | 3048 | 1481 | 4.11860514 | 3.31455231
543 | 4113 | 3046 | 1481 | 4.11673307 | 3.31459427
604 | 4112 | 3045 | 1481 | 4.11491728 | 3.31459403
664 | 4110 | 3044 | 1481 | 4.1130743 | 3.31459689
724 | 4108 | 3042 | 1481 | 4.111269 | 3.31455469
785 | 4106 | 3041 | 1481 | 4.10962772 | 3.31469035
845 | 4105 | 3040 | 1481 | 4.10773754 | 3.31468153
906 | 4103 | 3039 | 1481 | 4.10589933 | 3.31447697
966 | 4101 | 3037 | 1481 | 4.10426807 | 3.3145566
1026 | 4098 | 3035 | 1481 | 4.10258102 | 3.31472373
1087 | 4097 | 3034 | 1481 | 4.10090017 | 3.31462717
1147 | 4095 | 3033 | 1481 | 4.09925222 | 3.31459403
1208 | 4094 | 3032 | 1481 | 4.09749413 | 3.31449795
1268 | 4091 | 3030 | 1481 | 4.0959754 | 3.31464505
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

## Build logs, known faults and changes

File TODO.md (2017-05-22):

- Add sensible failsafe configuration

- Separate hardware dependent files so that it is easy to port to other chips
  - How to deal with libopencm3?
  - Support STM32 Nucleo?
  - Support Teensy?

- Add auto-stick calibration function
    - Applies to all analog inputs
    - Triggered when the transmitter is powered on while at least one input
      of type `ANALOG_WITH_CENTER_AUTO_RETURN` or `MOMENTARY_ON_OFF` is
      held away from the center.
    - Needs to beep similar to self-timer on camera, getting faster when a
      timeout expires. Once expires, it measures the center position.
      Only analog inputs with a center are measured
    - When done, beep a different pattern and monitor the values. Record highest
      and lowest values. Make sure we've seen input on all analog channels
      before finishing the procedure, with a different beep.
    - While calibrating, still run the RF(?)

- Center detent: beep when center
  - Applies to `ANALOG_WITH_CENTER` only

- Beep when throttle not 0 at start of transmitter, and refuse operation
  - Find throttle by looking for "TH" and "THR" with analog type that is not `ANALOG_WITH_CENTER_AUTO_RETURN`
  - But still allow configurator to work
  - Can this be an issue when the sticks are not calibrated yet?

- Run-time adaptation to `hardware_inputs` and `logical_inputs` changes

- Test lots of active mixer units, check how long calculation takes

- How to deal with switches and pots that are not present; or a function that was designed for a multi-pos pot but now is a switch?
- How to deal with forward/reverse, when the TX TH is without center detent? dangerous!

- Add version date (based on Git) to firmware

## nRF51 UART bridge

- Send `MAX_PACKETS_IN_TRANSIT` upwards
- Implement a command to query the `MAX_PACKETS_IN_TRANSIT` value for UART purpose, since there is no explicit connection on the UART as there is with websocket or other transports
- Propagate nRF connection lost back via bridges
  - Especially important since the other protocols are considered reliable

## Orange Pi

- Describe hardware
- Full installation documentation
- LED indicator on/connected/transferring data
- Make a default web page to show instead of the nginx one

## Configurator web-app
- Database syncing with bridge, including history

- Use a better app-shell architecture
- Base on web components
  - Polymer? SkateJS? VUE.js?
  - Make ranges (limits, endpoints) not be able to go past each-other
    - Maybe make a custom element that limits upper and lower?

- Add help text
  - How do we get a description of the elements in the configuration?
  - Make help page for logical inputs to explain valid combinations

- Implement passphrase UI

- Live stick/switch/output view
  - Add more elements like normalized ADC values, switch values, etc to live_t.

- Use https://github.com/jakearchibald/indexeddb-promised/blob/master/lib/idb.js
  - Prepare the database for multiple object stores

- The backup JSON file should be human readable, right now it is just binary data wrapped in JSON

- Warning message if left/center/right in reverse order, or handle in SW automatically
- Warning message for configuration that is only applicable after reset, i.e. port settings
- Explain trim (logical inputs)
- What do colors mean when selecting labels on logical inputs?

- Sometimes "connection lost" message is shown when refreshing or going back and forth (too fast)

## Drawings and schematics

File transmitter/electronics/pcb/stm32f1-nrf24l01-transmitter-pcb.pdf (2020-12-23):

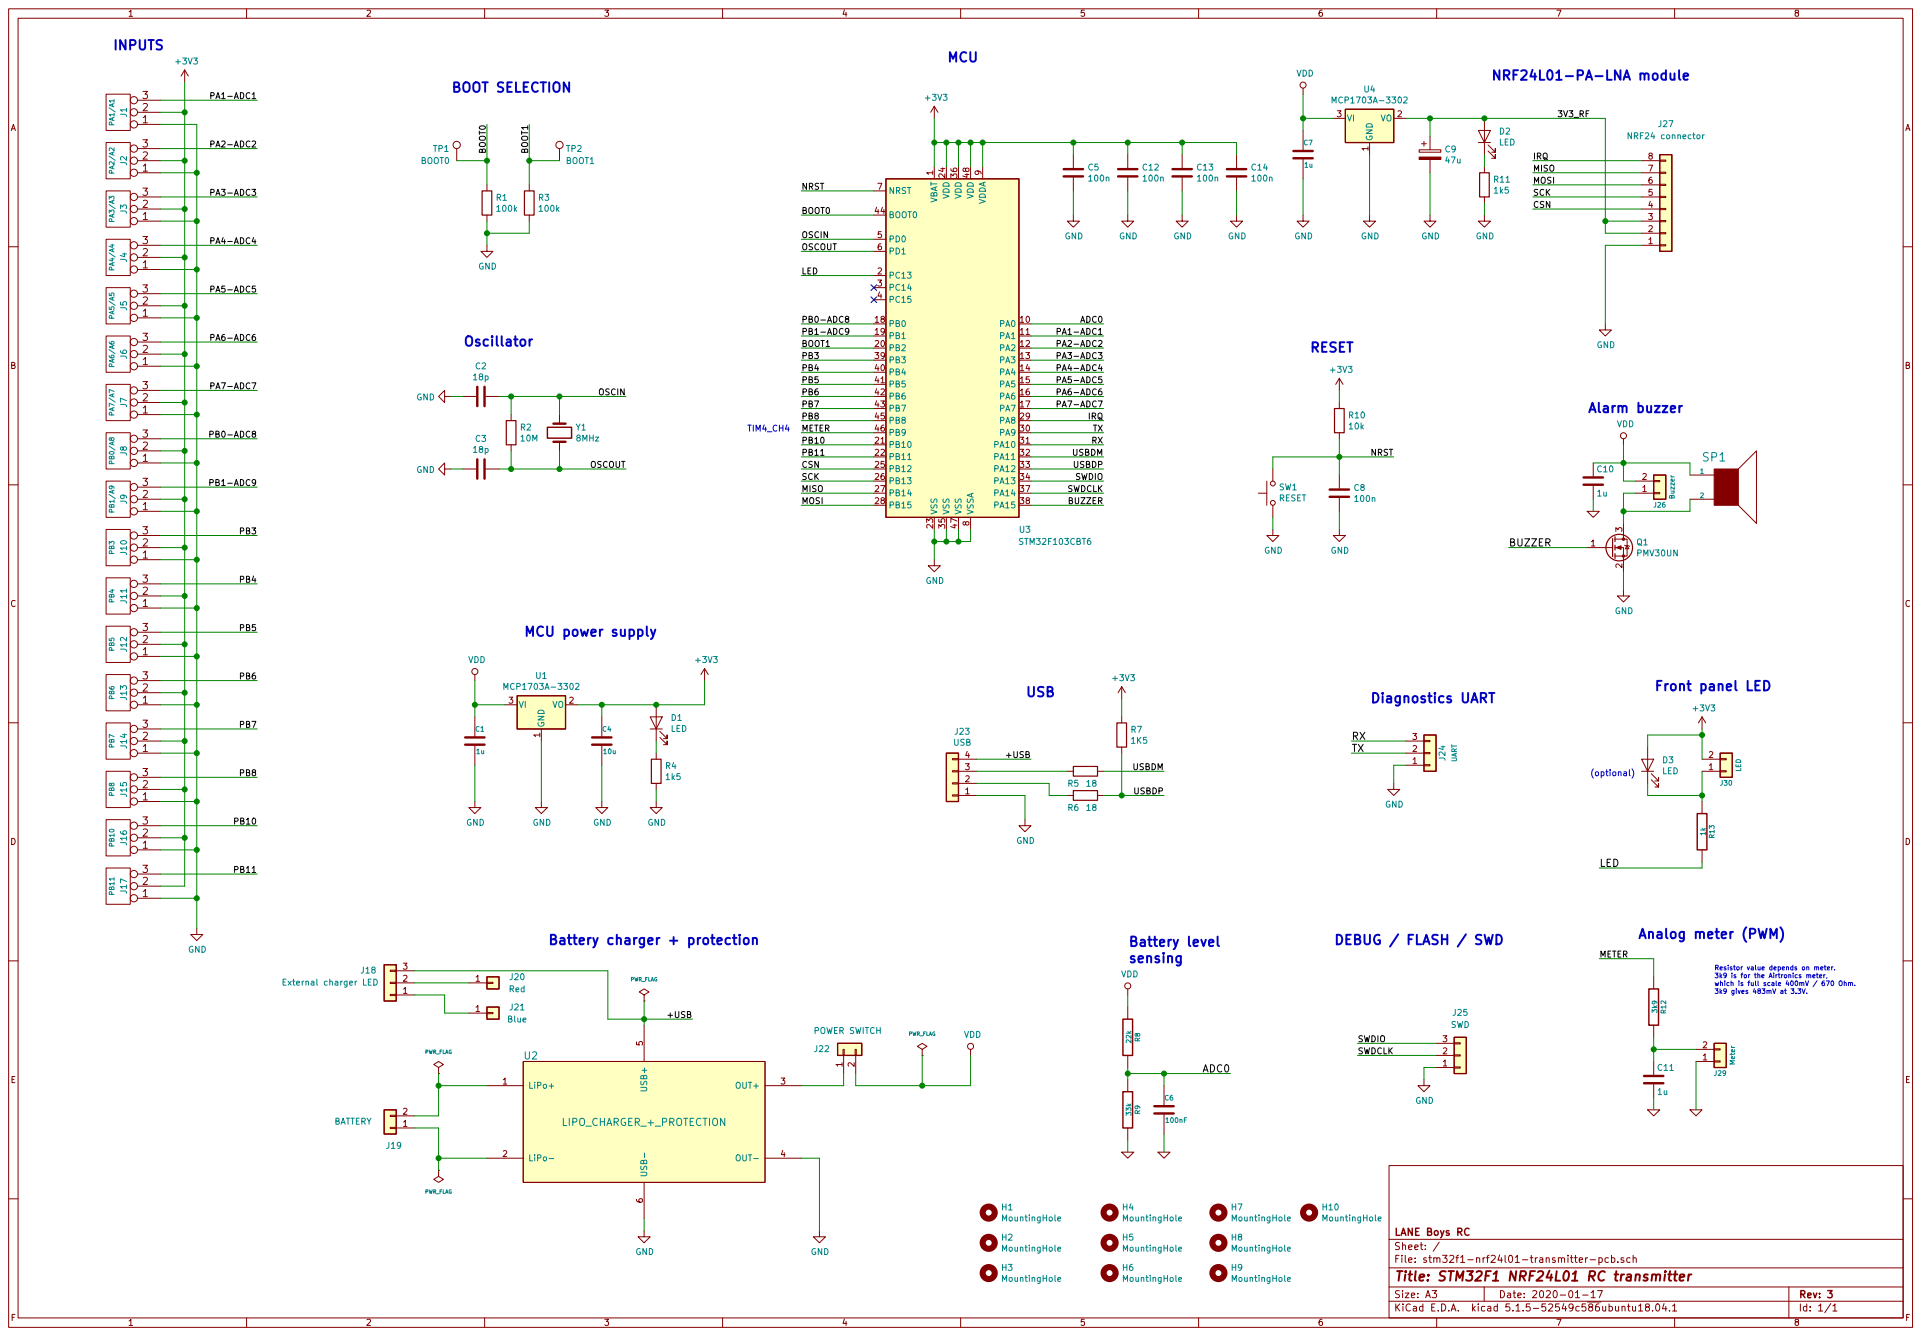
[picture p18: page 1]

1 VO 2 VI 3 U4 MCP1703A-3302 GND GND GNDGND GND GND GND

1 VDD 24 VDD 36 VDD 48 VDDA

9 VSS 23 VSS 35 VSS 47 VSSA

LED
BOOT1 PB1-ADC9 SCK MISO MOSI PB10 PB11 METER

Resistor value depends on meter. 3k9 is for the Airtronics meter, which is full scale 400mV / 670 Ohm. 3k9 gives 483mV at 3.3V. Front panel LED

File: stm32f1-nrf24l01-transmitter-pcb.sch Sheet: / LANE Boys RC

Id: 1/1 Title: STM32F1 NRF24L01 RC transmitter

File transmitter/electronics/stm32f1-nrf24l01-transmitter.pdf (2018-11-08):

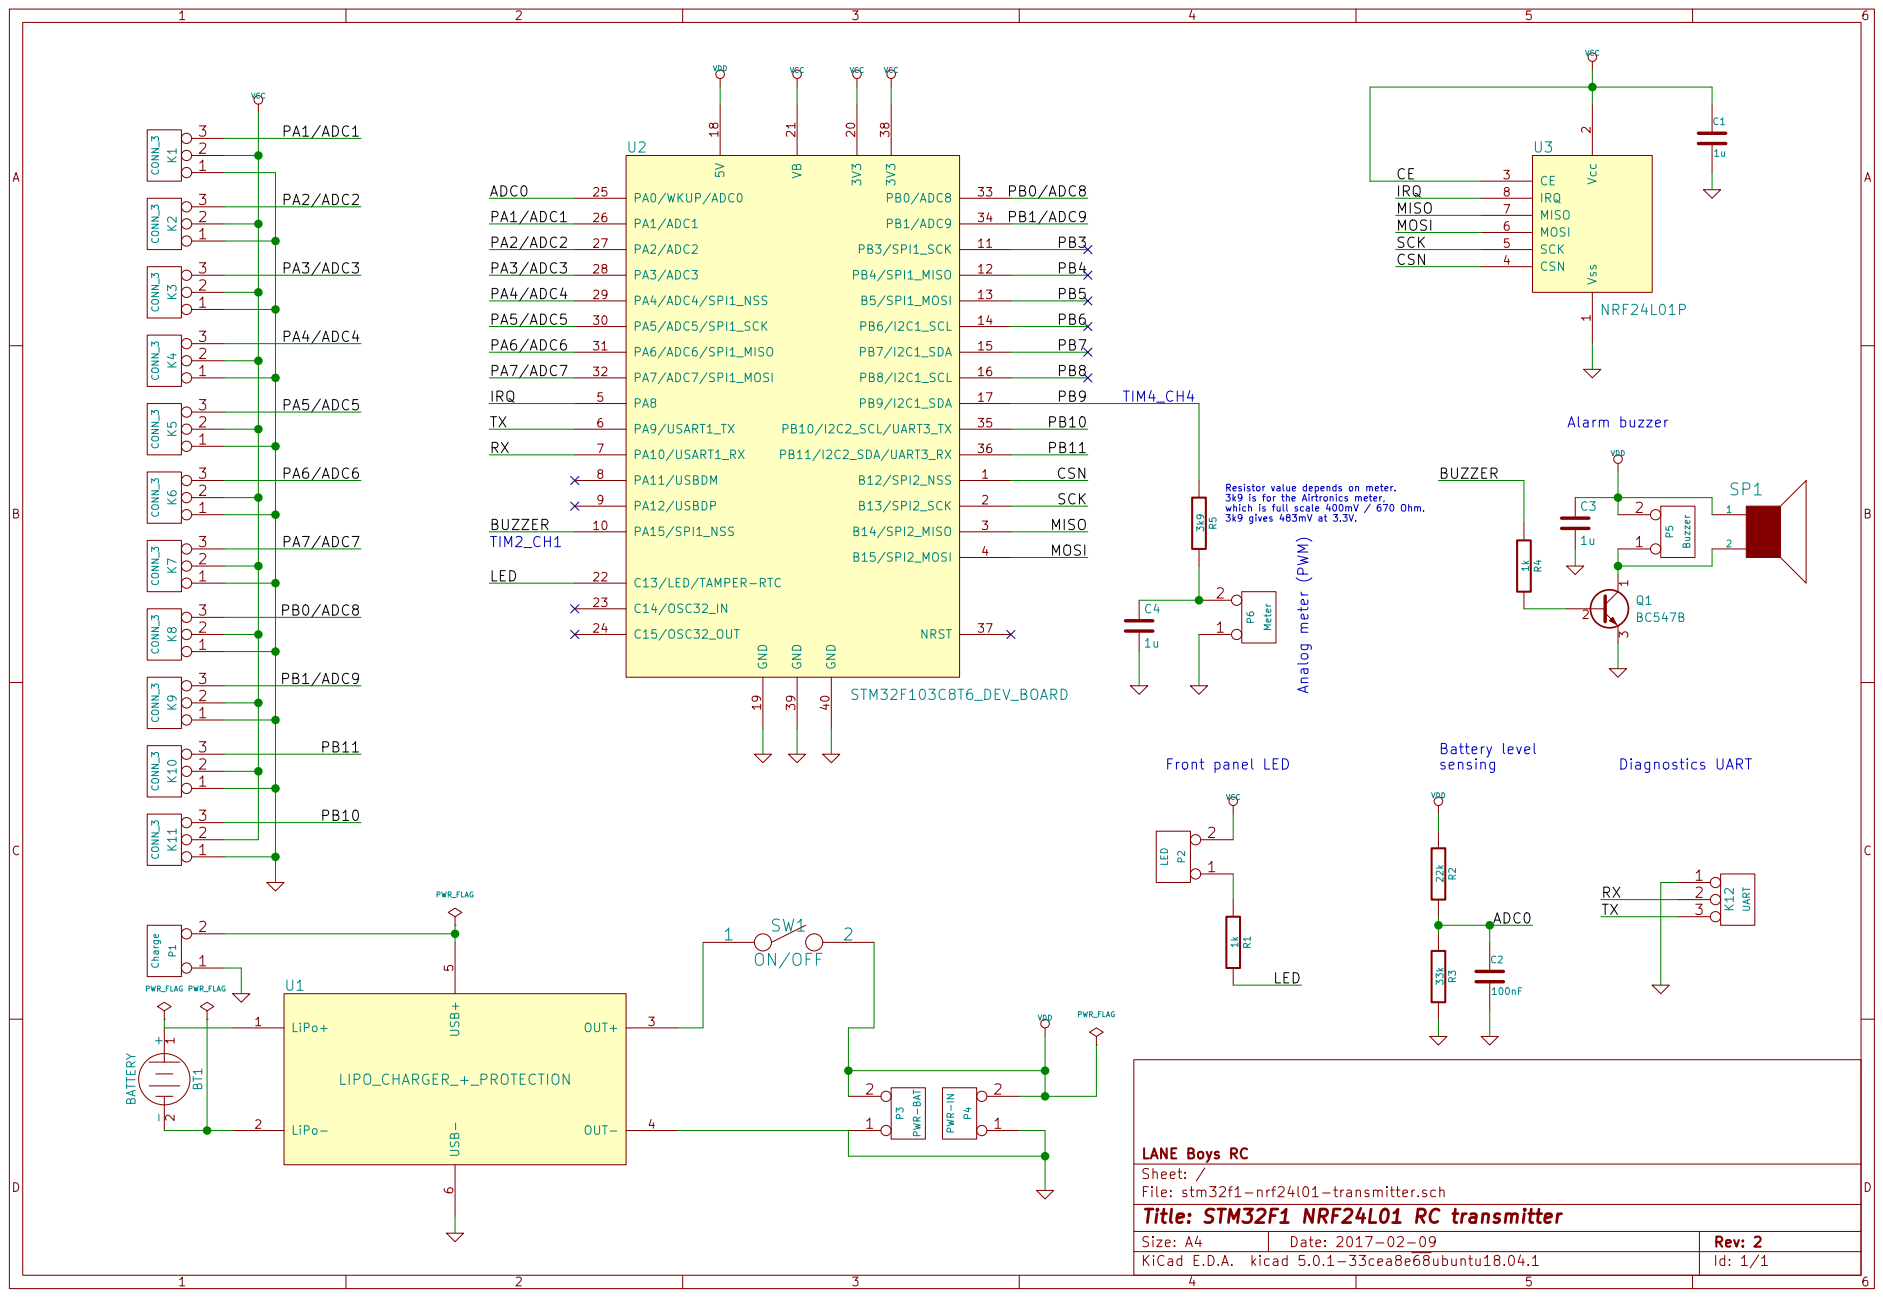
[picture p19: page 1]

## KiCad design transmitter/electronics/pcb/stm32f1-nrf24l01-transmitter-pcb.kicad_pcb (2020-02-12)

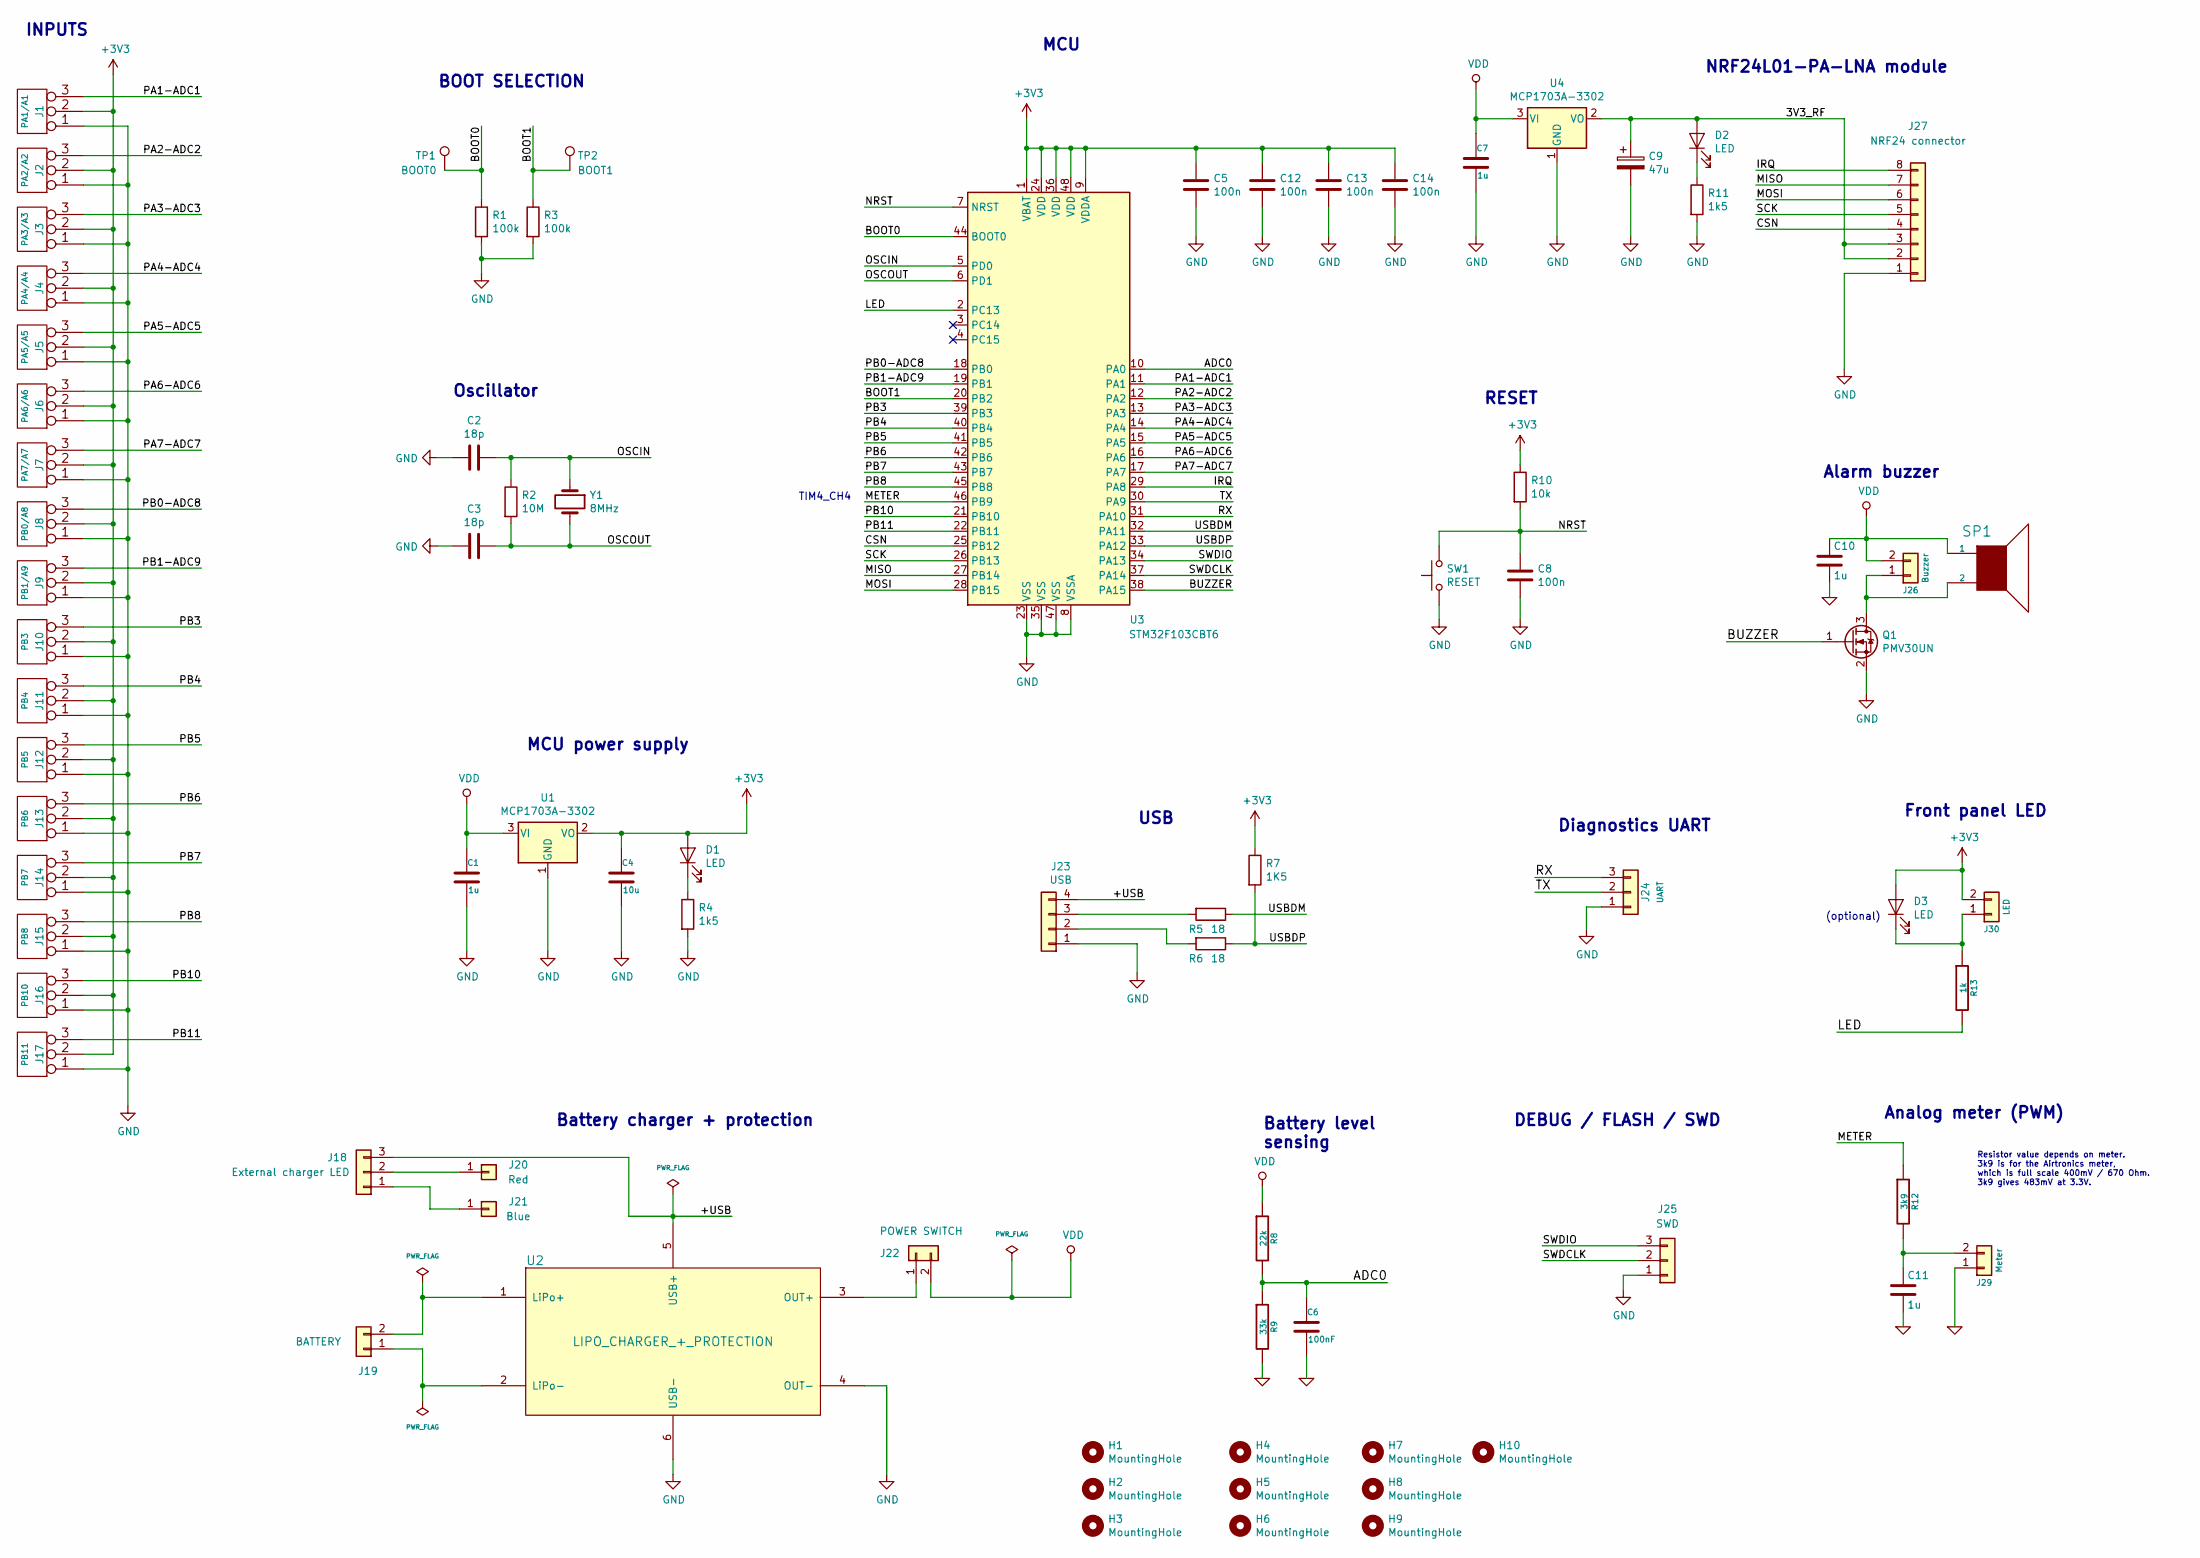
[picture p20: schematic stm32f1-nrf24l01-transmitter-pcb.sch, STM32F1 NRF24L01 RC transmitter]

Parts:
C1, C7, C10, C11: 1u; C_0805_2012Metric_Pad1.15x1.40mm_HandSolder
C2, C3: 18p; C_0603_1608Metric_Pad1.05x0.95mm_HandSolder
C4: 10u; C_0805_2012Metric_Pad1.15x1.40mm_HandSolder
C5, C8, C12, C13, C14: 100n; C_0603_1608Metric_Pad1.05x0.95mm_HandSolder
C6: 100nF; C_0805_2012Metric_Pad1.15x1.40mm_HandSolder
C9: 47u; C_0805_2012Metric_Pad1.15x1.40mm_HandSolder
D1, D2, D3: LED; LED_0805_2012Metric_Pad1.15x1.40mm_HandSolder
H1, H2, H3, H9, H10: MountingHole; MountingHole_3.2mm_M3_DIN965
H4, H5, H6, H7, H8: MountingHole; MountingHole_2.7mm_M2.5_DIN965
J1: PA1/A1; JST_XH_B3B-XH-A_1x03_P2.50mm_Vertical
J2: PA2/A2; JST_XH_B3B-XH-A_1x03_P2.50mm_Vertical
J3: PA3/A3; JST_XH_B3B-XH-A_1x03_P2.50mm_Vertical
J4: PA4/A4; JST_XH_B3B-XH-A_1x03_P2.50mm_Vertical
J5: PA5/A5; JST_XH_B3B-XH-A_1x03_P2.50mm_Vertical
J6: PA6/A6; JST_XH_B3B-XH-A_1x03_P2.50mm_Vertical
J7: PA7/A7; JST_XH_B3B-XH-A_1x03_P2.50mm_Vertical
J8: PB0/A8; JST_XH_B3B-XH-A_1x03_P2.50mm_Vertical
J9: PB1/A9; JST_XH_B3B-XH-A_1x03_P2.50mm_Vertical
J10: PB3; JST_XH_B3B-XH-A_1x03_P2.50mm_Vertical
J11: PB4; JST_XH_B3B-XH-A_1x03_P2.50mm_Vertical
J12: PB5; JST_XH_B3B-XH-A_1x03_P2.50mm_Vertical
J13: PB6; JST_XH_B3B-XH-A_1x03_P2.50mm_Vertical
J14: PB7; JST_XH_B3B-XH-A_1x03_P2.50mm_Vertical
J15: PB8; JST_XH_B3B-XH-A_1x03_P2.50mm_Vertical
J16: PB10; JST_XH_B3B-XH-A_1x03_P2.50mm_Vertical
J17: PB11; JST_XH_B3B-XH-A_1x03_P2.50mm_Vertical
J18: External charger LED; JST_XH_B3B-XH-A_1x03_P2.50mm_Vertical
J19: BATTERY; JST_XH_B2B-XH-A_1x02_P2.50mm_Vertical
J20: Red; TestPoint_Pad_1.5x1.5mm
J21: Blue; TestPoint_Pad_1.5x1.5mm
J22: POWER SWITCH; JST_XH_B2B-XH-A_1x02_P2.50mm_Vertical
J23: USB; JST_XH_B4B-XH-A_1x04_P2.50mm_Vertical
J24: UART; PinHeader_1x03_P2.54mm_Vertical
J25: SWD; PinHeader_1x03_P2.54mm_Vertical
J26: Buzzer; JST_XH_B2B-XH-A_1x02_P2.50mm_Vertical
J27: NRF24 connector; JST_XH_B8B-XH-A_1x08_P2.50mm_Vertical
J29: Meter; JST_XH_B2B-XH-A_1x02_P2.50mm_Vertical
J30: LED; JST_XH_B2B-XH-A_1x02_P2.50mm_Vertical
Q1: PMV30UN; SOT-23_Handsoldering
R1, R3: 100k; R_0805_2012Metric_Pad1.15x1.40mm_HandSolder
R2: 10M; R_0805_2012Metric_Pad1.15x1.40mm_HandSolder
R4, R11: 1k5; R_0805_2012Metric_Pad1.15x1.40mm_HandSolder
R5, R6: 18; R_0805_2012Metric_Pad1.15x1.40mm_HandSolder
R7: 1K5; R_0805_2012Metric_Pad1.15x1.40mm_HandSolder
R8: 22k; R_0805_2012Metric_Pad1.15x1.40mm_HandSolder
R9: 33k; R_0805_2012Metric_Pad1.15x1.40mm_HandSolder
R10: 10k; R_0805_2012Metric_Pad1.15x1.40mm_HandSolder
R12: 3k9; R_0805_2012Metric_Pad1.15x1.40mm_HandSolder
R13: 1k; R_0805_2012Metric_Pad1.15x1.40mm_HandSolder
SP1: SPEAKER; MagneticBuzzer_PUI_AT-0927-TT-6-R
SW1: RESET; Tact switch 6x4x3
TP1: BOOT0; TestPoint_Pad_1.5x1.5mm
TP2: BOOT1; TestPoint_Pad_1.5x1.5mm
U1, U4: MCP1703A-3302; SOT-23_Handsoldering
U2: LIPO_CHARGER_+_PROTECTION; LiPo_charger_and_protection
U3: STM32F103CBT6; LQFP-48_7x7mm_P0.5mm
Y1: 8MHz; Crystal_SMD_5032-2Pin_5.0x3.2mm

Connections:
+3V3: C4.1, C5.1, C12.1, C13.1, C14.1, D1.2 (A), D3.2 (A), J1.2 (PM), J2.2 (PM), J3.2 (PM), J4.2 (PM), J5.2 (PM), J6.2 (PM), J7.2 (PM), J8.2 (PM), J9.2 (PM), J10.2 (PM), J11.2 (PM), J12.2 (PM), J13.2 (PM), J14.2 (PM), J15.2 (PM), J16.2 (PM), J17.2 (PM), J30.2, R7.1, R10.1, U1.2 (VO), U3.1 (VBAT), U3.9 (VDDA), U3.24 (VDD), U3.36 (VDD), U3.48 (VDD)
/3V3_RF: C9.1, D2.2 (A), J27.2, J27.3, U4.2 (VO)
/+USB: J18.3, J23.4, U2.5 (USB+)
/ADC0: C6.1, R8.2, R9.1, U3.10 (PA0)
/BOOT0: R1.1, TP1.1, U3.44 (BOOT0)
/BOOT1: R3.1, TP2.1, U3.20 (PB2)
/BUZZER: Q1.1 (G), U3.38 (PA15)
/CSN: J27.4, U3.25 (PB12)
/IRQ: J27.8, U3.29 (PA8)
/LED: R13.2, U3.2 (PC13)
/METER: R12.1, U3.46 (PB9)
/MISO: J27.7, U3.27 (PB14)
/MOSI: J27.6, U3.28 (PB15)
/NRST: C8.1, R10.2, SW1.2, U3.7 (NRST)
/OSCIN: C2.1, R2.1, U3.5 (PD0), Y1.1
/OSCOUT: C3.1, R2.2, U3.6 (PD1), Y1.2
/PA1-ADC1: J1.3, U3.11 (PA1)
/PA2-ADC2: J2.3, U3.12 (PA2)
/PA3-ADC3: J3.3, U3.13 (PA3)
/PA4-ADC4: J4.3, U3.14 (PA4)
/PA5-ADC5: J5.3, U3.15 (PA5)
/PA6-ADC6: J6.3, U3.16 (PA6)
/PA7-ADC7: J7.3, U3.17 (PA7)
/PB0-ADC8: J8.3, U3.18 (PB0)
/PB1-ADC9: J9.3, U3.19 (PB1)
/PB3: J10.3, U3.39 (PB3)
/PB4: J11.3, U3.40 (PB4)
/PB5: J12.3, U3.41 (PB5)
/PB6: J13.3, U3.42 (PB6)
/PB7: J14.3, U3.43 (PB7)
/PB8: J15.3, U3.45 (PB8)
/PB10: J16.3, U3.21 (PB10)
/PB11: J17.3, U3.22 (PB11)
/RX: J24.3, U3.31 (PA10)
/SCK: J27.5, U3.26 (PB13)
/SWDCLK: J25.2, U3.37 (PA14)
/SWDIO: J25.3, U3.34 (PA13)
/TX: J24.2, U3.30 (PA9)
/USBDM: R5.1, U3.32 (PA11)
/USBDP: R6.1, R7.2, U3.33 (PA12)
GND: C1.2, C2.2, C3.2, C4.2, C5.2, C6.2, C7.2, C8.2, C9.2, C10.2, C11.2, C12.2, C13.2, C14.2, J1.1, J2.1, J3.1, J4.1, J5.1, J6.1, J7.1, J8.1, J9.1, J10.1, J11.1, J12.1, J13.1, J14.1, J15.1, J16.1, J17.1, J23.1, J24.1, J25.1, J27.1, J29.1, Q1.2 (S), R1.2, R3.2, R4.2, R9.2, R11.2, SW1.1, U1.1 (GND), U2.4 (OUT-), U2.6 (USB-), U3.8 (VSSA), U3.23 (VSS), U3.35 (VSS), U3.47 (VSS), U4.1 (GND)
unnamed: C11.1, J29.2, R12.2
unnamed: D1.1 (K), R4.1
unnamed: D2.1 (K), R11.1
unnamed: D3.1 (K), J30.1, R13.1
unnamed: J18.1, J21.1
unnamed: J18.2, J20.1
unnamed: J19.1, U2.2 (LiPo-)
unnamed: J19.2, U2.1 (LiPo+)
unnamed: J22.1, U2.3 (OUT+)
unnamed: J23.2, R6.2
unnamed: J23.3, R5.2
unnamed: J26.1, Q1.3 (D), SP1.2
VDD: C1.1, C7.1, C10.1, J22.2, J26.2, R8.1, SP1.1, U1.3 (VI), U4.3 (VI)

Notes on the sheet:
Diagnostics UART
Front panel LED
Alarm buzzer
Analog meter (PWM)
Resistor value depends on meter. 3k9 is for the Airtronics meter, which is full scale 400mV / 670 Ohm. 3k9 gives 483mV at 3.3V.
USB
Battery level sensing
TIM4_CH4
(optional)
BOOT SELECTION
INPUTS
MCU
NRF24L01-PA-LNA module
MCU power supply
Battery charger + protection
Oscillator
RESET
DEBUG / FLASH / SWD

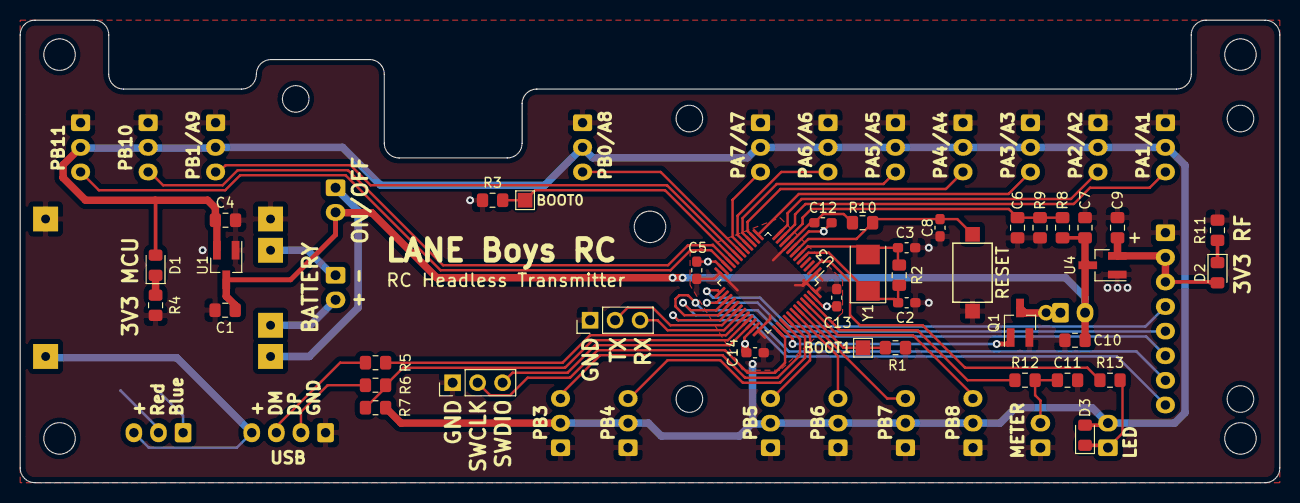
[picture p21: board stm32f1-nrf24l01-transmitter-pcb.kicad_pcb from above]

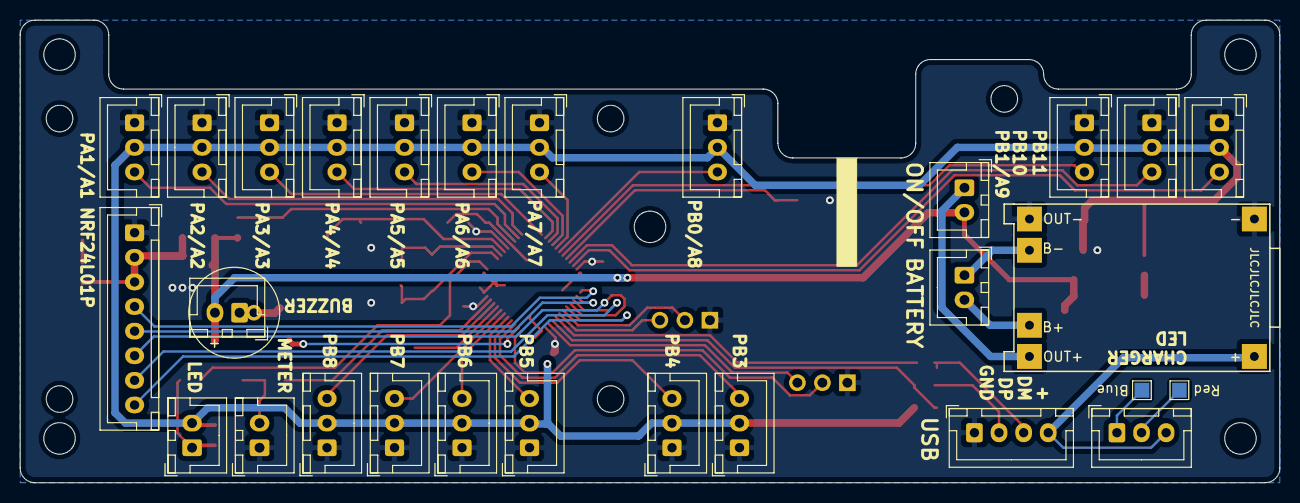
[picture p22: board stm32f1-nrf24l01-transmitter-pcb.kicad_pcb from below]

Board: 2 copper layers, 128.0 x 47.0 mm, 79 parts (29 on the bottom side), 54 nets.

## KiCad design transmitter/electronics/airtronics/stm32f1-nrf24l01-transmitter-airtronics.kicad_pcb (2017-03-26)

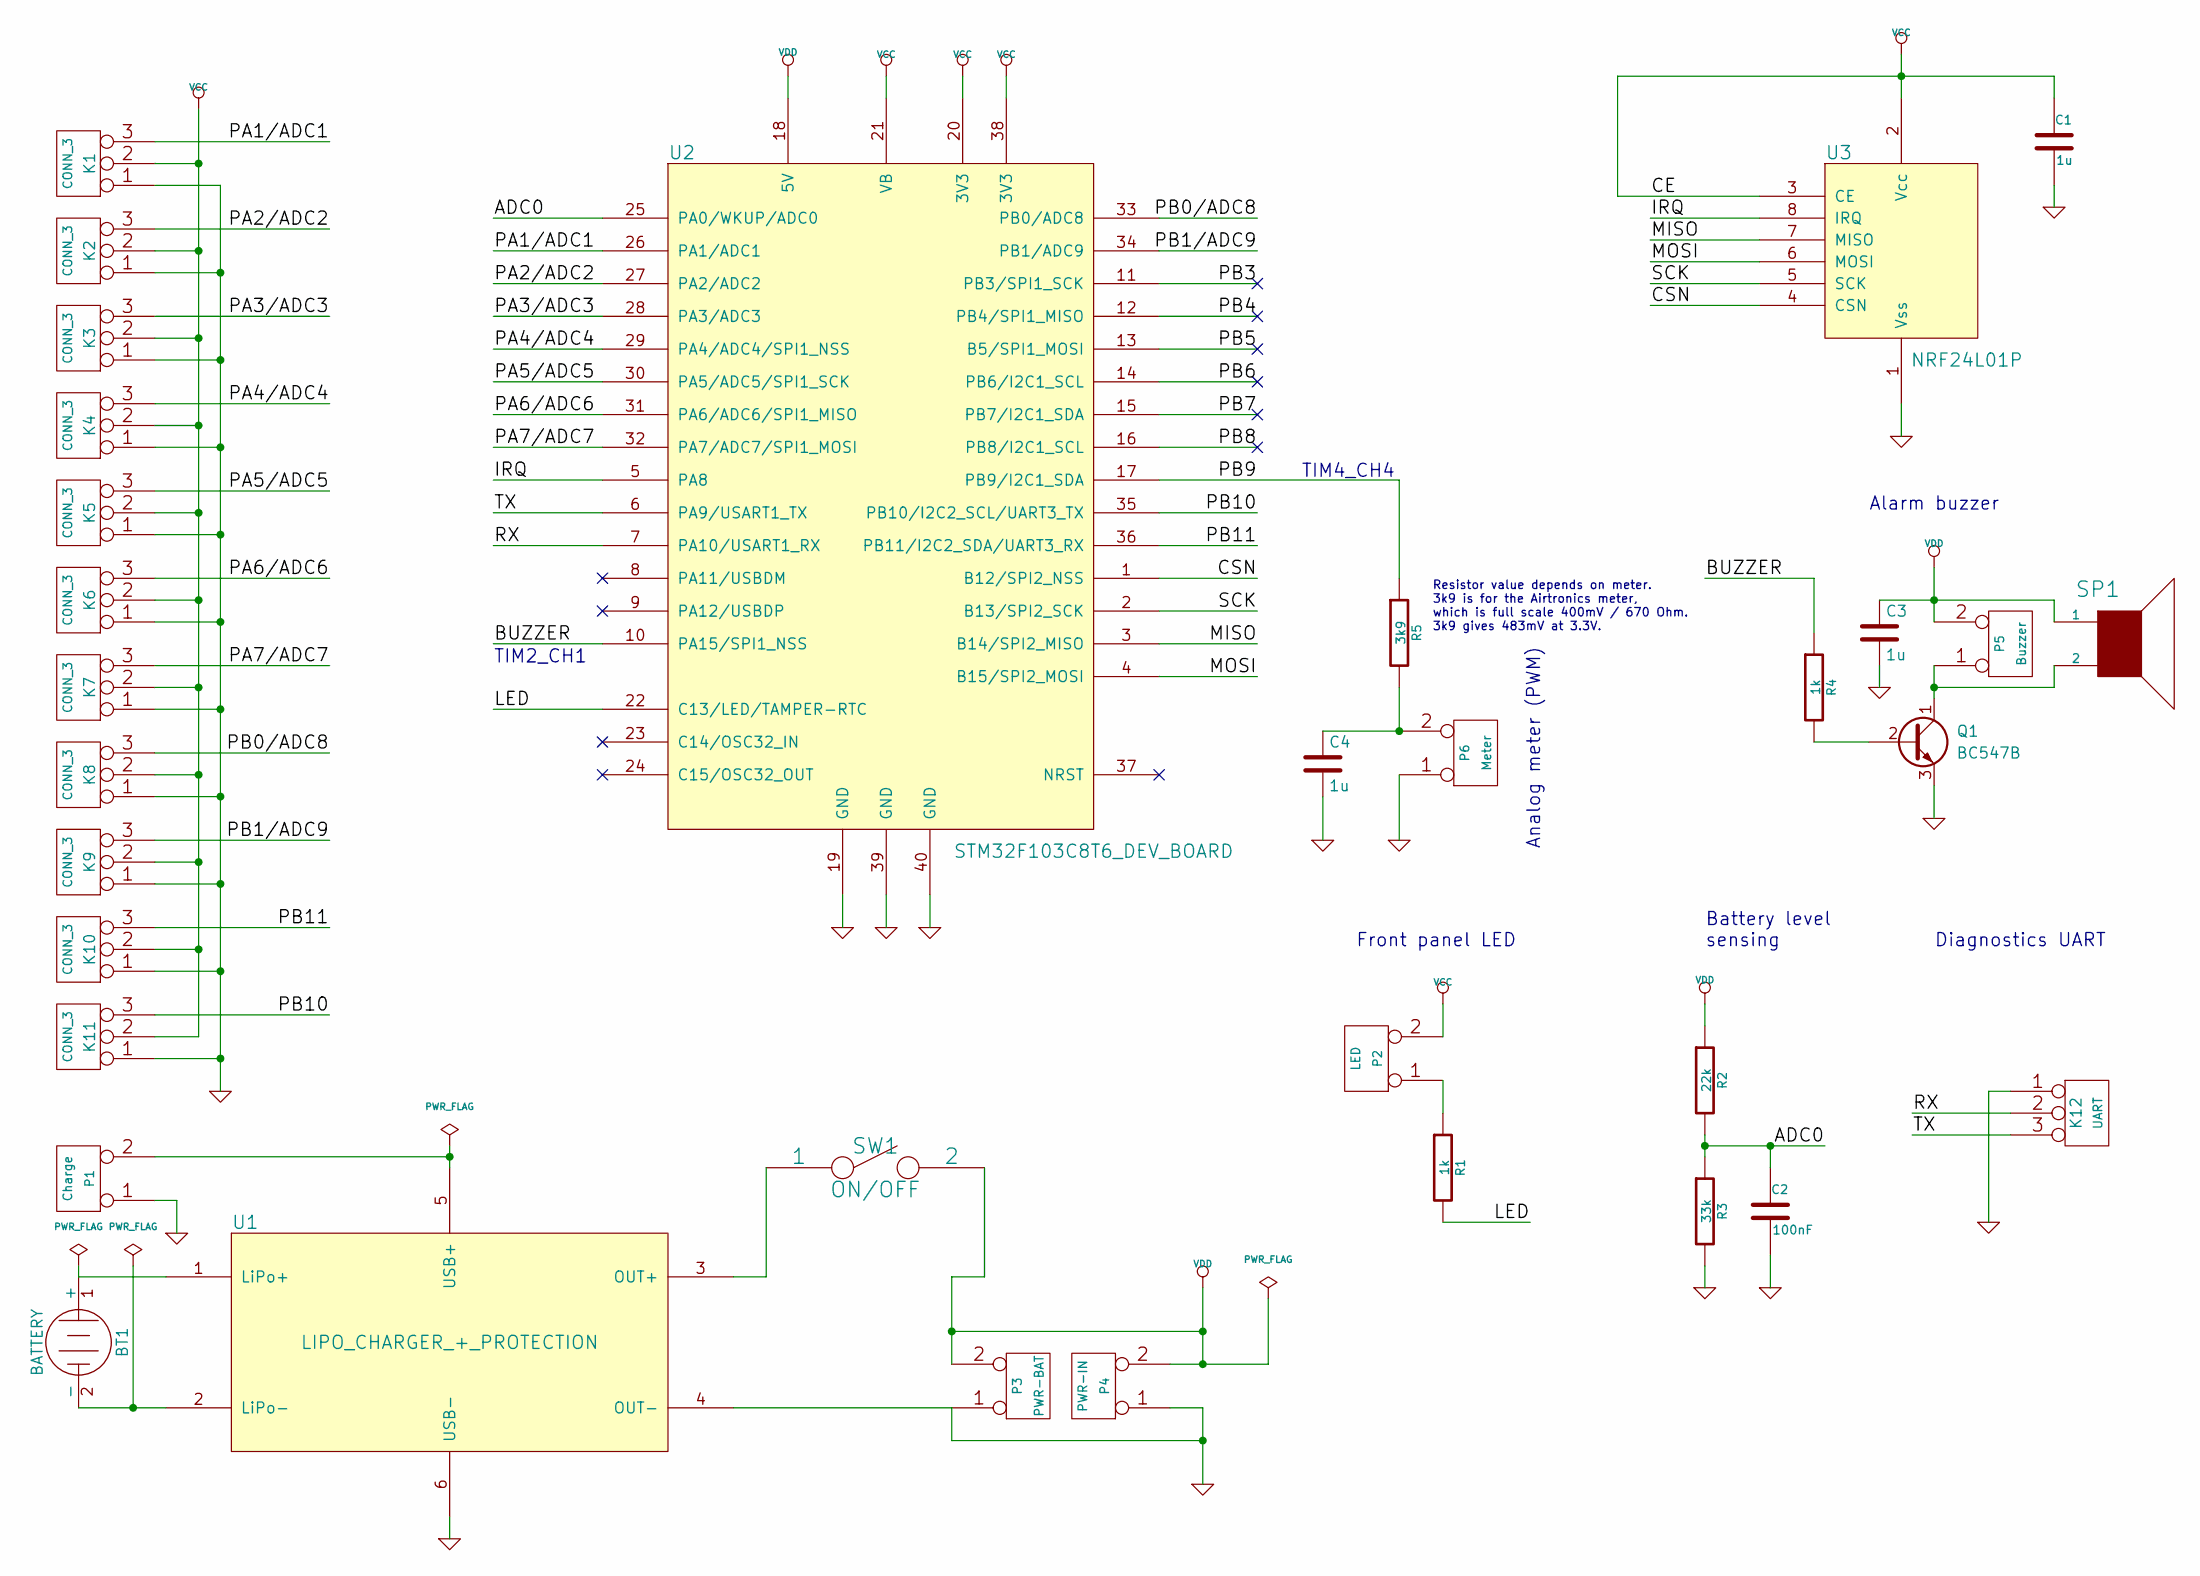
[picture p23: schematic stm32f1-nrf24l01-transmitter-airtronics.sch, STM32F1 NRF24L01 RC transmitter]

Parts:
BT1: BATTERY; Pin_Header_Straight_1x02_Pitch2.54mm
C1, C3, C4: 1u; C_0805_HandSoldering
C2: 100nF; C_0805_HandSoldering
K1, K2, K3, K4, K5, K6, K7, K8, K9, K10, K11: CONN_3; Pin_Header_Straight_1x03_Pitch2.54mm
K12: UART; Pin_Header_Straight_1x03_Pitch2.54mm
P1: Charge; Pin_Header_Straight_1x02_Pitch2.54mm
P2: LED; Pin_Header_Straight_1x02_Pitch2.54mm
P3: PWR-BAT; Pin_Header_Straight_1x02_Pitch2.54mm
P4: PWR-IN; Pin_Header_Straight_1x02_Pitch2.54mm
P5: Buzzer; Pin_Header_Straight_1x02_Pitch2.54mm
P6: Meter; Pin_Header_Straight_1x02_Pitch2.54mm
Q1: BC547B; TO-92_Inline_Wide
R1, R4: 1k; R_0805_HandSoldering
R2: 22k; R_0805_HandSoldering
R3: 33k; R_0805_HandSoldering
R5: 3k9; R_0805_HandSoldering
SP1: SPEAKER; Buzzer_12x9.5RM7.6
SW1: ON/OFF; SW_SPST_FSMSM
U1: LIPO_CHARGER_+_PROTECTION; LiPo_charger_and_protection
U2: STM32F103C8T6_DEV_BOARD; STM32F103C8T6
U3: NRF24L01P; NRF24L01P-PA-LNA

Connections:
/ADC0: C2.1, R2.2, R3.1, U2.25 (PA0/WKUP/ADC0)
/BUZZER: R4.1, U2.10 (PA15/SPI1_NSS)
/CSN: U2.1 (B12/SPI2_NSS), U3.4 (CSN)
/IRQ: U2.5 (PA8), U3.8 (IRQ)
/LED: R1.2, U2.22 (C13/LED/TAMPER-RTC)
/MISO: U2.3 (B14/SPI2_MISO), U3.7 (MISO)
/MOSI: U2.4 (B15/SPI2_MOSI), U3.6 (MOSI)
/PA1/ADC1: K1.3, U2.26 (PA1/ADC1)
/PA2/ADC2: K2.3, U2.27 (PA2/ADC2)
/PA3/ADC3: K3.3, U2.28 (PA3/ADC3)
/PA4/ADC4: K4.3, U2.29 (PA4/ADC4/SPI1_NSS)
/PA5/ADC5: K5.3, U2.30 (PA5/ADC5/SPI1_SCK)
/PA6/ADC6: K6.3, U2.31 (PA6/ADC6/SPI1_MISO)
/PA7/ADC7: K7.3, U2.32 (PA7/ADC7/SPI1_MOSI)
/PB0/ADC8: K8.3, U2.33 (PB0/ADC8)
/PB1/ADC9: K9.3, U2.34 (PB1/ADC9)
/PB3: U2.11 (PB3/SPI1_SCK)
/PB4: U2.12 (PB4/SPI1_MISO)
/PB5: U2.13 (B5/SPI1_MOSI)
/PB6: U2.14 (PB6/I2C1_SCL)
/PB7: U2.15 (PB7/I2C1_SDA)
/PB8: U2.16 (PB8/I2C1_SCL)
/PB9: R5.1, U2.17 (PB9/I2C1_SDA)
/PB10: K11.3, U2.35 (PB10/I2C2_SCL/UART3_TX)
/PB11: K10.3, U2.36 (PB11/I2C2_SDA/UART3_RX)
/RX: K12.2 (PM), U2.7 (PA10/USART1_RX)
/SCK: U2.2 (B13/SPI2_SCK), U3.5 (SCK)
/TX: K12.3, U2.6 (PA9/USART1_TX)
GND: C1.2, C2.2, C3.2, C4.2, K1.1, K2.1, K3.1, K4.1, K5.1, K6.1, K7.1, K8.1, K9.1, K10.1, K11.1, K12.1, P1.1, P3.1, P4.1, P6.1, Q1.3 (E), R3.2, U1.4 (OUT-), U1.6 (USB-), U2.19 (GND), U2.39 (GND), U2.40 (GND), U3.1 (Vss)
unnamed: BT1.1 (+), U1.1 (LiPo+)
unnamed: BT1.2 (-), U1.2 (LiPo-)
unnamed: C4.1, P6.2 (PM), R5.2
unnamed: P1.2 (PM), U1.5 (USB+)
unnamed: P2.1, R1.1
unnamed: P5.1, Q1.1 (C), SP1.2
unnamed: Q1.2 (B), R4.2
unnamed: SW1.1, U1.3 (OUT+)
VCC: C1.1, K1.2 (PM), K2.2 (PM), K3.2 (PM), K4.2 (PM), K5.2 (PM), K6.2 (PM), K7.2 (PM), K8.2 (PM), K9.2 (PM), K10.2 (PM), K11.2 (PM), P2.2 (PM), U2.20 (3V3), U2.21 (VB), U2.38 (3V3), U3.2 (Vcc), U3.3 (CE)
VDD: C3.1, P3.2 (PM), P4.2 (PM), P5.2 (PM), R2.1, SP1.1, SW1.2, U2.18 (5V)

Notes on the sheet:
Battery level sensing
Diagnostics UART
Front panel LED
Alarm buzzer
TIM2_CH1
Analog meter (PWM)
Resistor value depends on meter. 3k9 is for the Airtronics meter, which is full scale 400mV / 670 Ohm. 3k9 gives 483mV at 3.3V.
TIM4_CH4

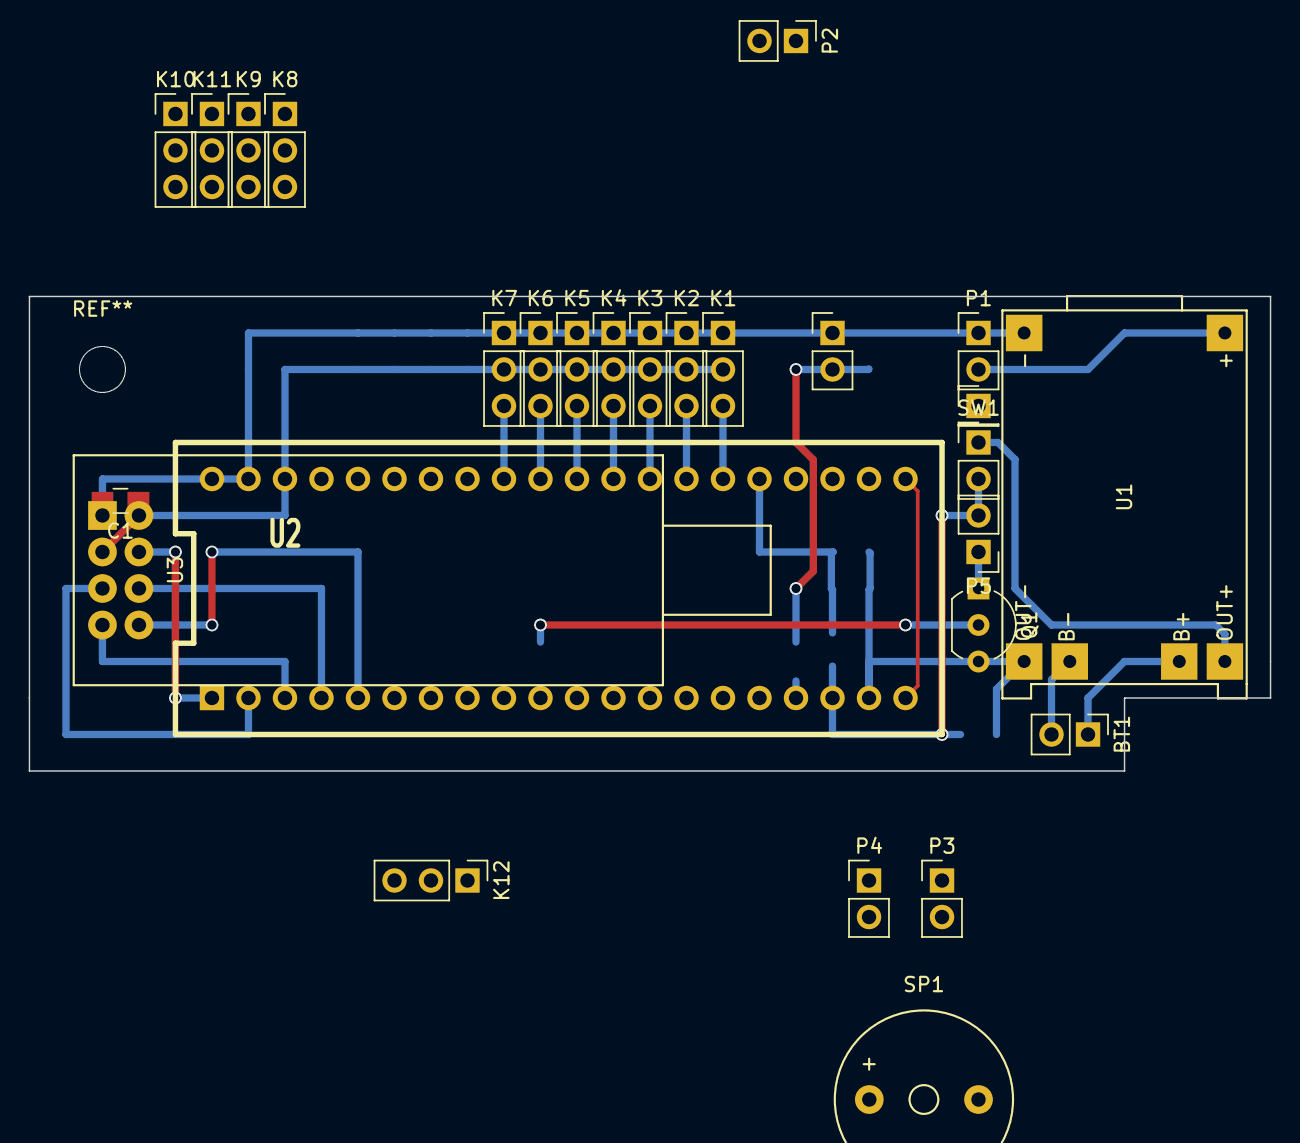
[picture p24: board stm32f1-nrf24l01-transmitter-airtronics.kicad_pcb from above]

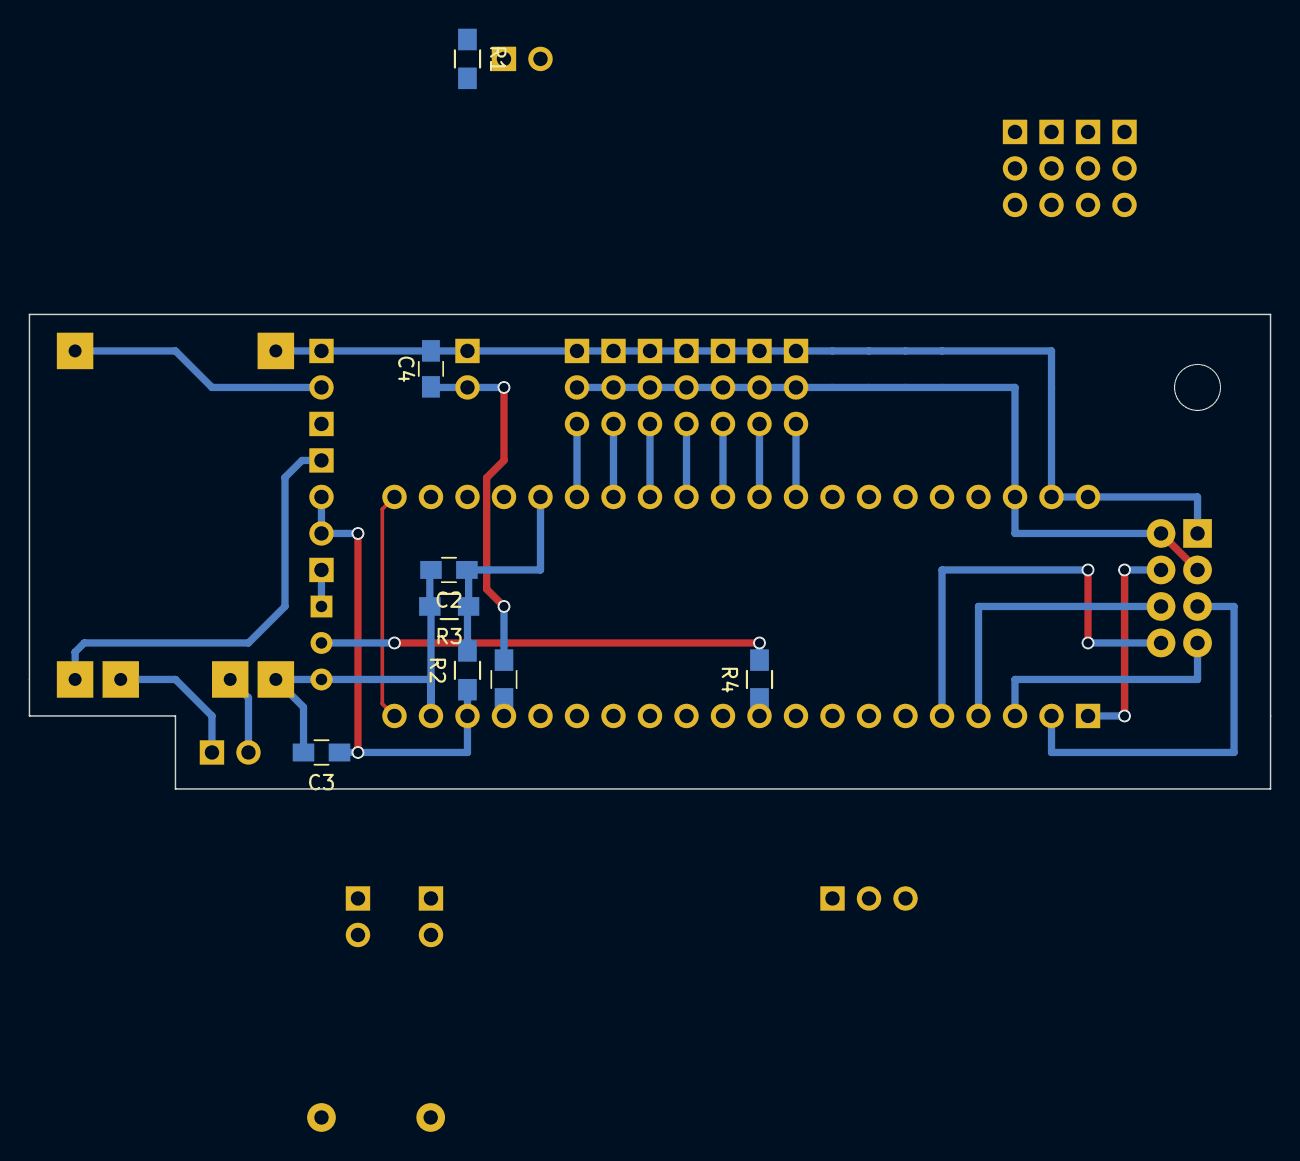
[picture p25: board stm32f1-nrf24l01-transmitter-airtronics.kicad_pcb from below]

Board: 2 copper layers, 86.4 x 33.0 mm, 34 parts (8 on the bottom side), 33 nets.

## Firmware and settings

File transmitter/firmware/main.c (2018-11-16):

#include <stdint.h>
#include <stdio.h>
#include <string.h>

#include <libopencm3/stm32/flash.h>
#include <libopencm3/stm32/gpio.h>
#include <libopencm3/stm32/rcc.h>
#include <libopencm3/stm32/timer.h>
#include <libopencmsis/core_cm3.h>

#include <battery.h>
#include <config.h>
#include <configurator.h>
#include <inputs.h>
#include <led.h>
#include <meter.h>
#include <mixer.h>
#include <music.h>
#include <nrf24l01p.h>
#include <persistent_storage.h>
#include <sound.h>
#include <spi.h>
#include <systick.h>
#include <uart.h>
#include <watchdog.h>
#include <webusb.h>

#include <protocol_hk310.h>
#include <protocol_laneboysrc4ch.h>
#include <protocol_laneboysrc8ch.h>

typedef struct {
    void (*init_function)(void);
    void (*enable_binding_function)(void);
    void (*disable_binding_function)(void);
} rf_protocol_handlers_t;

static rf_protocol_handlers_t current_rf_protocol;

static const rf_protocol_handlers_t rf_protocol_handlers[] = {
    {
        .init_function = PROTOCOL_HK310_init,
        .enable_binding_function = PROTOCOL_HK310_enable_binding,
        .disable_binding_function = PROTOCOL_HK310_disable_binding,
    },
    {
        .init_function = PROTOCOL_LANEBOYSRC4CH_init,
        .enable_binding_function = PROTOCOL_LANEBOYSRC4CH_enable_binding,
        .disable_binding_function = PROTOCOL_LANEBOYSRC4CH_disable_binding,
    },
    {
        .init_function = PROTOCOL_LANEBOYSRC8CH_init,
        .enable_binding_function = PROTOCOL_LANEBOYSRC8CH_enable_binding,
        .disable_binding_function = PROTOCOL_LANEBOYSRC8CH_disable_binding,
    },
};


// ****************************************************************************
void nmi_handler(void) {
    // The NMI is triggered by the Clock Security System. We clear the CSS
    // interrupt and switch back to the internal RC oscillator

    rcc_css_int_clear();
    rcc_clock_setup_in_hsi_out_24mhz();
    SOUND_play(220, 1000, NULL);
}


// ****************************************************************************
static void clock_setup_in_hse_8mhz_out_48mhz(void)
{
    // Enable internal high-speed oscillator
    rcc_osc_on(RCC_HSI);
    rcc_wait_for_osc_ready(RCC_HSI);

    // Select HSI as SYSCLK source for now
    rcc_set_sysclk_source(RCC_CFGR_SW_SYSCLKSEL_HSICLK);

    // Enable external high-speed oscillator, running at 8MHz
    rcc_osc_on(RCC_HSE);
    rcc_wait_for_osc_ready(RCC_HSE);

    // We configure the PLL as system clock source, using the 8 MHz crystal
    // on the blue pill board, running at 48 MHz (multiply by 6).
    // We divide the system clock by 2 to get a 24 MHz AHB clock.
    // The APB1 and APB2 clock are also set to 24 MHz (no divider).
    // USB runs from the PLL at 48 MHz.
    // The ADC runs at APB2 clock divide by 2 => 12 MHz.
    rcc_set_hpre(RCC_CFGR_HPRE_SYSCLK_DIV2);        // 24MHz (max 72MHz)
    rcc_set_ppre1(RCC_CFGR_PPRE1_HCLK_NODIV);       // 24MHz (max 36MHz)
    rcc_set_ppre2(RCC_CFGR_PPRE2_HCLK_NODIV);       // 24MHz (max 72MHz)
    rcc_set_adcpre(RCC_CFGR_ADCPRE_PCLK2_DIV2);     // 12MHz (max 14MHz)
    rcc_set_usbpre(RCC_CFGR_USBPRE_PLL_CLK_NODIV);  // 48MHz

    // Sysclk runs with 48 MHz, so we need 1 waitstate.
    flash_set_ws(FLASH_ACR_LATENCY_1WS);

    // Set the PLL multiplication factor to 6.
    // 8MHz (external) * 6 (multiplier) = 48MHz
    rcc_set_pll_multiplication_factor(RCC_CFGR_PLLMUL_PLL_CLK_MUL6);

    // Select HSE as PLL source
    rcc_set_pll_source(RCC_CFGR_PLLSRC_HSE_CLK);

    // External frequency undivided before entering PLL (only valid/needed for HSE)
    rcc_set_pllxtpre(RCC_CFGR_PLLXTPRE_HSE_CLK);

    // Enable PLL oscillator and wait for it to stabilize
    rcc_osc_on(RCC_PLL);
    rcc_wait_for_osc_ready(RCC_PLL);

    // Select PLL as SYSCLK source
    rcc_set_sysclk_source(RCC_CFGR_SW_SYSCLKSEL_PLLCLK);

    // Set the peripheral clock frequencies used
    rcc_ahb_frequency = 24000000;
    rcc_apb1_frequency = 24000000;
    rcc_apb2_frequency = 24000000;
}


// ****************************************************************************
static void clock_init(void)
{
    // Enable the Clock Security System
    // rcc_css_enable();

    // NOTE: the transmitter will not boot when the crystal is not working as
    // there is no timeout waiting for the HSE in rcc_clock_setup_in_hse_8mhz_out_24mhz().
    // rcc_clock_setup_in_hse_8mhz_out_24mhz();
    // rcc_clock_setup_in_hsi_out_48mhz();
    clock_setup_in_hse_8mhz_out_48mhz();

    // Enable clocks for GPIO port A (for GPIO_USART1_TX) and C (LED)
    // IMPORTANT: you can not 'or' them into one call due to bit-mangling
    rcc_periph_clock_enable(RCC_GPIOA);
    rcc_periph_clock_enable(RCC_GPIOB);
    rcc_periph_clock_enable(RCC_GPIOC);
    rcc_periph_clock_enable(RCC_AFIO);
}


// ****************************************************************************
static void disable_binding(void)
{
    if (current_rf_protocol.disable_binding_function) {
        current_rf_protocol.disable_binding_function();
        MUSIC_play(&song_deactivate);
    }
}


// ****************************************************************************
int main(void)
{
    uint32_t last_battery_check_ms = 0;
    uint32_t last_invalid_config_ms = 0;

    clock_init();
    LED_init();
    SYSTICK_init();
    UART_init();
    SPI_init();
    SOUND_init();
    METER_init();
    NRF24_init();
    WATCHDOG_start();

    PERSISTENT_STORAGE_init();
    CONFIG_init();

    INPUTS_init();
    MIXER_init();
    CONFIGURATOR_init();
    WEBUSB_init();

    memcpy(&current_rf_protocol, &rf_protocol_handlers[config.model.rf_protocol_type], sizeof(rf_protocol_handlers_t));
    current_rf_protocol.init_function();

    if (current_rf_protocol.enable_binding_function) {
        current_rf_protocol.enable_binding_function();
    }

    if (config.tx.bind_timeout_ms) {
        SYSTICK_set_callback(disable_binding, config.tx.bind_timeout_ms);
    }

    printf("\n\n\n**********\nTransmitter initialized\n");

    LED_on();
    SOUND_play(C5, 100, NULL);

    while (1) {
        WATCHDOG_reset();

        // Check the battery level and update the meter every 100 ms
        if ((milliseconds - last_battery_check_ms) > 100) {
            BATTERY_check_level();
        }

        // If the configuration version is invalid play an error sound every
        // 5 seconds
        if ((milliseconds - last_invalid_config_ms) > 5000) {
            if (config.version != CONFIG_VERSION) {
                MUSIC_play(&song_config_invalid);
            }
        }

        // INPUTS_dump_adc();
        PERSISTENT_STORAGE_background_flash_write();

        WEBUSB_poll();

        // Put the CPU to sleep until an interrupt triggers. This reduces
        // power consumption drastically.
        // Since the systick runs at 1 millisecond period, the main loop sleeps
        // for at most 1 ms.
        __WFI();
    }

    return 0;
}

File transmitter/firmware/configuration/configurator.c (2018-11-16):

#include <stdbool.h>
#include <stdint.h>
#include <stdio.h>
#include <string.h>

#include <config.h>
#include <configurator.h>
#include <inputs.h>
#include <music.h>
#include <systick.h>

#define CONFIGURATOR_ADDRESS_SIZE 5
#define CONFIGURATOR_NUMBER_OF_HOP_CHANNELS 20
#define CONFIGURATOR_CHANNEL 79

#define CONNECTION_TIMEOUT_MS 600

#define TX_FREE_TO_CONNECT 0x30
#define CFG_REQUEST_TO_CONNECT 0x31
#define CFG_READ 0x72
#define CFG_WRITE 0x77
#define CFG_COPY 0x63
#define CFG_DISCONNECT 0x64
#define TX_INFO 0x49
#define TX_REQUESTED_DATA 0x52
#define TX_WRITE_SUCCESSFUL 0x57
#define TX_COPY_SUCCESSFUL 0x43


static const uint8_t configurator_address[] = {0x4c, 0x42, 0x72, 0x63, 0x78};

static bool connected = false;
static configurator_transport_t connected_transport = TRANSPORT_NONE;
static configurator_packet_t packet;

static bool send_response = false;
static configurator_packet_t response_packet;

static uint32_t last_successful_transmission_ms;

static uint8_t session_address[CONFIGURATOR_ADDRESS_SIZE];
static uint8_t session_hop_channels[CONFIGURATOR_NUMBER_OF_HOP_CHANNELS];
static uint8_t session_hop_index;

static bool configuration_changed = false;

// ****************************************************************************
static configurator_packet_t * make_free_to_connect_packet(void)
{
    uint8_t offset;
    uint16_t battery_voltage;

    battery_voltage = INPUTS_get_battery_voltage();

    memcpy(packet.address, configurator_address, sizeof(configurator_address));
    packet.channel = CONFIGURATOR_CHANNEL;

    offset = 0;
    packet.payload[offset] = TX_FREE_TO_CONNECT;
    offset += 1;
    memcpy(&packet.payload[offset], &config.tx.uuid, sizeof(config.tx.uuid));
    offset += sizeof(config.tx.uuid);
    memcpy(&packet.payload[offset], &config.tx.name, sizeof(config.tx.name));
    offset += sizeof(config.tx.name);
    memcpy(&packet.payload[offset], &battery_voltage, 2);
    offset += 2;

    packet.payload_size = offset;

    packet.send_without_ack = true;
    packet.send_another_packet = true;

    return &packet;
}


// ****************************************************************************
static configurator_packet_t * make_connect_response_packet(void)
{
    memcpy(packet.address, config.tx.uuid, CONFIGURATOR_ADDRESS_SIZE);
    packet.channel = CONFIGURATOR_CHANNEL;
    packet.payload[0] = TX_FREE_TO_CONNECT;
    packet.payload_size = 1;
    packet.send_without_ack = false;
    packet.send_another_packet = false;

    return &packet;
}


// ****************************************************************************
static configurator_packet_t * make_info_packet(void)
{
    static uint8_t frame_count = 0;
    uint8_t i;
    uint8_t start_adc_channel;
    uint8_t adc_count;

    memcpy(packet.address, session_address, CONFIGURATOR_ADDRESS_SIZE);
    packet.channel = session_hop_channels[session_hop_index];
    packet.payload[0] = TX_INFO;
    packet.payload_size = 1;
    packet.send_without_ack = false;
    packet.send_another_packet = false;

    // FIXME: send all items that are in use by the transmitter
    switch (frame_count) {
        case 0:
        default:
            frame_count = 1;
            // Send raw ADC value 1..4
            start_adc_channel = 1;
            adc_count = 4;
            break;

        case 1:
            frame_count = 2;
            // Send raw ADC value 5..8
            start_adc_channel = 5;
            adc_count = 4;
            break;

        case 2:
            frame_count = 0;
            // Send raw ADC value 9
            start_adc_channel = 9;
            adc_count = 1;
            break;
    }

    for (i = 0; i < adc_count; i++) {
        uint16_t label = ADC0_RAW + start_adc_channel + i;
        int32_t value = INPUTS_get_raw_adc_value(start_adc_channel + i);
        uint8_t offset = 1 + (i * 6);

        packet.payload[offset + 0] = label >> 0;
        packet.payload[offset + 1] = label >> 8;

        packet.payload[offset + 2] = value >> 0;
        packet.payload[offset + 3] = value >> 8;
        packet.payload[offset + 4] = value >> 16;
        packet.payload[offset + 5] = value >> 24;

        packet.payload_size += 6;
    }

    return &packet;
}


// ****************************************************************************
static configurator_packet_t * make_response_packet(void)
{
    send_response = false;

    memcpy(response_packet.address, session_address, CONFIGURATOR_ADDRESS_SIZE);
    response_packet.channel = session_hop_channels[session_hop_index];
    response_packet.send_without_ack = false;
    response_packet.send_another_packet = false;

    return &response_packet;
}
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

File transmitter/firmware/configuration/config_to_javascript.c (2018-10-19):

#include <stdbool.h>
#include <stdio.h>
#include <stdarg.h>
#include <string.h>

#include <libopencm3/stm32/rcc.h>
#include <libopencmsis/core_cm3.h>

#include <config.h>
#include <configurator.h>
#include <uart.h>


// Source: http://stackoverflow.com/questions/3553296/c-sizeof-single-struct-member
#define membersizeof(type, member) sizeof(((type *)0)->member)


// ****************************************************************************
static void sync_printf(const char *fmt, ...)
{
    va_list ap;

    va_start(ap, fmt);
    vprintf(fmt, ap);
    va_end(ap);

    // Wait for printf to finish ...
    UART_sync();
}


// ****************************************************************************
static void print_separator(void)
{
    for (size_t i = 0; i < 60; i++) {
        putchar('-');
    }
    puts("");
}


// ****************************************************************************
static void dump_javascript_config(void)
{
    size_t elements_per_line = 12;
    size_t remaining = sizeof(config);
    uint8_t *p = (uint8_t *)(&config);

    sync_printf("module.exports = new Uint8Array([\n");

    while (remaining) {
        if (remaining < elements_per_line) {
            elements_per_line = remaining;
        }

        sync_printf("    ");
        for (size_t i = 0; i < elements_per_line; i++) {
            sync_printf("0x%02x, ", *p);
            ++p;
        }

        sync_printf("\n");
        remaining -= elements_per_line;
    }

    sync_printf("]);\n");
}


// ****************************************************************************
void CONFIG_dump_javascript_information(void)
{
    // Member
    const char *m = "            %s: {t: '%s', o: %u, s: %u, c: %u},\n";
    // Member with human readable string
    const char *h = "            %s: {t: '%s', h: '%s', o: %u, s: %u, c: %u},\n";
    // Named type entry
    const char *t = "                '%s': %d,\n";

    print_separator();

    sync_printf("var CONFIG_VERSIONS = {\n"
        "    1: {\n"
        "        // Legend:\n"
        "        // o: offset with the parent structure\n"
        "        // s: element size (number of bytes)\n"
        "        // c: count (number of elements)\n"
        "        // h: human-friendly name (optional)\n"
        "        // t: type\n"
        "        //   'u': unsigned integer\n"
        "        //   'i': signed integer\n"
        "        //   'c': string (Note: may not be 0 terminated if it fills the element)\n"
        "        //   'uuid': 64-bit (8 bytes) universally unique identifier\n"
        "        //   'CONFIG': schema describes the overall config structure\n"
        "        //   'TX': schema describes a transmitter\n"
        "        //   'MODEL': schema describes a model\n"
        "        //   any other value: refers to named elements in TYPES[]\n\n");

    sync_printf("        CONFIG: { t: 'CONFIG', o: 0, s: %u, c: 1,\n", sizeof(config));
    sync_printf("            VERSION: {o: %u, s: %u, c: 1, t: 'u'},\n", offsetof(config_t, version), membersizeof(config_t, version));
    sync_printf("            TX: {o: %u, s: %u, c: 1, t: 's'},\n", offsetof(config_t, tx), membersizeof(config_t, tx));
    sync_printf("            MODEL: {o: %u, s: %u, c: 1, t: 's'},\n", offsetof(config_t, model), membersizeof(config_t, model));
    sync_printf("        },\n\n");


    sync_printf("        TX: { o: %u, s: %u, c: 1, t: 'TX',\n", offsetof(config_t, tx), sizeof(tx_t));

    sync_printf(m, "UUID", "uuid",
        offsetof(tx_t, uuid),
        1,
        membersizeof(tx_t, uuid));

    sync_printf(m, "NAME", "c",
        offsetof(tx_t, name),
        1,
        membersizeof(tx_t, name));

    sync_printf(m, "LAST_CHANGED", "u",
        offsetof(tx_t, last_changed),
        membersizeof(tx_t, last_changed),
        1);

    sync_printf(m, "TAG", "u",
        offsetof(tx_t, tag),
        membersizeof(tx_t, tag),
        1);

    sync_printf(m, "HARDWARE_INPUTS", "s",
        offsetof(tx_t, hardware_inputs),
        sizeof(hardware_input_t),
        membersizeof(tx_t, hardware_inputs) / sizeof(hardware_input_t));

    sync_printf(m, "HARDWARE_INPUTS_PCB_INPUT", "s",
        offsetof(tx_t, hardware_inputs[0].pcb_input),
        membersizeof(tx_t, hardware_inputs[0].pcb_input),
        1);

    sync_printf(m, "HARDWARE_INPUTS_PCB_INPUT_GPIOPORT", "u",
        offsetof(tx_t, hardware_inputs[0].pcb_input.gpioport),
        membersizeof(tx_t, hardware_inputs[0].pcb_input.gpioport),
        1);

    sync_printf(m, "HARDWARE_INPUTS_PCB_INPUT_GPIO", "u",
        offsetof(tx_t, hardware_inputs[0].pcb_input.gpio),
        membersizeof(tx_t, hardware_inputs[0].pcb_input.gpio),
        1);

    sync_printf(m, "HARDWARE_INPUTS_PCB_INPUT_ADC_CHANNEL", "u",
        offsetof(tx_t, hardware_inputs[0].pcb_input.adc_channel),
        membersizeof(tx_t, hardware_inputs[0].pcb_input.adc_channel),
        1);

    sync_printf(m, "HARDWARE_INPUTS_PCB_INPUT_TYPE", "pcb_input_type_t",
        offsetof(tx_t, hardware_inputs[0].pcb_input.type),
        membersizeof(tx_t, hardware_inputs[0].pcb_input.type),
        1);

    sync_printf(m, "HARDWARE_INPUTS_PCB_INPUT_PIN_NAME", "c",
        offsetof(tx_t, hardware_inputs[0].pcb_input.pin_name),
        1,
        membersizeof(tx_t, hardware_inputs[0].pcb_input.pin_name) / sizeof(config.tx.hardware_inputs[0].pcb_input.pin_name[0]));

    sync_printf(m, "HARDWARE_INPUTS_TYPE", "hardware_input_type_t",
        offsetof(tx_t, hardware_inputs[0].type),
        membersizeof(tx_t, hardware_inputs[0].type),
        1);

    sync_printf(m, "HARDWARE_INPUTS_CALIBRATION", "u",
        offsetof(tx_t, hardware_inputs[0].calibration),
        sizeof(config.tx.hardware_inputs[0].calibration[0]),
        membersizeof(tx_t, hardware_inputs[0].calibration) / sizeof(config.tx.hardware_inputs[0].calibration[0]));

    sync_printf(m, "LOGICAL_INPUTS", "s",
        offsetof(tx_t, logical_inputs),
        sizeof(logical_input_t),
        membersizeof(tx_t, logical_inputs) / sizeof(logical_input_t));

    sync_printf(h, "LOGICAL_INPUTS_TYPE", "input_type_t", "Input type",
        offsetof(tx_t, logical_inputs[0].type),
        membersizeof(tx_t, logical_inputs[0].type),
        1);

    sync_printf(h, "LOGICAL_INPUTS_SUB_TYPE", "input_sub_type_t", "Push-button behavior",
        offsetof(tx_t, logical_inputs[0].sub_type),
        membersizeof(tx_t, logical_inputs[0].sub_type),
        1);

    sync_printf(m, "LOGICAL_INPUTS_POSITION_COUNT", "u",
        offsetof(tx_t, logical_inputs[0].position_count),
        membersizeof(tx_t, logical_inputs[0].position_count),
        1);

    sync_printf(h, "LOGICAL_INPUTS_HARDWARE_INPUTS", "u", "Hardware inputs",
        offsetof(tx_t, logical_inputs[0].hardware_inputs),
        sizeof(port_t),
        membersizeof(tx_t, logical_inputs[0].hardware_inputs) / sizeof(port_t));
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

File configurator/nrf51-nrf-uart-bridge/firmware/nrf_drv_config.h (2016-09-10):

#pragma once

// Board definition for WaveShare BLE400 development board

#define NRF_MAXIMUM_LATENCY_US    2000


#define TIMER1_ENABLED              1
#define TIMER1_CONFIG_FREQUENCY     NRF_TIMER_FREQ_1MHz
#define TIMER1_CONFIG_MODE          TIMER_MODE_MODE_Timer
#define TIMER1_CONFIG_BIT_WIDTH     TIMER_BITMODE_BITMODE_16Bit
#define TIMER1_CONFIG_IRQ_PRIORITY  APP_IRQ_PRIORITY_LOW
#define TIMER1_INSTANCE_INDEX       0
#define TIMER_COUNT                 1


#define RTC0_ENABLED                1
#define RTC0_CONFIG_FREQUENCY       1000
#define RTC0_CONFIG_IRQ_PRIORITY    APP_IRQ_PRIORITY_LOW
#define RTC0_CONFIG_RELIABLE        false
#define RTC0_INSTANCE_INDEX         0
#define RTC_COUNT                   1


#define UART0_ENABLED               1
#define UART0_CONFIG_HWFC           NRF_UART_HWFC_DISABLED
#define UART0_CONFIG_PARITY         NRF_UART_PARITY_EXCLUDED
#define UART0_CONFIG_BAUDRATE       NRF_UART_BAUDRATE_115200
#define UART0_CONFIG_PSEL_TXD       9
#define UART0_CONFIG_PSEL_RXD       11
#define UART0_CONFIG_PSEL_CTS       10
#define UART0_CONFIG_PSEL_RTS       8
#define UART0_CONFIG_IRQ_PRIORITY   APP_IRQ_PRIORITY_HIGH
#define UART0_CONFIG_RX_BUFFER_SIZE 512
#define UART0_CONFIG_TX_BUFFER_SIZE 512


#define RNG_ENABLED                 1
#define RNG_CONFIG_ERROR_CORRECTION true
#define RNG_CONFIG_POOL_SIZE        8
#define RNG_CONFIG_IRQ_PRIORITY     APP_IRQ_PRIORITY_LOW

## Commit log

2016-06-13 Initial commit, taking current state from previous repository
    [2016-06-04_Sony800mAh-3.63V-to-shutoff.csv, 2016-06-04_Sony800mAh-3.63V-to-shutoff.ods, 2016-06-05-Sony800mAh-full-to-shutoff.csv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]
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2016-06-19 Define values for battery voltage divider
    [stm32f1-nrf24l01-transmitter.sch]
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2016-06-26 Remove FIXME that are no longer relevant
    [inputs_stm32f103c8t6.c]
2016-06-26 Fix on-open-off switch functionality
    [config.c, inputs.c]
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2016-07-09 Add missing AIL to label_t
    [config_to_javascript.c]
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2016-07-10 Fix EP_R to EP_H
    [config_to_javascript.c]
2016-07-10 Refactoring: we now have a single database holding both model and tx
    Instead of having separate databases for models and transmitters, we
    combined them into one. Entries are referenced by uuid as before,
    which is anyway unique across both models and transmitters.
    Each entry has now the schema attached (compared to the schema being
    attached to the individual database before), so we can still check
    for correct requests.
    The main motivation for this change is that we can now have a
    single_select page, that selects a value out of a C enum, that works
    for both model and transmitter. The UUID and the field are enough
    to let single_select do its job. It does not need to know whether
    the item is a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
2016-07-12 Refactoring of label_t into input_label_t, channel_label_t and src_label_t
    The mixer input can be either a logical input or an output channel.
    Therefore originally we had one label_t list that described
    all possible mixer inputs. We then used subtraction to determine
    whether a mixer input refers to a logical input or an output channel.
    This lead to problems in the UI as now the UI would need information
    about what label_t values are allowed to show. E.g. a mixer destination
    can only be an output channel, while a mixer unit Switch can only
    be a logical input.
    The refactoring now defines separate lists for logical inputs and
    for the output channels. We then created a src_label_t list
    that hol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
    [channels.h, config_to_javascript.c, inputs.c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]
2016-07-12 Implement synchronous printf
    This way we can dump out everything in one go. While this blocks
    program execution, this is no issue since this code is only
    run during development and is not included in the release.
    [config_to_javascript.c]
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2016-07-12 Fix bugs related to recent refactoring
    [config_to_javascript.c, uart.c]
2016-07-12 Fix mixer unit .src fields
    [config.c]
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2016-07-16 Fix onclick being set on both button and parent div
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2016-07-24 Change UUID to 8 bytes
    We need this to fit it in the TX_FREE_TO_CONNECT packets, it also
    shortens the URLs
    [config.c, config_to_javascript.c]
2016-07-24 Fix glitch in progress bar when switching from tx to model
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2016-07-30 Fix back button and show loading indicator when loading a model
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2016-07-31 Implement unique model number and fix back button
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2016-08-06 Fix bug with up/down button in Chrome
2016-08-08 Fix pin names
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2016-08-11 Fix pin names in test data
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2016-08-11 - Config: remove schematic reference, rather have schematic use pin names
    [stm32f1-nrf24l01-transmitter.sch]
2016-08-11 Fix image buttons on Chrome
    event.target points to the image on Chrome, but to the button on Firefox
2016-08-14 nRF51 bridge starting point based on test code
    [discovery-st-link-serial.cfg, st-link-serial.cfg]
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2016-08-17 Remove NRF_LOG, replace with printf
    [main.c, nrf_drv_config.h, rf_protocol.c]
2016-08-21 Implement SLIP protocol including test code
    [bridge.js, rf_protocol.c]
2016-08-21 If SLIP is in use, disable debug messages
    [main.c, rf_protocol.c]
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2016-09-03 Rename configurator folders to common scheme
    [discovery-st-link-serial.cfg]
2016-09-04 Work on fixing the reliability issue with the configurator
    The issue is that the NRF serial port craps out a lot of times.
    No solution available yet.
    [main.c, nrf_drv_config.h, rf_protocol.c]
2016-09-04 Fix UART reliability issue by keeping RF interrupt as short as possible
    [rf_protocol.c]
2016-09-08 Fix issue with all loading messages being visible on device_list
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2016-09-10 Fix duplicate TX_INFO on ADC4 (raw)
    [configurator.c]
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2016-09-11 When downloading a new model set the RF address to a wrong value
    While downloading a new model, the current model may still be
    connected. The new model data may not make sense for the current
    model, but the transmitter already executes the mixer and other
    settings, which may cause the model to run off or do other
    weird things.
    So before we download we set the RF address to a random value,
    which causes the transmitter to send data to the current model.
    We then download the new model. The correct RF address is the last
    part of the model data, so once all model data is set the transmitter
    will receive the correct address and everything goes smooth
2016-09-11 Add Configurator schematics for ESP8266 and nRF51822
    [esp8266-nrf51-configurator.sch]
2016-09-11 Move transmitter schematic into subdirectory
    [stm32f1-nrf24l01-transmitter.kicad_pcb, stm32f1-nrf24l01-transmitter.sch]
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2016-09-12 Add SCAD for the configurator case
    [esp8266-nrf51-configurator-case.scad]
2016-09-12 Tweak case after feedback from print
    [esp8266-nrf51-configurator-case.scad]
2016-09-12 Revert to bare DLG configuration
    [config.c]
2016-09-16 Move battery life test stuff to documentation
    [2016-06-04_Sony800mAh-3.63V-to-shutoff.csv, 2016-06-04_Sony800mAh-3.63V-to-shutoff.ods, 2016-06-05-Sony800mAh-full-to-shutoff.csv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]
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2016-09-16 Remove ST-Link serial number pinning
    [discovery-st-link-serial.cfg, st-link-serial.cfg]
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2016-10-26 Fix x-axis labels of curve points
    [config_to_javascript.c]
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2016-11-04 Move /doc to /documents in order to prepare for Github Pages
    Github pages uses a /docs directory within the project.
    We therefore rename the actual project documents to the longer
    name to make it less confusing
    [2016-06-04_Sony800mAh-3.63V-to-shutoff.csv, 2016-06-04_Sony800mAh-3.63V-to-shutoff.ods, 2016-06-05-Sony800mAh-full-to-shutoff.csv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]
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2016-11-08 Move limit of max packets in transit to ESP
    This way the webapp uses dynamic values, and we only let the ESP
    client limit. Since the problem is in the ESP client, this makes
    sense and help to prevent penalizing other clients (like the future
    Raspberry Pi client, or the nodejs clients)
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2016-11-15 Make ESP Wi-Fi configurable through a text file in the SPIFFS image
    [wi-fi-config.txt]
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2017-01-29 Add annotation to Wi-Fi config
    [wi-fi-config.txt]
2017-02-07 Add altnerate PCB version with NRF module on top of the STM32 module
    [stm32f1-nrf24l01-transmitter-nrf_on_top.kicad_pcb]
2017-02-08 Add buzzer and 3D images
    [stm32f1-nrf24l01-transmitter-nrf_on_top.kicad_pcb]
2017-02-09 Update schematics
    - Convert to KiCAD 4.05
    - Dummy links accross battery connector for routing purpos
    - Dummy connector for speaker
    [stm32f1-nrf24l01-transmitter.sch]
2017-02-09 Tweak design to reduce space and wire links
    [stm32f1-nrf24l01-transmitter-nrf_on_top.kicad_pcb, stm32f1-nrf24l01-transmitter.sch]
2017-02-10 Add mechanical mounting via dummy fiducial
    [stm32f1-nrf24l01-transmitter-nrf_on_top.kicad_pcb]
2017-02-11 Fix switch connector overlapping with charger
    [stm32f1-nrf24l01-transmitter-nrf_on_top.kicad_pcb]
2017-02-11 Add decoupling cap near buzzer
    [stm32f1-nrf24l01-transmitter-nrf_on_top.kicad_pcb]
2017-02-11 Fix transistor footprint, add decoupling cap for buzzer, minor tweaks
    [stm32f1-nrf24l01-transmitter-nrf_on_top.kicad_pcb, stm32f1-nrf24l01-transmitter.sch]
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2017-03-19 Add PCB draft for Airtronics transmitter
    [stm32f1-nrf24l01-transmitter-airtronics.kicad_pcb]
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2017-03-19 Make PCB smaller and annotate
    [stm32f1-nrf24l01-transmitter-airtronics.kicad_pcb]
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2017-03-20 Add analog meter output to electronics
    [stm32f1-nrf24l01-transmitter-airtronics.kicad_pcb, stm32f1-nrf24l01-transmitter.sch]
2017-03-22 Tweak Airtronics PCB design
    [stm32f1-nrf24l01-transmitter-airtronics.kicad_pcb, stm32f1-nrf24l01-transmitter.sch]
2017-03-23 Add info about Airtronics meter
    [stm32f1-nrf24l01-transmitter.sch]
2017-03-26 Remove values on connectors, fix-up meter resistor
    [stm32f1-nrf24l01-transmitter-airtronics.kicad_pcb, stm32f1-nrf24l01-transmitter.sch]
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2017-04-02 Fix and improve analog meter, works well with Airtronics
    [inputs_stm32f103c8t6.c, main.c, meter.c]
2017-04-02 Remove docs, we now use gh-pages branch instead
    [wi-fi-config.txt]
2017-04-02 Use gh-pages instead of docs for spiffs image source.
    The spiffs image is now built in the _build folder, makes it
    easier to maintain
    [wi-fi-config.txt]
2017-04-02 Move /documents back to /docs
    [2016-06-04_Sony800mAh-3.63V-to-shutoff.csv, 2016-06-04_Sony800mAh-3.63V-to-shutoff.ods, 2016-06-05-Sony800mAh-full-to-shutoff.csv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]
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2017-05-13 Convert websocket from binary to text data
    For decoding binary data, we have to use FileReader. FileReader is
    however very slow on Chrome, causing problems. We are therefore
    using hex-encoded strings instead, which is fast on every platform
    [bridge.js]
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2017-05-13 Add openocd files for Orange Pi Zero
    [orangepizero-nrf51.cfg]
2017-05-14 Add case for Orange Pi Zero
    [orangepizero-configurator-case.scad]
2017-05-14 Enlarge button clearance
    [orangepizero-configurator-case.scad]
2017-05-14 Remove ESP8266 based bridge, rather use Orange Pi Zero
    [wi-fi-config.txt]
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2017-05-14 Add openocd config to flash the STM32F103C8T6 with the Orange Pi Zero
    [orangepizero-stm32f1.cfg]
2017-05-14 Move all transmitter related folders into transmitter/
    This tidies up things quite a bit
    [esp8266-nrf51-configurator-case.scad, esp8266-nrf51-configurator.sch, stm32f1-nrf24l01-transmitter-airtronics.kicad_pcb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]
2017-05-14 Replace button monitor with Python version
    Python uses so much less CPU than the nodejs with the onoff module!
    [shutdown-on-button-press.py]
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2017-05-16 Move schematics out of transmitter folder
    [stm32f1-nrf24l01-transmitter-airtronics.kicad_pcb, stm32f1-nrf24l01-transmitter-nrf_on_top.kicad_pcb, stm32f1-nrf24l01-transmitter.kicad_pcb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]
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2017-06-02 Fix /button instead of /a
2018-03-05 Add skeleton for USB dongle
    [usb-dongle.kicad_pcb, usb-dongle.sch]
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2018-08-21 Kicad 5 version and schematic update
    [usb-dongle-2018-08-21-16-41-39.sch, usb-dongle.kicad_pcb, usb-dongle.sch]
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2018-08-25 Fix _makeReadPacket not being referenced to Device
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2018-08-30 Fix device errors
2018-10-28 Tweak issue with PB10/11
    [config.c, configurator.c, inputs.c]
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2018-11-08 Add WebUSB code from usb-dongle
    Not tested, clock may be wrong; WFI may be wrong.
    [main.c]
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2018-11-15 Fix sound and ADC clock
    After changing to 48 MHz the clocks were wrong.
    The sound clock is wrong because when APB1 divider is not 1, then
    the TIM2 clock is actually APB1_clk * 2
    The ADC clock was correctly set in main.c, but wrongly overwritten
    in inputs.c
    [inputs.c, sound.c]
2018-11-16 Fix clock tree, now USB and sounds are working fine
    [main.c]
2018-11-29 Add layout for World Engines variant
    [stm32f1-nrf24l01-transmitter-world-engines.kicad_pcb]
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2019-02-04 Add switch mount for Devo 4
    [devo4-switch-mount.scad]
2019-02-05 Modify Devo4 button mount
    [devo4-switch-mount.scad]
2019-02-06 Add antenna mount for Devo 4
    [devo4-antenna-guide.scad]
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2020-01-20 Update PCB without Blue Pill, but use STM32F103 directly
    [stm32f1-nrf24l01-transmitter-pcb.kicad_pcb, stm32f1-nrf24l01-transmitter-pcb.sch]
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2020-01-28 Fix DRC issue and add keepout area
    [stm32f1-nrf24l01-transmitter-pcb.kicad_pcb]
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2020-02-12 Add Gerber as sent off for fabrication
    NOTE: Component labels are missing from silk screen
    [stm32f1-nrf24l01-transmitter-pcb.kicad_pcb]
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
